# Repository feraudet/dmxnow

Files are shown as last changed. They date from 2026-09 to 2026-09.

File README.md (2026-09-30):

# dmxnow

Wireless DMX and LED strip nodes over ESP-NOW, driven by QLC+ from a Raspberry Pi.
One mains cable per fixture: DMX arrives by radio, the node switches the fixture's
power and drives 4 LED strip channels.

Nœuds DMX et rubans LED sans fil, sur ESP-NOW, pilotés par QLC+ depuis un Raspberry Pi.
Un seul câble secteur par projecteur : le DMX arrive par radio, le nœud coupe
l'alimentation du projecteur et pilote 4 canaux de rubans LED.

| | |
|---|---|
| 🇬🇧 **[Read in English](README.en.md)** | context, the need, use cases, how it works, status |
| 🇫🇷 **[Lire en français](README.fr.md)** | contexte, besoin, cas d'usage, fonctionnement, état du projet |

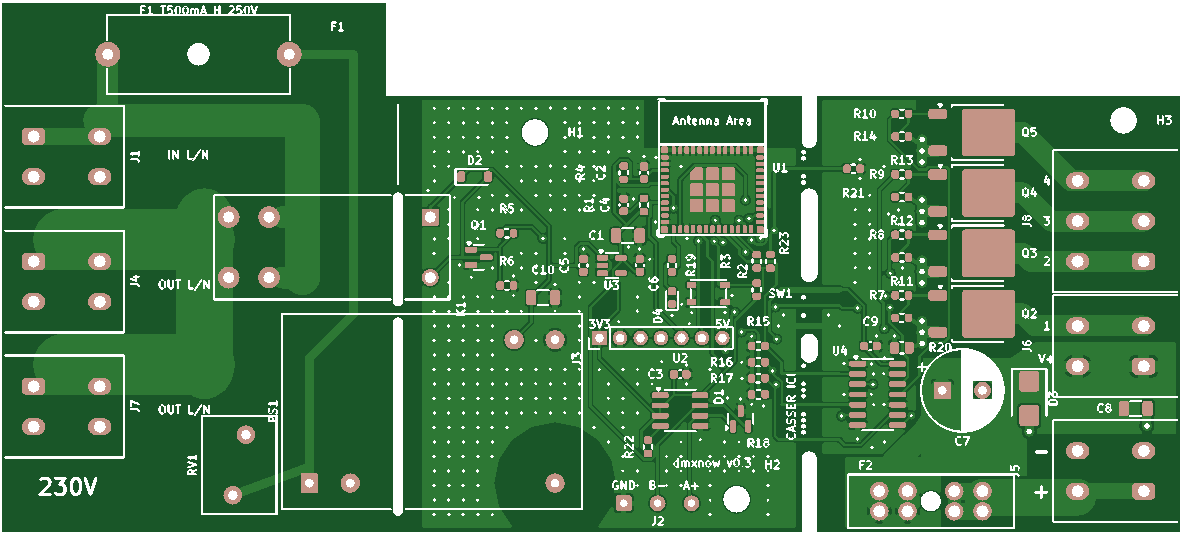
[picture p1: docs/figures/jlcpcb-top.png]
dmxnow board v0.3 (JLCPCB render)


🔴 230 V mains device: read [docs/securite.md](docs/securite.md) first.
Appareil raccordé au 230 V : lire [docs/securite.md](docs/securite.md) avant tout.

Hardware CERN-OHL-S-2.0, software GPL-3.0-or-later: [LICENSE](LICENSE).

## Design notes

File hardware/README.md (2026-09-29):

# dmxnow : matériel

PCB du nœud : 2 couches, cuivre 2 oz, **146 × 54 mm** plus une bande de 47,5 × 11,5 mm
au-dessus de la zone 230 V (porte-fusible F1), séparation à X = 100 mm par fente fraisée
et trois languettes perforées (partie principale « projecteur » 100 × 54 mm, partie
sécable « rubans » 46 × 54 mm). Révision 0.3 (après revue de conception, voir
`REVIEW.md`).

> 🔴 Carte manipulant du 230 V : lire et compléter [REVIEW.md](REVIEW.md) avant toute
> commande ou mise sous tension. Les cotes de K1 (Omron G5RL-1A-E-HR), des borniers WAGO
> 2604 et de PS1 (Mean Well IRM-03-5) ont été relevées sur les fiches constructeur
> ([datasheets/README.md](datasheets/README.md)) ; leur contrôle fait partie de la relecture.

## Contenu

| Fichier | Rôle |
|---|---|
| `gen/design.py` | **Source unique** : composants, empreintes, broches → nets, classes de nets |
| `gen/footprints.py` | Empreintes du projet (`lib/dmxnow.pretty`), cotes et sources dans `DIMS` |
| `gen/sch.py` | Génère `dmxnow.kicad_sch` (schéma à étiquettes, symboles embarqués) |
| `gen/project.py` | Génère `dmxnow.kicad_pro` (classes de nets) et `dmxnow.kicad_dru` (règles 230 V) |
| `gen/pcb.py` | Génère `dmxnow.kicad_pcb` : contour, fentes, languettes perforées, placement, routage 230 V et LED, plans |
| `gen/route.py` | Routage des signaux basse tension par Freerouting, vias d'échappement et de couture GND |
| `gen/fixup.py` | Passe de finition : ferme les liaisons laissées par le routeur (segments directs, vias vers les plans) |
| `gen/vendor.py` | Copie figée des symboles et empreintes KiCad utilisés (`lib/vendor/`) |
| `gen/check.py` | Contrôles de cohérence : netlist du schéma, pastilles du PCB, traversée de la découpe |
| `gen/drc.py` | DRC local via l'API pcbnew (KiCad 7+) |
| `gen/fab.py` | Sorties JLCPCB dans `fab/` |
| `lib/` | Bibliothèques : `dmxnow.pretty`, `Espressif.*` (espressif/kicad-libraries, CC-BY-SA 4.0) |
| `REVIEW.md` | Liste de contrôle de la relecture humaine |

Ne pas éditer les fichiers KiCad à la main : modifier les scripts et régénérer (un
changement manuel serait écrasé et rendrait la CI rouge).

## Régénérer

Prérequis : KiCad ≥ 7 (module Python `pcbnew`, `kicad-cli`), Java ≥ 17, Freerouting
(`FREEROUTING_JAR`, défaut `/opt/freerouting/freerouting.jar`).

```sh
cd hardware
make lib sch project   # empreintes, schéma, projet et règles
make pcb route         # PCB puis routage automatique + finition (~15 min)
make check             # netlist, cohérence PCB, DRC local
make fab               # Gerbers, perçages, BOM/CPL JLCPCB
```

`make pcb` repart de zéro : il faut relancer `make route` ensuite (ou `make reimport`
pour réappliquer la dernière session Freerouting si aucun composant n'a bougé).
Freerouting n'est pas déterministe : deux passages donnent des routages différents,
toujours validés par `make check`.

## Contrôles

- **Local** (KiCad 7) : `make check` (netlist schéma = `design.py`, pastilles PCB =
  `design.py`, seuls PWM1-4, BOARD_SENSE, +5V, GND traversent la découpe et uniquement
  sur les languettes, aucune piste 230 V au-delà de X = 46 mm, aucun via dans une
  pastille CMS, DRC, puis `gen/drc_canary.py` : des défauts injectés doivent déclencher
  chaque règle 230 V, preuve que les règles personnalisées sont chargées).
- **CI** (`.github/workflows/hardware.yml`, KiCad 9) : fichiers générés à jour, ERC, DRC
  avec parité schéma/PCB, sorties de fabrication, rendus 3D dessus/dessous (artefact
  `dmxnow-hardware`).

## Règles d'isolement (🔴)

Définies dans `gen/project.py` → `dmxnow.kicad_dru` :

| Règle | Valeur |
|---|---|
| Cuivre 230 V ↔ tout autre cuivre ou trou | ≥ 6 mm |
| Entre nets 230 V | ≥ 3 mm |
| Pastilles internes de K1 (COM/NO) et de PS1 (AC) | ≥ 2 mm (imposé par le composant) |
| Cuivre 230 V ↔ bord de carte | ≥ 1 mm |

Géométrie : cuivre 230 V à X ≤ 46 mm, basse tension à X ≥ 52 mm, fentes de 1,2 mm à
X = 49 mm sous K1 et PS1, aucun cuivre à moins de 6 mm de la pastille NC de PS1 (rangée
AC du module). Aucun trou de fixation dans la zone 230 V. Le PE ne passe pas
par la carte (WAGO 221-413 dans le boîtier, arbitrage A9).

## Commande JLCPCB

Dossier pas à pas (réglages, remarque, aperçu, achats hors JLCPCB) : [`ORDER.md`](ORDER.md).

- `fab/dmxnow-gerbers.zip` : 2 couches, 1,6 mm, **2 oz**, FR-4 TG ≥ 150.
- Séparation : fente et perforations sont dans les Gerbers (Edge.Cuts, NPTH). JLCPCB
  compte la carte comme **2 designs** : « Different Design = 2 », « Panel by Customer »
  1×1, « Remove order number = Yes ». Remarque de commande :
  « One circuit with an internal routed slot and 3 breakaway tabs carrying traces; deliver and assemble as one piece, do NOT separate. SMT: convey on the straight short edges X=0 and X=146; U1/Q5/R10 are close to the Y=54 edge by design. J3, J2 not populated: keep holes open (no solder fill). J1, J4, J7, J5, J6, J8: wire entry toward board edge; J6 and J8 side by side. RV1: form leads to the PCB holes. F2: press flat before soldering. F1/F2 fuses are not fitted. »
- Assemblage complet (CMS + traversants, PCBA « Standard ») : `fab/bom_jlcpcb_full.csv`
  + `fab/cpl_jlcpcb_full.csv` ; CMS seuls (PCBA « Economic », traversants à la main) :
  `*_smt.csv`. Suffixe `_led` : avec la LED d'état (option A7). Positions et rotations
  converties aux conventions JLCPCB (`gen/fab.py`, `JLC_FIX`) ; contrôler l'aperçu de
  placement à la commande. Références LCSC vérifiées le 2026-09-26 (le WAGO 2604-1105 arrêté est
  remplacé par J6 2604-1102 + J8 2604-1103). La cartouche de F1 (Littelfuse 0215.500MXP) et le fusible de F2
  sont à insérer à la main.
- Composants traversants et hors carte : `fab/bom_full.csv`.

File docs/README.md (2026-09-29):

# Documentation dmxnow (livrable 8.7)

Un réseau DMX sans fil : QLC+ sur un Raspberry Pi envoie de l'Art-Net au démon `dmxnowd`,
qui le transmet par USB à un **dongle** ESP32-C3 ; le dongle diffuse les univers en
ESP-NOW à des **nœuds**. Chaque nœud rend une ligne DMX filaire vers un projecteur,
commute son alimentation 230 V par un relais et, sur la carte entière, pilote quatre
canaux de rubans LED 12/24 V.

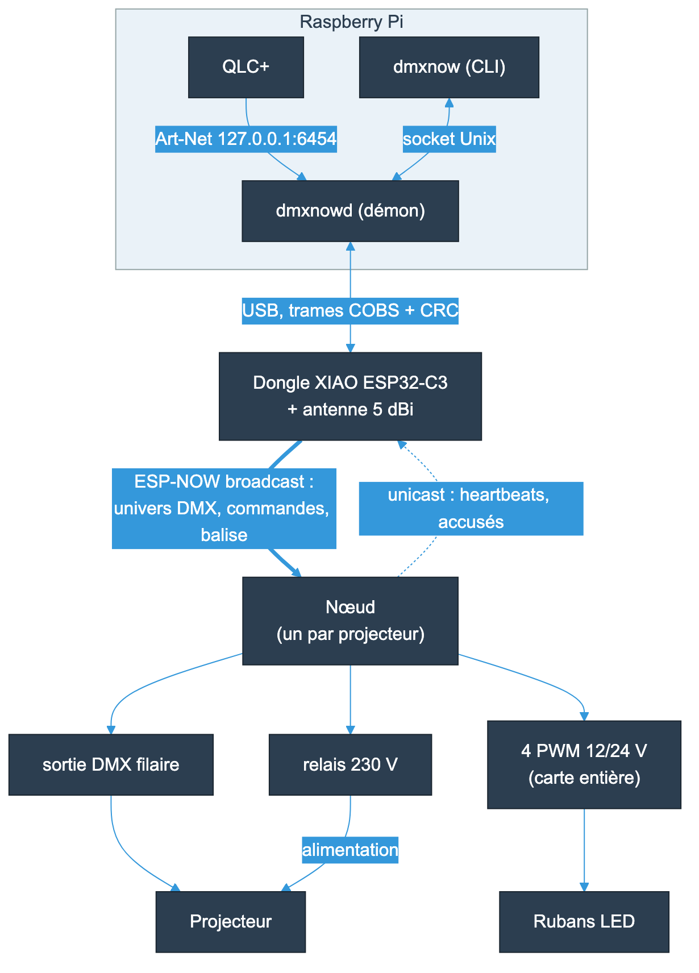
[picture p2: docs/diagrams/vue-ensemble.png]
Vue d'ensemble : QLC+, démon, dongle, nœuds


🔴 **Le nœud est raccordé au secteur.** Lire [securite.md](securite.md) avant toute
manipulation ; ce document et la liste de contrôle qu'il contient demandent une
**relecture humaine obligatoire** par une personne qualifiée.

Carte du nœud

Carte dmxnow v0.3, face top (rendu JLCPCB)

## Ordre de lecture

| # | Document | Pour qui, pour quoi |
|---|---|---|
| 0 | [fonctionnement.md](fonctionnement.md) | **Comprendre** : principes, radio, nœud, relais, rubans, commandes, maintenance, options (illustré) |
| 1 | [securite.md](securite.md) 🔴 | Tout le monde : règles, essais du prototype, **liste de contrôle avant mise sous tension** |
| 2 | [assemblage.md](assemblage.md) | Réception des cartes, fusibles, découpe de la partie rubans, impression et montage du boîtier, dongle |
| 3 | [flash.md](flash.md) | Premier chargement du firmware (nœud par J3, dongle par USB-C), mises à jour OTA |
| 4 | [cablage.md](cablage.md) | Raccordement secteur, DMX, alimentation LED et rubans |
| 5 | [mise-en-service.md](mise-en-service.md) | Pi, QLC+, enrôlement des nœuds, maintenance, dépannage |

Le flash se fait **avant** le câblage secteur : un nœud se programme hors secteur, par
ses pastilles J3 (règle 2 de securite.md).

## Références

| Sujet | Source |
|---|---|
| Exigences, arbitrages, points à valider | [spec/SPEC.md](../spec/SPEC.md), [spec/adr/](../spec/adr/) |
| Protocole radio et série | [spec/PROTOCOL.md](../spec/PROTOCOL.md) |
| Carte, commande JLCPCB, relecture 230 V | [hardware/README.md](../hardware/README.md), [ORDER.md](../hardware/ORDER.md), [REVIEW.md](../hardware/REVIEW.md) 🔴 |
| Boîtiers (nœud, dongle) | [enclosure/README.md](../enclosure/README.md) |
| Firmware, recette sur banc | [firmware/README.md](../firmware/README.md) |
| Démon et CLI | [pi/README.md](../pi/README.md) |

## Vocabulaire

| Terme | Sens |
|---|---|
| Carte entière / partie principale | La carte livrée (146 mm) porte la partie « projecteur » et la partie sécable « rubans » ; cassée, il reste la partie principale (100 mm) |
| Univers | Univers Art-Net (Port-Address 0 à 32767), 512 canaux DMX |
| `net_id` | Numéro de réseau choisi par `install.sh` ; un nœud neuf a `net_id` 0 |
| Enrôlement | Rattacher un nœud neuf au réseau (`dmxnow enroll`) |
| Maintenance | Point d'accès Wi-Fi `dmxnow-<nom>` + page web + OTA sur un nœud |
| TBTS | Très basse tension de sécurité (SELV) : < 60 V DC, isolée du secteur |

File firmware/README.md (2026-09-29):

# Firmware dmxnow

| Dossier | Contenu |
|---|---|
| `common/` | Bibliothèque C++17 sans Arduino : protocole v1 (en-tête, validation, CRC16, COBS), configuration TLV, réassemblage, compteur de pertes, logique du relais, gamma, cadence d'émission, HMAC-SHA256 et anti-rejeu, historique des commandes. Tests natifs. |
| `common/test_vectors.json` | Vecteurs communs (PROTOCOL §9), produits par `common/tools/gen_vectors.py` avec une implémentation Python indépendante ; consommés par les tests C++ et, plus tard, par ceux du démon Pi. |
| `node/` | Firmware du nœud, ESP32-C3-MINI-1, Arduino-ESP32 3.3.12 / ESP-IDF 5.5.5 (pioarduino 55.03.312, épinglé). |
| `dongle/` | Firmware du dongle, Seeed XIAO ESP32-C3 sur l'USB du Pi (même plateforme épinglée). |

## Compiler et tester

```
pip install platformio
cd firmware/common && pio test -e native        # 36 tests (nœud + dongle), -Wall -Wextra -Werror
cd firmware/node && pio run -e node             # firmware.bin (OTA) et firmware.factory.bin
cd firmware/dongle && pio run -e dongle         # XIAO ESP32-C3
python3 firmware/common/tools/gen_vectors.py    # après toute évolution du protocole
```

Derrière un proxy TLS d'entreprise, PlatformIO passe son propre bundle `certifi` et
ignore `REQUESTS_CA_BUNDLE` : ajouter le certificat du proxy à ce bundle plutôt que de
désactiver la vérification.

## Flasher un nœud

- Relier un câble USB aux pastilles **J3** : **5V** (pastille 7), GND, D−, D+.
  **Jamais J3-3V3** (sortie du régulateur, courant inverse non garanti) et jamais avec
  le secteur branché (REVIEW 7.6).
- Maintenir SW1 pendant la mise sous tension : chargeur ROM (mode téléchargement).
- `pio run -e node -t upload`, ou `firmware.factory.bin` à l'adresse 0x0 avec esptool.
- Ensuite : mises à jour par OTA depuis la page de maintenance. La nouvelle image est
  **confirmée au premier paquet radio valide** ; sans paquet dans les 60 s, le chargeur
  revient à l'ancienne. Faire les OTA à portée du dongle.

## Mise en service (nœud neuf)

1. Un nœud neuf a `net_id` = 0 : il n'accepte ni DMX ni rien d'autre que des COMMAND et
   des BEACON, de n'importe quel réseau (enrôlement, PROTOCOL §2.5). Son heartbeat part en
   broadcast avec `net_id` 0.
2. Depuis le Pi : `SET_CONFIG` avec `net_id`, `universe`, `start_address`, `name`,
   `dmx_out_slots` (régler à l'adresse de fin du projecteur, arbitrage A3), puis
   `net_key` (A4) : dès lors, toute commande sauf `IDENTIFY` doit être authentifiée.
3. Sans console : page de maintenance (SW1 ≥ 3 s, ou 3 mises sous tension en moins de 5 s
   chacune), point d'accès `dmxnow-<nom>`, mot de passe `maint_password` (aléatoire au
   premier démarrage, affiché sur la console USB J3 au démarrage et à l'entrée en
   maintenance ; à redéfinir de préférence à l'enrôlement :
   `dmxnow set <nœud> maint_password=…`, 8 à 32 caractères), puis http://192.168.4.1/.

## Comportements (où les trouver)

| Fonction | Spécification | Code |
|---|---|---|
| Validation des paquets dans le callback, copie en file | PROTOCOL §2.5 | `node/src/radio.cpp`, `common/src/protocol.cpp` |
| DMX : break 176 µs par inversion de ligne, MAB 12 µs, 250 kbit/s 8N2, `dmx_out_slots` | SPEC 4.4, A3 | `node/src/dmx_out.cpp` |
| Émission sur événement (≥ 10 ms d'écart) + rafraîchissement 44 Hz | PROTOCOL §4.4 | `common/src/dmx.cpp` (`OutputCadence`) |
| Réassemblage v1, fusion partielle | PROTOCOL §4.2 | `common/src/dmx.cpp` (`Reassembler`) |
| Relais : priorités, niveau ≥ 128, anti-rebond différé, NVS seulement à la commutation | SPEC 4.5 | `common/src/relay.cpp`, `node/src/node.cpp` |
| PWM : LEDC 14 bits à 4882 Hz, déphasage d'un quart de période, gamma, fondu | SPEC 4.6-4.7 | `node/src/pwm_out.cpp`, `common/src/gamma.cpp` |
| PWM à 0 avant tout le reste au démarrage | SPEC 4.7 | `node::setup()` |
| Variante par BOARD_SENSE | EF-07 | `node::setup()` |
| Heartbeat 2 s ± 250 ms, immédiat sur événement | PROTOCOL §5.1 | `node/src/node.cpp` |
| Apprentissage / oubli (30 s) du dongle | PROTOCOL §5.3 | `node/src/node.cpp` |
| Commandes, idempotence (16 derniers `cmd_id`), ACK unicast | PROTOCOL §6 | `node/src/node.cpp`, `common/src/auth.cpp` |
| Authentification HMAC + compteur persistant | PROTOCOL §7, A4 | `common/src/auth.cpp` |
| Balayage des canaux après 60 s sans réseau | SPEC 4.1, A5 | `node/src/node.cpp` |
| SW1 : ≥ 3 s maintenance, ≥ 10 s remise à zéro | SPEC 4.9, A6 | `node/src/node.cpp` |
| LED d'état (option) | SPEC 4.9, A7 | `node/src/node.cpp` |
| Maintenance AP+STA, page web, OTA avec retour arrière | SPEC 4.9 | `node/src/maintenance.cpp` |

## Recette sur banc (SPEC 8.3) : à faire sur les premières cartes

| # | Essai | Moyen | Critère |
|---|---|---|---|
| B1 | Trame DMX : break, MAB, débit, 2 bits de stop, longueur `dmx_out_slots` | Analyseur logique sur DI du SP3485 (IO4) et sur A/B | break ≥ 88 µs (176 visé), MAB ≥ 8 µs (12 visé), 4 µs/bit |
| B2 | Cadence : trame immédiate sur donnée nouvelle, ≥ 10 ms d'écart, 44 Hz sans donnée | Analyseur ; dongle ou émetteur de test | intervalle break-break conforme |
| B3 | Relais : suit le canal (≥ 128), forçage, intervalle minimal 3 s différé, état au démarrage, perte de flux sans effet | Commandes + DMX | SPEC 4.5 points 1 à 5 |
| B4 | PWM : fréquence 4882 Hz, 14 bits, déphasage d'un quart de période entre canaux, gamma, fondu à la mise sous tension | Oscilloscope 4 voies sur IO3/6/7/10 | décalages 51 µs (¼ de 205 µs) |
| B5 | PWM à 0 dès la mise sous tension (pas d'impulsion) | Oscilloscope déclenché sur l'alimentation 5 V | aucune impulsion avant l'initialisation |
| B6 | Perte de flux : dernière trame conservée ; blackout après `loss_blackout_ms` si configuré | Couper le dongle | EF-06 |
| B7 | Maintenance : SW1 3 s, 3 mises sous tension, commande ; réception ESP-NOW maintenue en AP+STA [V-FW-05] ; sortie par page, par SW1, par délai | Téléphone + DMX | le DMX continue d'être rafraîchi |
| B8 | OTA : mise à jour par la page ; retour arrière si aucun paquet valide en 60 s | Deux images | l'ancienne image redémarre |
| B9 | Changement de canal par commande (appliqué 500 ms après l'ACK) ; balayage après 60 s sans réseau | Dongle sur un autre canal | le nœud retrouve le réseau et persiste le canal |
| B10 | Authentification : commande non signée refusée (`AUTH_FAILED`) une fois la clé posée, rejeu refusé, `IDENTIFY` toujours accepté | Démon Pi | PROTOCOL §7 |

## Dongle

- Liaison USB CDC avec le démon (PROTOCOL §8) : trames COBS, CRC16, `seq` par émetteur ;
  `UNIVERSE`, `COMMAND` (remorque d'authentification calculée par le Pi), `DONGLE_CONFIG`
  (persisté en NVS), `PING` → `PONG`, `GET_STATUS` → `STATUS` (aussi toutes les 5 s).
- Émission ESP-NOW **une à la fois** (attente du callback d'émission, garde de 50 ms),
  priorité COMMAND > DMX_DATA > BEACON (1 Hz, même sans univers) ; univers émis sur
  événement (≥ 10 ms d'écart) et rafraîchis à `refresh_hz` (44), arrêtés après
  `hold_timeout` (10 s) sans données du Pi ; mode v1 fragmenté sélectionnable.
- Commandes : ciblées, 5 tentatives (attentes 30, 60, 120, 240 ms puis 50 ms) jusqu'à
  l'ACK de la bonne MAC ; broadcast, 3 émissions à 20 ms puis 1 s de collecte ;
  `CMD_RESULT` au Pi. HEARTBEAT et ACK remontés en `RADIO_RX` (paquet brut) ; les
  heartbeats des nœuds non configurés (`net_id` 0) sont acceptés pour l'enrôlement.
- Sonde de latence : **D10 (GPIO10)** bascule à chaque émission radio (ENF-01).
- Logique testée nativement : `common/src/dongle.cpp`, `common/src/serial.cpp`.

### Recette dongle (SPEC 8.4)

| # | Essai | Critère |
|---|---|---|
| D1 | Latence Art-Net → ligne DMX : QLC+ → démon → dongle (sonde D10) → nœud (analyseur sur IO4) | ≤ budget SPEC §5.1 (≈ 3,3 ms typique en trame courte) |
| D2 | Débit USB : 4 univers à 50 Hz sans perte (`serial_errors`, `coalesced`) [V-FW-04] | aucune erreur série |
| D3 | Pi débranché : univers maintenus 10 s puis BEACON seul | `hold_timeout` |
| D4 | Commande ciblée vers un nœud éteint : 5 tentatives, `CMD_RESULT` = expiré | < 0,5 s |

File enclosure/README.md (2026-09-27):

# Boîtier dmxnow (livrable 8.6)

🔴 **RELECTURE HUMAINE OBLIGATOIRE** : cloison 230 V, accès aux borniers, matériau
(SPEC §4.12, ES-05).

Modèle CadQuery paramétrique (`enclosure.py`), deux variantes :

| Variante | Carte | Encombrement hors tout (parois + bossages + oreilles) | Corps seul |
|---|---|---|---|
| `full` | carte entière (146 × 65,5 mm) | 208 × 88 × 34 mm | 208 × 72 × 34 mm |
| `cut` | partie principale seule (carte cassée) | 150 × 88 × 34 mm | 145 × 72 × 34 mm |

L'objectif ENF-05 (≤ 150 × 65 × 45 mm entière, ≤ 110 × 65 × 45 mm cassée) **n'est pas
tenu en longueur ni en largeur**, voir « Écarts » ci-dessous.

## Fichiers

| Fichier | Rôle |
|---|---|
| `board.json` | Géométrie de la carte (contour, fentes, trous, encombrement et hauteur de chaque composant, points d'appui), **générée** par `hardware/gen/export_board.py` |
| `enclosure.py` | Modèle, vérifications (SPEC §8.6), exports |
| `render.py` | Rendus PNG assemblés (fermé, ouvert) |
| `out/<variante>/*.step` | Pièces en position d'assemblage (CAO) |
| `out/<variante>/*.stl` | Pièces en position d'impression (trancheur) |
| `out/<variante>/assembly_*.png` | Rendus |

```
pip install -r requirements.txt       # CadQuery 2.8
make                                  # vérifie, exporte les deux variantes, rend les PNG
make check                            # vérifications seules
```

Après toute modification du PCB : `cd hardware/gen && python3 export_board.py`, puis
`make` ici.

## Pièces imprimées

| Pièce | Qté | Orientation | Rôle |
|---|-----|---|---|
| `base` | 1 | fond sur le plateau | Fond, parois, cloison 230 V / TBT, supports du PCB, presse-étoupes, sellette de l'étrier, clip du WAGO 221-413, passants de colliers |
| `cover_230v` | 1 | face lisse sur le plateau | 🔴 Couvercle d'accès aux borniers secteur (J1, J4, J7, jonction PE), vissé ; jupe de cloison au-dessus du PCB ; recouvre le bord du couvercle TBT |
| `lid_lv` | 1 | face lisse sur le plateau | Couvercle basse tension, vissé ; guide du poussoir SW1 ; aérations au-dessus des MOSFET (`full`) |
| `lid_lv_light_pipe` | (1) | idem | Variante de `lid_lv` avec le logement du guide de lumière Ø 3 mm au-dessus de D4 (option A7) |
| `clamp_bar` | 3 | rainure sur le plateau | Barres d'étrier (arrêt de traction indépendant du presse-étoupe, ES-05) |
| `sw1_plunger` + `sw1_collar` | 1 + 1 | debout | Poussoir captif de SW1 (A6) : le collier se colle ou s'emmanche sous le tube de guidage |

## Achats

| Article | `full` | `cut` | Note |
|---|---|---|---|
| Presse-étoupe M16 × 1,5 plastique + contre-écrou (serrage 4,5 à 10 mm) | 5 | 3 | Secteur ×3 (H05VV-F 3G1,5 ≈ 8 à 9 mm), rubans ×1, alimentation LED ×1 [V-ENC-01] |
| Presse-étoupe M12 × 1,5 plastique + contre-écrou (serrage jusqu'à 7 mm) | 1 | 1 | Queue DMX (câbles DMX souvent 6 à 6,5 mm, au-delà du PG7) [V-ENC-01] |
| Insert fileté M3 à chaud, Ø 4,0 × 5,7 mm | 16 | 15 | 8 couvercles, 6 étriers, 1 ou 2 PCB |
| Vis M3 × 6 tête cylindrique | 8 | 8 | Couvercles (lamage de 1,2 mm) |
| Vis M3 × 16 | 6 | 6 | Barres d'étrier (pas plus long : la vis toucherait le fond de l'insert avant de serrer) |
| Vis M3 × 6 + rondelle isolante | 2 | 1 | PCB (H2, H3) |
| WAGO 221-413 | 1 | 1 | Jonction des trois PE (A9) |
| Guide de lumière Ø 3 mm (PMMA) | option | option | A7 |
| Filament **ABS-FR ou PC-ABS-FR UL94 V-0** | ~150 g | ~115 g | Pièces pleines (masse volumique 1,2) [V-ENC-02] 🔴 |

## Impression

- Matériau **UL94 V-0 (au minimum V-1)** : PETG et ABS standard (HB) interdits pour une
  enveloppe contenant du secteur (SPEC §4.12). Conserver la fiche technique du filament
  et l'épaisseur à laquelle le classement est donné ; l'épaisseur des parois (2,5 mm) doit
  être au moins égale à celle-ci [V-ENC-02].
- Parois pleines : **100 % de remplissage** (ou périmètres suffisants pour remplir les 2,5 mm).
- Imprimante fermée, buse 240 à 260 °C, plateau 100 °C (ABS-FR) ; bordure (« brim ») sur
  le fond (R-15).
- Aucun support nécessaire : trous horizontaux en goutte d'eau tronquée, porte-à-faux ≤ 45°.

## Montage

1. Inserts à chaud dans les bossages (couvercles), la sellette (étriers) et les plots H2/H3.
2. Clipser le WAGO 221-413 dans son logement (chambre de gauche).
3. Poser le PCB : l'ergot imprimé traverse H1, les languettes de la cloison entrent dans
   les fentes d'isolement ; visser H2 (et H3 sur la carte entière).
4. Presse-étoupes : écrous tournés méplat contre méplat (les trois écrous secteur sont
   espacés de 21,5 mm pour 22 mm sur angles).
5. Câbles secteur : gaine serrée par le presse-étoupe **et** par la barre d'étrier ; PE
   au 221-413 d'abord, puis L et N aux WAGO 2604 ; conducteurs sans tension mécanique.
6. Poussoir SW1 : glisser le poussoir dans le tube par-dessous, emmancher le collier.
7. Visser le couvercle TBT, puis le couvercle 230 V (il recouvre le bord du couvercle TBT).

## Choix de conception (justifications)

- **Chambres de câblage** : un contre-écrou de presse-étoupe M16 (22 mm sur angles) ne peut
  pas traverser le plan du PCB ; les WAGO étant en bord de carte, les presse-étoupes sont
  dans des chambres aux extrémités. Côté secteur, la chambre (34 mm) contient l'écrou,
  l'étrier (ES-05) et la zone d'épanouissement des conducteurs avec le 221-413 (A9).
- **Cloison 230 V / TBT** 🔴 : une cloison continue du fond au couvercle est impossible sur
  la ligne X = 49 mm, que K1 et PS1 enjambent. Elle est réalisée en trois parties :
  (1) paroi du fond, pleine hauteur hors carte (bande de F1) et sous la carte ailleurs ;
  (2) languettes de 0,8 mm qui remplissent les fentes d'isolement du PCB ; (3) jupe du
  couvercle 230 V au-dessus de la carte, qui descend à 0,5 mm du PCB et passe à 0,5 mm
  au-dessus de K1 et PS1 (leurs boîtiers assurent l'isolement à cet endroit). Le couvercle
  230 V recouvre le bord du couvercle TBT (« lèvre »).
- **H1 sans métal** : H1 est à 13,5 mm de la zone d'antenne ; il reçoit un ergot imprimé
  et un tube presseur du couvercle au lieu d'un insert (SPEC : rien de métallique à moins
  de 15 mm de l'antenne). Pour la même raison, la variante `cut` n'a pas de vis dans le
  coin supérieur droit.
- **Points d'appui** : plots sous le PCB et presseurs des couvercles aux points calculés
  par `export_board.py` (≥ 3 mm des pastilles, ≥ 2,5 mm des composants).
- **Aérations** (R-08) : fentes dans le couvercle TBT au-dessus de Q2 à Q5 et entrées
  basses dans la paroi, sous la partie sécable. Aucune ouverture dans le couvercle 230 V.
- **DMX en M12** plutôt que PG7 : plage de serrage jusqu'à 7 mm (câbles DMX 6 à 6,5 mm).

## Écarts et points à valider

| Point | État |
|---|---|
| ENF-05 (≤ 150 × 65 × 45 / ≤ 110 × 65 × 45) | **Non tenu** : 208 × 72 × 34 (corps, `full`), 145 × 72 × 34 (`cut`). Longueur : chambres de presse-étoupes + étriers (ES-05). Largeur : bande de F1 (carte de 65,5 mm) + parois. Hauteur tenue. |
| Hauteurs de F2 avec fusible (21 mm), C7 (17,5 mm), RV1 (16 mm) | Estimées, à mesurer sur les pièces [V-ENC-03] |
| Presse-étoupes : diamètres de câbles, plages de serrage, dimensions des contre-écrous | [V-ENC-01] |
| Filament V-0, épaisseur certifiée | [V-ENC-02] 🔴 |
| Jupe de cloison au-dessus de K1 / PS1 (0,5 mm) : suffisante avec les boîtiers des composants ? | Relecture humaine 🔴 |
| Tenue du PCB : 1 vis (H2) + ergot H1 + appuis ; la partie sécable (`full`) ajoute H3 | À éprouver sur prototype (effort de levier des WAGO) |

## Vérifications automatiques (`make check`)

- solides valides (`isValid()`) et fermés ;
- aucune intersection des pièces avec le PCB ni avec l'enveloppe des composants
  (empreinte × hauteur) ;
- carte + 0,5 mm contenue dans la cavité ;
- parois ≥ 2,5 mm, fond et couvercles ≥ 2,0 mm ;
- contre-écrous des presse-étoupes : hors du PCB, des composants, dans la hauteur ;
  ouverture en goutte d'eau couverte par l'écrou ;
- aucun métal (inserts, vis) à moins de 15 mm de la zone d'antenne.

## Boîtier du dongle (`dongle_case.py`)

Boîtier de la **Seeed XIAO ESP32-C3** (référence 113991054) avec une **antenne dipôle
vissée** sur une embase RP-SMA, retenu à la place d'une clé USB-A toute faite pour garder
une antenne externe (SPEC 4.10). Encombrement : **59 × 39 × 13 mm**, oreilles comprises
(corps 48 × 25 × 13 mm).

Achats (Kiwi Electronics, 2026-09-27) :

| Article | Code | Note |
|---|---|---|
| Seeed XIAO ESP32C3 | SS-113991054 | |
| Câble **RP-SMA** vers u.FL, 14 cm, embase à visser | KW-1518 | pas le « SMA to u.FL » : SMA et RP-SMA ne se connectent pas |
| Antenne dipôle 2,4 GHz **RP-SMA** 5 dBi | ANT-24GHZ-5DBI | rayonne surtout à l'horizontale : la tenir verticale |

| Pièce | Orientation | Rôle |
|---|---|---|
| `out/dongle/tray` | fond sur le plateau | Ouverture USB-C avec lamage pour la fiche, nervures et butée du XIAO, trou Ø 6,6 mm de l'embase RP-SMA dans une paroi de 2,5 mm, place pour lover le câble, oreilles pour un collier |
| `out/dongle/lid` | face gravée sur le plateau | Lèvre à clipser (échancrée au-dessus de l'embase), deux appuis sur les bords du PCB |

- **Matériau** : PETG ou PLA (5 V USB seulement, pas de secteur : pas d'exigence V-0).
- **Montage** : XIAO poussé contre la paroi USB-C ; embase RP-SMA passée de l'intérieur
  dans la paroi opposée, rondelle et écrou à l'extérieur ; câble clipsé sur le
  connecteur U.FL du XIAO, lové en une boucle d'au moins 18 mm de diamètre ; couvercle
  clipsé ; antenne vissée à la main.
- **Utilisation** : câble USB-C vers USB-A sur le Pi, avec une rallonge ; dongle suspendu
  par son câble USB (ou par un collier dans une oreille), antenne vers le bas, verticale.
- **Flash** : par l'USB-C, sans ouvrir le boîtier (l'USB Serial/JTAG de l'ESP32-C3 passe
  en mode téléchargement tout seul) ; les boutons BOOT et RESET ne sont pas accessibles.

Cotes à confirmer sur les pièces reçues [V-ENC-04] : épaisseur du PCB (1,2 mm prévu),
dépassement de l'USB-C au-delà du bord (1,0 mm prévu), hauteur des composants
(3,4 mm prévu), corps de l'embase RP-SMA côté intérieur (Ø 9,4 × 9 mm prévu), filetage
1/4"-36 (trou Ø 6,6 mm). Ce sont des paramètres en tête de `dongle_case.py`.

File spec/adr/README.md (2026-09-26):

# Architecture Decision Records

Format : Statut, Contexte, Décision, Conséquences, Alternatives écartées.

Les ADR 0001 à 0010 reprennent les décisions de la section 3 du cahier des charges. Les ADR 0011 à 0015 sont issus de la spécification ; 0011, 0014 et 0015 ont été tranchés par arbitrage le 2026-09-25.

| ADR | Titre | Statut |
|-----|---|---|
| [0001](0001-transport-esp-now.md) | Transport radio ESP-NOW | Accepté (cahier des charges, décision 1) |
| [0002](0002-regie-pi-dongle.md) | Régie Raspberry Pi + QLC+ + dongle XIAO ESP32-C3 | Accepté (décision 2) |
| [0003](0003-microcontroleur-esp32-c3-mini-1.md) | Microcontrôleur ESP32-C3-MINI-1 | Accepté (décision 3) |
| [0004](0004-alimentation-isolee.md) | Alimentation interne isolée Mean Well IRM-03-5 | Accepté (décision 4 amendée par A1) |
| [0005](0005-relais-g5rl.md) | Relais de coupure Omron G5RL-1A-E-HR | Accepté (décision 5, amendée) |
| [0006](0006-rubans-alim-externe-pwm.md) | Rubans LED : alimentation externe, 4 PWM côté masse | Accepté (décision 6) |
| [0007](0007-pcb-secable.md) | PCB unique sécable (languettes perforées) | Accepté (décision 7, amendée) |
| [0008](0008-borniers-wago-2604.md) | Borniers WAGO série 2604 | Accepté (décision 8) |
| [0009](0009-relais-par-canal-dmx.md) | Commande du relais par un canal DMX | Accepté (décision 9) |
| [0010](0010-boitier-imprime-3d.md) | Boîtier imprimé 3D paramétrique | Accepté (décision 10) |
| [0011](0011-esp-now-v2-trame-unique.md) | ESP-NOW v2, un univers par paquet, plateforme pioarduino | Accepté (arbitrage A8, 2026-09-25) |
| [0012](0012-liaison-serie-cobs.md) | Liaison série Pi ↔ dongle encadrée COBS + CRC16 | Accepté (validation de la spec, 2026-09-25) |
| [0013](0013-commandes-broadcast-ack.md) | Commandes en broadcast avec acquittement applicatif | Accepté (validation de la spec, 2026-09-25) |
| [0014](0014-trames-dmx-evenement.md) | Émission DMX sur événement et longueur de trame configurable | Accepté (arbitrage A3 : défaut 512, 2026-09-25) |
| [0015](0015-authentification-commandes.md) | Authentification des commandes par HMAC tronqué | Accepté (arbitrage A4, 2026-09-25) |

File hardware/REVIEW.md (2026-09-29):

# Relecture humaine du PCB dmxnow

> 🔴 **RELECTURE HUMAINE OBLIGATOIRE avant toute commande et toute mise sous tension.**
> Ce PCB a été conçu et routé par script. Les contrôles automatiques (ERC, DRC avec
> règles 230 V personnalisées, cohérence netlist) ne remplacent pas la relecture d'une
> personne qualifiée en électronique de puissance et en sécurité électrique.

Cocher chaque ligne, noter le nom du relecteur et la date. Tout point non conforme
bloque la commande.

Relecteur : ____________________  Date : ____________  Révision PCB : 0.3

## 1. Empreintes (bloquant)

Les cotes de K1, des WAGO 2604 et de PS1 ont été relevées sur les fiches constructeur
(liste et liens : `datasheets/README.md`) et sont centralisées dans `gen/footprints.py`
(dictionnaire `DIMS`, avec la page source). Les confronter aux fiches et, idéalement, à
une pièce réelle posée sur une impression 1:1 du PCB.

| Réf. | Composant | Cotes relevées | Source | OK |
|---|---|---|---|----|
| K1 | Omron G5RL-1A-E-HR DC5 (LCSC C113250) | Bobine 1/8 → A1 (0 ; 0) et A2 (7,5 ; 0), COM 3/6 → 13 en (0 ; 20) et (7,5 ; 20), NO 4/5 → 14 en (0 ; 25) et (7,5 ; 25), perçage 1,3 mm, corps 29,0 × 12,7 × 15,7 mm max. Bobine 80 mA / 62,5 Ω, isolation renforcée 8 mm / 10 kV. **Ne pas accepter de G5RL-U1A-E (bistable).** | Catalogue Omron G5RL p. 5 | ☐ |
| J1, J4, J7, J5, J6 | WAGO 2604-1102 (LCSC C3309286) | Pas 5,0 mm, 2 broches par pôle à 8,2 mm, perçage 1,4 mm (fiche : 1,3 +0,1 ; tolérance JLCPCB −0,08), broche 0,8 × 1 mm, pastilles 2,0 × 2,8 mm, corps 16,3 mm (broche avant à 5,2 mm de la face d'entrée, arrière à 2,9 mm du dos), levier 2,9 mm en saillie, largeur 12,4 mm. Le corps dépasse le bord du PCB de 1,4 mm (J1, J4, J7) et 0,7 mm (J5, J6). | Fiche WAGO 2604-1102 p. 2 | ☐ |
| J6, J8 | WAGO 2604-1102 (C3309286) + 2604-1103 (C3309758) | Même série ; le 2604-1105 (5 pôles) est arrêté. Deux blocs côte à côte : 7,4 mm mini entre broches voisines (L = (n − 1) × 5 + 7,4 mm), 8,0 mm au PCB (CH1 y 28,5 → CH2 y 20,5). | Fiche WAGO 2604-1102 p. 2 ; fiche 2604-1103 | ☐ |
| PS1 | Mean Well IRM-03-5 (LCSC C6969425) | Empreinte KiCad `Converter_ACDC_MeanWell_IRM-03-xx_THT` conforme : AC/L (1), AC/N (3) à 5,08 mm, NC (5) à 30,48 mm, −Vo (14) et +Vo (16) à 17,78 mm, broches Ø 0,6 mm, corps 37 × 24 × 15 mm. | Fiche IRM-03 (2025-08-08) p. 4 | ☐ |
| F1 | Support Schurter 0031.8201 (LCSC C3204125) + cartouche Littelfuse 0215.500MXP (T500 mA H, céramique, 1500 A sous 250 V AC, LCSC C142839, à insérer à la main) | Empreinte KiCad `Fuseholder_Cylinder-5x20mm_Schurter_0031_8201_Horizontal_Open` : broches à 22,5 mm, ergot NPTH de 2,7 mm. Vérifier sur la fiche Schurter. Support ouvert : pièces nues sous 230 V dans le compartiment secteur. | Schurter | ☐ |
| RV1 | 10D561K (LCSC C113236, HEL série 10D) | Empreinte du projet `RV_Disc_D12mm_T9mm_P7.5mm_Drill1.1` : perçage 1,1 mm (pattes 0,8 ± 0,1 mm ; le 0,8 mm de KiCad était trop juste), corps jusqu'à 9 mm d'épaisseur (fiche, rangée 430-560 V). Vérifier l'épaisseur réelle de la pièce livrée. | Fiche HEL 10D | ☐ |
| PS1 (trous) | IRM-03-5 | Empreinte du projet `Converter_ACDC_MeanWell_IRM-03-xx_THT_Drill1.0` : perçages 1,0 mm (broches Ø 0,6 ± 0,1 mm ; les 0,76-0,8 mm de KiCad étaient trop justes avec la tolérance JLCPCB), mêmes positions et pastilles. | Fiche IRM-03 p. 4 | ☐ |
| U1 | ESP32-C3-MINI-1 | Empreinte officielle Espressif (kicad-libraries), zone d'exclusion d'antenne incluse. Vérifier la version de l'empreinte. | Espressif | ☐ |
| F2 | Porte-fusible ATO | Empreinte KiCad Littelfuse FLR 178.6165 ; vérifier l'intensité admissible (≥ 20 A) et la disponibilité. | Littelfuse | ☐ |

Si une cote diffère : corriger `DIMS`, relancer `make lib pcb route check fab`.

## 2. Isolement 230 V / basse tension 🔴

| # | Point | Référence | OK |
|---|---|---|----|
| 2.1 | Toute pièce de cuivre 230 V (nets L_IN, L_SW, N, L_PSU) est à X ≤ 46 mm ; tout cuivre basse tension à X ≥ 52 mm (6 mm). Vérifié par la règle DRC `mains_to_low_voltage` et par `check.py pcb` ; contrôler visuellement sur les Gerbers. | SPEC 4.8.2 | ☐ |
| 2.2 | Fentes de 1,2 mm à bouts arrondis à X = 49 mm sous K1 (Y 12-26) et sous PS1 (Y 27,5-52), entre broches AC et DC de PS1 et entre contacts et bobine de K1. | SPEC 4.8.2 | ☐ |
| 2.3 | Distance bobine-contacts de K1 (interne au relais) ≥ distance requise pour l'isolation renforcée : la fiche Omron annonce une isolation renforcée, 8 mm dans l'air et en ligne de fuite, 6000 V AC, choc 10 kV (à confronter à IEC 62368-1, V-HW-11). | V-HW-03 | ☐ |
| 2.4 | Isolation entrée-sortie de PS1 certifiée (IEC/UL 62368-1) : marquage d'homologation présent sur la pièce achetée. | V-HW-09 | ☐ |
| 2.5 | Aucun plan de masse, via, piste ou trou métallisé basse tension dans la zone 230 V, sur les deux faces. | SPEC 4.8.2 | ☐ |
| 2.6 | Aucun trou de fixation dans la zone 230 V (une vis métallique annulerait l'isolement). | design.py | ☐ |
| 2.7 | Ligne de découpe (X = 100 mm, fente + 3 languettes perforées) : aucun cuivre 230 V à moins de 4 mm, aucun composant à moins de 4 mm ; seuls PWM1-4, BOARD_SENSE, +5V et GND la traversent, sur les languettes. | SPEC 4.8.4, `check.py pcb` | ☐ |
| 2.8 | Distances entre nets 230 V ≥ 3 mm, sauf exceptions acceptées : pastilles COM/NO de K1 (2,4 mm, fixées par le relais) et broches AC de PS1 (2,93 mm, fixées par le module). Règle `mains_pad_to_pad_inside_components`, limitée aux pastilles de K1 et de PS1. | SPEC 4.8.2 | ☐ |
| 2.10 | Broche 5 (NC) de PS1 : elle est sur la rangée AC du module ; traitée comme primaire : aucun cuivre à moins de 6 mm du bord de la pastille (règle DRC `ps1_nc_pin`, zone interdite `ps1_nc_keepout`). Confirmer auprès de Mean Well qu'elle n'est reliée à rien (ou mesurer : continuité et essai diélectrique). | SPEC 4.3 | ☐ |
| 2.11 | F1 : fusible céramique à haut pouvoir de coupure (1500 A) ; ne jamais le remplacer par un fusible en verre (35 A). | SPEC 4.3 | ☐ |
| 2.9 | Le PE ne passe pas par le PCB : les trois conducteurs PE sont réunis par un WAGO 221-413 dans le compartiment 230 V du boîtier (arbitrage A9). | SPEC 4.12 | ☐ |

## 3. Chemins de puissance

| # | Point | Référence | OK |
|---|---|---|----|
| 3.1 | Chemin de charge L_IN → K1 → L_SW : L_IN 4 à 4,3 mm sur les deux faces ; L_SW en doigts de 7,4 mm et bus de 7 mm sur la face avant. Col de 1,9 mm sur ≤ 8 mm aux broches des borniers (imposé par le pas de 5 mm). Juger l'échauffement à 16 A. | SPEC 4.8.3, A2 | ☐ |
| 3.2 | N : bus de 7,1 mm et doigts de 3,4 à 4 mm en face arrière ; col de 3,4 mm sur ~8 mm entre J1 et le bus (~30 °C à 16 A selon IPC-2221, à mesurer au thermocouple). Juger l'échauffement à 16 A (estimation IPC-2221 : ≤ 10 °C sur le bus, ~25 °C sur les cols). | SPEC 4.8.3 | ☐ |
| 3.3 | Branche L_PSU / N vers PS1 et RV1 : 1 mm (courant < 50 mA, protégée par F1). | - | ☐ |
| 3.4 | Partie rubans : VLED en plan (face avant), GND_LED en plan (face arrière), VLED_IN 4,5 mm, canaux 2,5 mm (6 A). | SPEC 4.6 | ☐ |
| 3.5 | Sources des MOSFET (AOD2610E, 60 V) reliées au plan GND_LED par 3 vias de 0,6 mm chacune ; vérifier la capacité (≈ 4 à 6 A par MOSFET). | - | ☐ |
| 3.7 | F2 : fusible ATO chargé à ≤ 80 % de son calibre en continu (20 A pour ≤ 16 A, sinon 25 A ; support 30 A). Polarité de J5 marquée « + / − » : une inversion met D3 en court-circuit. VLED ≤ 28 V. | SPEC 4.6, V-HW-08 | ☐ |
| 3.8 | Courant d'appel des charges sur J4/J4b ≤ ~80 A crête (G5RL-1A-E-HR : 100 A) : mesuré sur les charges réelles. | V-SYS-01 | ☐ |
| 3.6 | GND logique et GND_LED reliées en un seul point : R20 (0 Ω 0805) près de U4. BOARD_SENSE relié à GND par R21 (0 Ω) sur la partie sécable. Plans : GND logique (deux faces, X 100-113) et GND_LED (face arrière, X ≥ 113) séparés. | SPEC 4.8.4 | ☐ |

## 4. Basse tension

| # | Point | OK |
|---|---|----|
| 4.1 | Antenne de U1 en bord de carte, aucune piste, via ni plan dans la zone d'exclusion (règle `antenna_keepout`), rien de métallique au-dessus dans le boîtier. | ☐ |
| 4.2 | Découplage : C2 (100 nF) contre la broche 3V3 de U1 ; C1 (47 µF) à ~17 mm de piste (0,2 mm de large, ~20 mΩ, ~20 nH : acceptable à 0,45 A crête, à confirmer par une mesure de l'ondulation pendant l'émission Wi-Fi) ; C3 contre U2 ; C9 contre U4. Les pistes +5V/+3V3 routées font 0,2 mm (Freerouting n'applique pas la classe PWR). | ☐ |
| 4.3 | Pull-ups de démarrage R2 (IO9), R3 (IO8), R4 (IO2), RC d'EN (R1, C4). R15-R18 4,7 kΩ (GPIO6 a une résistance de tirage interne au reset), R22 10 kΩ sur DMX_TX, R23 100 kΩ sur BOARD_SENSE. | ☐ |
| 4.4 | SW1 accessible par le poussoir du couvercle ; J3 accessible couvercle basse tension ouvert. | ☐ |
| 4.5 | Échauffement de U3 (AP2112K) : cuivre suffisant autour de la broche GND (plan). | ☐ |
| 4.6 | Routage automatique (Freerouting) : longueur et aspect des pistes USB (D-/D+) acceptables pour la programmation. | ☐ |
| 4.7 | Plan de masse : la face arrière porte encore ~280 mm de pistes basse tension (PWM4 et RELAY_CTRL surtout) qui la découpent par endroits ; chaque pastille CMS de masse a son via. Juger la qualité du retour de masse sous U1 (radio) et sous le chemin DMX. | ☐ |

## 5. Fabrication

| # | Point | OK |
|---|---|----|
| 5.1 | JLCPCB : 2 couches, 1,6 mm, **cuivre 2 oz**, FR-4 TG ≥ 150, finition HASL sans plomb ou ENIG. | ☐ |
| 5.2 | Séparation : fente fraisée et trous de perforation inclus dans les Gerbers (Edge.Cuts, NPTH). Préciser en remarque de commande : « single design, internal routed slot with breakaway tabs, do not separate ». JLCPCB la compte comme **2 designs** : commander avec « Different Design = 2 », « Panel by Customer » 1×1. Remarque de commande complète : « One circuit with an internal routed slot and 3 breakaway tabs carrying traces; deliver and assemble as one piece, do NOT separate. SMT: convey on the straight short edges X=0 and X=146; U1/Q5/R10 are close to the Y=54 edge by design. J3, J2 not populated: keep holes open (no solder fill). J1, J4, J7, J5, J6, J8: wire entry toward board edge; J6 and J8 side by side. RV1: form leads to the PCB holes. F2: press flat before soldering. F1/F2 fuses are not fitted. » | ☐ |
| 5.3 | Fentes d'isolement de 1,2 mm (bouts arrondis) présentes sur le calque Edge.Cuts. | ☐ |
| 5.4 | BOM et CPL (`fab/*_full.csv` pour CMS + traversants, `*_smt.csv` pour CMS seuls) : références LCSC vérifiées le 2026-09-26 (revérifier le stock, en particulier 2604-1103 pour J8). Rotations et centres convertis aux conventions JLCPCB (`fab.py`, `JLC_FIX`) ; F1 (support Schurter) vérifié sur l'empreinte EasyEDA C3204125 ; rotations des composants à contrôler dans l'aperçu JLCPCB. | ☐ |
| 5.5 | Composants traversants (WAGO, K1, PS1, F1, RV1, F2, C7) soudés à la main ou en assemblage traversant. | ☐ |

## 6. Essais du premier prototype (personne équipée et qualifiée)

1. Inspection visuelle, continuité, absence de court-circuit L/N, L/basse tension, N/basse tension.
2. Essai diélectrique secteur ↔ basse tension (toutes broches TBT reliées) : 3 kV AC ou
   4,2 kV DC pendant 60 s, sans claquage.
3. Première mise sous tension derrière un transformateur d'isolement et un disjoncteur
   différentiel 30 mA, charge résistive.
4. Essai de charge : 10 A pendant 1 h, relevé thermique (pistes, relais, borniers) ;
   essai de courte durée à 16 A.
5. Commutation d'une alimentation LED réelle (courant d'appel), 1000 cycles.

## 7. Commande et montage

| # | Point | OK |
|---|---|----|
| 7.1 | J6 + J8 (2604-1102 + 2604-1103, remplaçant le 2604-1105 arrêté) sont dans les fichiers JLCPCB : vérifier dans l'aperçu que les deux blocs sont côte à côte et orientés comme J5. | ☐ |
| 7.2 | RV1 : l'empreinte JLCPCB de C113236 écarte les pattes de 6 mm latéralement (la nôtre 1,63 mm, pas de 7,5 mm identique) : JLCPCB mettra les pattes en forme, vérifier l'aperçu. | ☐ |
| 7.3 | Languettes de séparation : ~15 mm de FR-4 plein au total sur la ligne de rupture (les trous s'interrompent au droit des pistes) ; prévoir scie ou pince coupante plutôt qu'une rupture à la main. | ☐ |
| 7.4 | Mise en route : démarrage à froid répété, ligne DMX terminée par 120 Ω, à la tension secteur mini et maxi (limite de courant repliée de l'AP2112K) ; F1 face à l'appel de courant de PS1. | ☐ |
| 7.5 | Rubans : charge totale ≤ 16 A en continu avec le fusible F2 de 20 A (≤ 80 %) ; polarité de J5 (une inversion avec une alimentation limitée en courant fait chauffer D3 sans fondre F2). | ☐ |

| 7.6 | Programmation hors secteur : alimenter par **J3-5V** (pastille 7, entrée de U3), jamais par J3-3V3 (sortie de U3, courant inverse non garanti) ; ne pas alimenter J3-5V secteur branché. | ☐ |
| 7.7 | Bornier WAGO : sens d'insertion (levier côté bord de carte, entrée des fils vers l'extérieur) à contrôler sur l'aperçu JLCPCB ; F2 (porte-fusible ATO conçu pour 1,5 mm) plaqué avant soudure ; trous de J2 et J3 laissés ouverts. | ☐ |
| 7.8 | Remarque de commande : voir 5.2 (2 designs, convoyage par les bords courts X=0 / X=146, pièce unique non séparée). | ☐ |

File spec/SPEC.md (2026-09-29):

# dmxnow : Spécification

Statut : **v1.0, validée le 2026-09-25** (arbitrages A1 à A8 tranchés, A6 révisé : bouton SW1 + option 3 coupures, remise à zéro par appui de 10 s). Aucune implémentation ne démarre
avant validation de ce document, de [PROTOCOL.md](PROTOCOL.md) et des [ADR](adr/).

Conventions :
- 🔴 **RELECTURE HUMAINE OBLIGATOIRE** : section touchant au 230 V ou à la sécurité des
  personnes ; à faire relire par une personne qualifiée (électricien ou électronicien de
  puissance) avant fabrication et avant toute mise sous tension.
- **[ARBITRAGE Ax]** : point qui a fait l'objet d'un arbitrage (décisions en §9).
- **[V-xx]** : hypothèse non vérifiée, listée en §10 avec la source à consulter.
- Identifiants d'exigence : `EF-` fonctionnelle, `ENF-` non fonctionnelle, `ES-` sécurité.

---

## 1. Objet et périmètre

Système de diffusion DMX sans fil pour installations scénographiques : derrière chaque
projecteur, un seul câble secteur. Un nœud monté sur le cordon reçoit l'univers DMX par
ESP-NOW, le restitue en DMX filaire, commute l'alimentation du projecteur et, en version
carte entière, pilote 4 canaux PWM de rubans LED alimentés par une alimentation externe.

Dans le périmètre : PCB, firmware nœud, firmware dongle, démon Pi, boîtier, documentation.

Hors périmètre (repris du cahier des charges) : compatibilité CRMX/W-DMX, RDM,
alimentation LED intégrée, Wi-Fi/Art-Net en exploitation (Wi-Fi seulement en
maintenance), commande indépendante projecteur/rubans (un seul relais), plusieurs dongles
sur un même réseau, codes de départ DMX non nuls.

---

## 2. Exigences

### 2.1 Fonctionnelles

| ID | Exigence |
|---|---|
| EF-01  | Le démon Pi reçoit l'Art-Net émis par QLC+ sur 127.0.0.1 (UDP 6454) et sur les interfaces configurées, et répond aux ArtPoll. sACN (E1.31) optionnel. |
| EF-02  | Le démon transmet chaque univers configuré au dongle par USB (PROTOCOL §8), gère la déconnexion et la reconnexion du dongle. |
| EF-03  | Le dongle diffuse chaque univers en ESP-NOW broadcast selon la règle « événement + 44 Hz minimum » (PROTOCOL §4.4) et continue d'émettre la dernière trame pendant `hold_timeout` (défaut 10 s) si le Pi se tait. |
| EF-04  | Le nœud filtre par `net_id` et univers, rejette les paquets invalides, réassemble en mode fragmenté. |
| EF-05  | Le nœud émet en continu une trame DMX512 sur UART1, TX = GPIO4, rafraîchie à ≥ 44 Hz, émission déclenchée à l'arrivée de données nouvelles. |
| EF-06  | Sur perte de flux, le nœud conserve la dernière trame ; blackout optionnel après `loss_blackout_ms` (défaut désactivé). Le relais n'est jamais affecté par la perte de flux. |
| EF-07  | Au démarrage, le nœud détecte sa variante par BOARD_SENSE (GPIO1 à la masse = partie rubans présente). |
| EF-08  | Relais (GPIO5) commandé par le canal DMX `start_address` (≥ 128 = allumé), par commande ESP-NOW (forçage / automatique) et en maintenance ; intervalle minimal entre commutations (défaut 3 s) ; état à la mise sous tension configurable (défaut : dernier état). |
| EF-09  | Variante rubans : 4 sorties PWM LEDC ≥ 4 kHz, ≥ 12 bits, gamma configurable, 8 ou 16 bits DMX par canal, PWM forcé à 0 avant toute autre action au démarrage, fondu configurable à l'allumage. |
| EF-10  | Le nœud émet un HEARTBEAT périodique (PROTOCOL §5.1). |
| EF-11  | Configuration persistante (univers, adresse, nom, canal radio, etc.) modifiable par commande ESP-NOW (PROTOCOL §6.4). |
| EF-12  | Mode maintenance (commande ESP-NOW, bouton SW1 accessible boîtier fermé, ou 3 mises sous tension rapprochées si activé) : point d'accès Wi-Fi, page de configuration, mise à jour OTA, retour automatique en exploitation. |
| EF-13  | CLI Pi : liste des nœuds (nom, MAC, variante, univers, adresse, RSSI, pertes, relais, uptime, version), identification, changement d'univers/adresse/nom, relais, maintenance, configuration du dongle. Page web minimale optionnelle. |
| EF-14  | Identification d'un nœud monté et fermé sans démontage (PROTOCOL `IDENTIFY`). |

### 2.2 Non fonctionnelles

| ID | Exigence | Vérification |
|---|---|---|
| ENF-01 | Latence Art-Net → début d'émission des canaux du projecteur sur la ligne DMX < 10 ms (typique), mesurée hors quantification interne de QLC+. | Calcul §5.1 ; mesure à l'analyseur logique (GPIO de marquage dongle + ligne DMX). |
| ENF-02 | Rafraîchissement DMX ≥ 44 Hz, pas de trou > 100 ms en conditions nominales. | Mesure, compteur `lost_frames`. |
| ENF-03 | Taux de perte radio < 1 % à 20 m en vue directe, 4 univers actifs. | Mesure heartbeat. |
| ENF-04 | Coût matière ≤ 50 € par nœud en série de 20 (hors alimentation LED, hors XLR si fournie). | BOM chiffrée §6. |
| ENF-05 | Boîtier ≤ 150 × 65 × 45 mm (carte entière), ≤ 110 × 65 × 45 mm (cassée). Objectif, à confirmer après placement. **Non tenu, accepté par l'utilisateur le 2026-09-27** : 208 × 72 × 34 mm (entière), 145 × 72 × 34 mm (cassée), hors oreilles et bossages ; longueur : chambres de presse-étoupes et étriers imposés par ES-05, largeur : bande de F1 (§4.12, « Réalisation »). | STEP. |
| ENF-06 | Nœud configurable, identifiable et mis à jour sans ouverture du boîtier. | Recette. |
| ENF-07 | Reproductibilité : tout est généré par scripts versionnés ; CI verte. | CI. |

### 2.3 Sécurité 🔴 RELECTURE HUMAINE OBLIGATOIRE

| ID | Exigence |
|---|---|
| ES-01  | Isolation renforcée entre tout conducteur 230 V et la basse tension accessible (DMX, rubans, programmation) : lignes de fuite ≥ 6 mm, distances dans l'air ≥ 6 mm sur la carte (objectif de conception supérieur au minimum normatif, §4.8.2). |
| ES-02  | Alimentation interne isolée (PS1). Aucune liaison galvanique entre secteur et masse DMX. |
| ES-03  | Continuité du PE entre l'entrée et les deux sorties, sans interruption par le relais. Le PE ne passe pas par le PCB : jonction par un WAGO 221-413 dans le compartiment 230 V (arbitrage A9). |
| ES-04  | Branche d'alimentation interne protégée par F1 (T500 mA céramique 5×20, pouvoir de coupure 1500 A sous 250 V) et RV1. Chemin de puissance protégé par le disjoncteur amont : dimensionnement du cuivre en conséquence (arbitrage A2). |
| ES-05  | Boîtier en matériau au moins UL94 V-1 (V-0 recommandé), borniers 230 V accessibles uniquement après retrait d'un couvercle vissé (outil requis), cloison entre zones, arrêts de traction sur tous les câbles secteur. |
| ES-06  | Aucun 230 V ne traverse ni n'approche à moins de 4 mm la ligne de découpe. |
| ES-07  | Aucune programmation ni mesure avec le secteur raccordé (procédure documentée), sauf équipement de test isolé explicitement prévu. |
| ES-08  | Toute la partie rubans est TBTS (< 60 V DC) et alimentée par une alimentation certifiée à sortie isolée. |

---

## 3. Architecture

### 3.1 Système

Système : Raspberry Pi, dongle, nœuds

### 3.2 Nœud

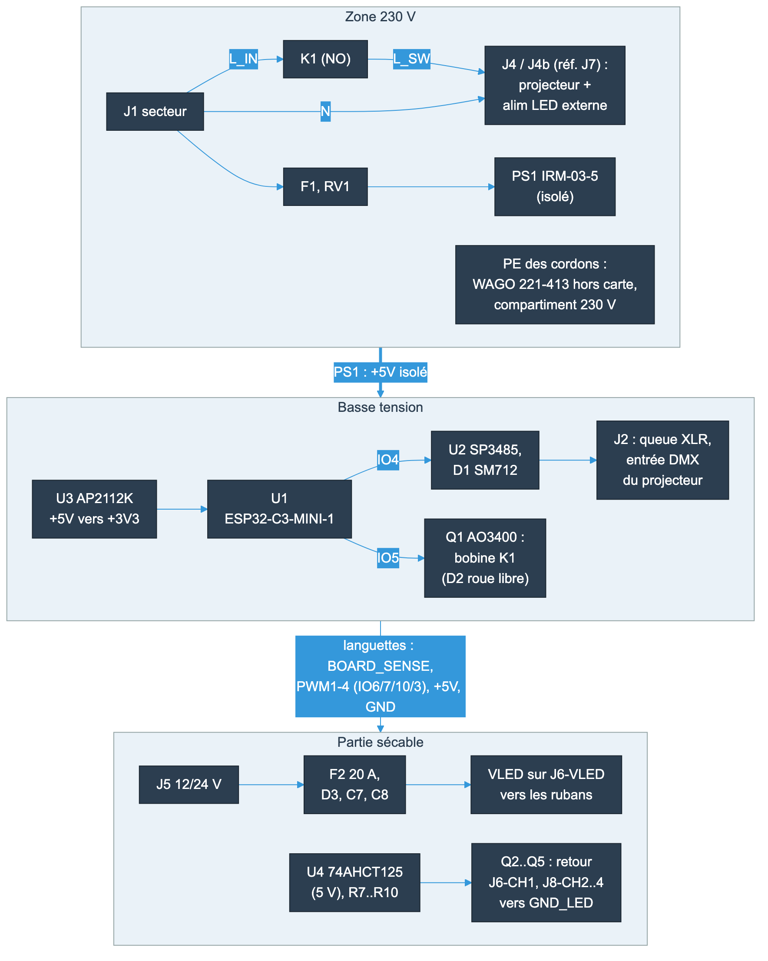
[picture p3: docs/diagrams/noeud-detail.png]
Schéma fonctionnel détaillé du nœud


### 3.3 Répartition du code

| Composant | Langage / cadre | Contenu |
|---|---|---|
| `firmware/common`  | C++17, sans dépendance Arduino | En-tête, CRC16, COBS, codec TLV, réassemblage, anti-rebond relais, table gamma, compteur de pertes. Testé nativement (`pio test -e native`). |
| `firmware/node` | PlatformIO, Arduino-ESP32 3.x (pioarduino) | Tâches radio, DMX, contrôle, maintenance. |
| `firmware/dongle`  | idem | Série USB, ordonnanceur d'émission, suivi des commandes. |
| `pi/` | Python ≥ 3.11, asyncio, `pyserial` | Démon `dmxnowd`, CLI `dmxnow`, systemd, udev, installeur. |
| `hardware/` | Python (génération directe `.kicad_sch` / `.kicad_pcb`, API pcbnew), Freerouting, `kicad-cli` | Schéma, placement, routage, ERC/DRC, sorties JLCPCB. |
| `enclosure/` | CadQuery | Boîtier paramétrique deux longueurs. |

---

## 4. Choix techniques justifiés

### 4.1 Radio (ADR 0001, 0011)

ESP-NOW v2, un paquet par univers, broadcast, canal fixe, débit PHY 6 Mbit/s par défaut.
Voir PROTOCOL §2 et le calcul §5.

Mode Wi-Fi des nœuds : STA non associée, `WIFI_PS_NONE` (l'économie d'énergie
introduirait des latences de l'ordre de l'intervalle de balise, 100 ms). Protocoles
802.11b/g/n activés.

**Repli sur changement de canal [ARBITRAGE A5, retenu]** : un nœud qui ne reçoit plus
aucun paquet de son réseau depuis 60 s balaie les canaux 1 à 13 (écoute 300 ms par canal)
jusqu'à retrouver son `net_id` (DMX_DATA ou BEACON), puis adopte ce canal et le persiste.
La dernière trame DMX continue d'être émise pendant le balayage. Évite qu'un nœud reste
orphelin après un changement de canal manqué. Aucun coût matériel.

### 4.2 Microcontrôleur et affectation des broches (ADR 0003)

ESP32-C3-MINI-1 (flash intégrée 4 Mo, antenne PCB intégrée). GPIO11 à GPIO17 sont réservés
à la flash interne ; GPIO2, GPIO8 et GPIO9 sont des broches de configuration de démarrage
(*strapping*) [V-HW-02].

| GPIO | Fonction | Remarques |
|---|---|---|
| IO0 | STATUS_LED (option) | R19 330 Ω en série (LED rouge KT-0603R, VF ≈ 2,0 V, ~4 mA ; une LED verte InGaN VF ≈ 3 V ne s'allumerait pas sous 3,3 V), D4 LED CMS 0603 vers GND ; composants à monter en option [ARBITRAGE A7, option], §4.9 |
| IO1 | BOARD_SENSE | Entrée, R23 100 kΩ vers 3V3 sur la partie principale (+ pull-up interne) ; GND sur la partie rubans (R21 0 Ω) |
| IO2 | libre (strapping) | R4 10 kΩ pull-up, doit être haut au démarrage |
| IO3 | PWM4 | via U4 |
| IO4 | DMX_TX | UART1 TX vers SP3485 DI |
| IO5 | RELAY_CTRL | R5 vers grille Q1, R6 pull-down |
| IO6 | PWM1 | via U4 |
| IO7 | PWM2 | via U4 |
| IO8 | libre (strapping) | R3 10 kΩ pull-up, doit être haut pour le mode téléchargement |
| IO9 | BOOT / bouton SW1 | R2 pull-up, pastille J3-BOOT, SW1 vers GND (A6) |
| IO10 | PWM3 | via U4 |
| IO18/19| USB D−/D+ | J3 |
| IO20/21| UART0 | non connectés (console via USB CDC) |

Point important : **GPIO9 à la masse pendant le reset fait entrer l'ESP32-C3 dans le
chargeur ROM (mode téléchargement), pas dans notre firmware.** La demande « BOOT à la
masse au démarrage ⇒ maintenance » est donc reformulée : l'appui se fait **après** le
démarrage de l'application, sur le bouton SW1 (§4.9) ou la pastille J3-BOOT. Maintenir SW1
pendant la mise sous tension reste utile : c'est l'entrée du mode téléchargement ROM pour
un flash par J3. Autre entrée sans ouverture du boîtier : 3 mises sous tension rapprochées,
activable par configuration [ARBITRAGE A6, option], §4.9.

### 4.3 Alimentation basse tension et budget 🔴 RELECTURE HUMAINE OBLIGATOIRE (partie PS1)

PS1 **Mean Well IRM-03-5** : 85 à 264 V AC → 5 V, 600 mA (3 W), homologué IEC/EN/UL
62368-1 selon le fabricant [V-HW-09], environ 6 € **[ARBITRAGE A1, Mean Well retenu,
amende la décision 4]**. Raison : les modules Hi-Link (HLK-PM05, décision initiale) ont des
certifications difficiles à vérifier et sont souvent contrefaits ; pour un boîtier publié
et refabriqué par d'autres, un module certifié réduit le risque d'isolement (R-03).
L'IRM-05-5 envisagé d'abord a été écarté au placement (2026-09-25) : 45,7 × 25,4 × 21,5 mm
d'après l'empreinte KiCad, trop gros pour la zone 230 V et trop haut pour le boîtier.
L'IRM-03-5 a le même courant que le HLK-PM05 et un encombrement voisin. Principe inchangé
(module isolé, broches AC et DC séparées) ; F1 et RV1 conservés. **F1 (revue 2026-09-26)** :
le fusible TR5 (pouvoir de coupure 35 A) est remplacé par une cartouche céramique 5×20
temporisée T500 mA « H » (Littelfuse 0215.500MXP, 1500 A sous 250 V AC) dans un support
ouvert Schurter 0031.8201 : si RV1 finit en court-circuit (mode de défaillance usuel d'une
varistance), le courant de défaut du réseau dépasse largement 35 A. Le support est placé
dans une bande de 11,5 mm ajoutée au-dessus de la zone 230 V (seule place disponible ;
support de 10,8 mm d'emprise).
La broche 5 (NC) de PS1 est sur la rangée des broches AC du module : traitée comme
primaire : aucun cuivre à moins de 6 mm du bord de sa pastille (règle DRC `ps1_nc_pin`,
plus une zone interdite de 7,45 mm autour de son centre pour le routeur et les plans). C10 (47 µF) en
sortie de PS1 : Mean Well mesure l'ondulation avec 47 µF, et le +5 V porte la bobine du
relais et les pointes d'émission Wi-Fi. Le HLK-PM05 reste une empreinte de repli non
retenue [V-HW-01].

Budget sur +5 V (valeurs à confirmer en datasheet) :

| Consommateur | Moyen | Crête | Source |
|---|---|---|---|
| ESP32-C3 en réception continue + CPU 160 MHz (via U3) | ~100 mA | - | [V-HW-02] |
| ESP32-C3 en émission (heartbeats, brefs ; jusqu'à ~350 mA en 802.11b 20 dBm selon la fiche) | - | ~350 mA | [V-HW-02] |
| SP3485 pilotant une ligne terminée 120 Ω (via U3) | ~20 mA | ~35 mA (2 terminaisons) | [V-HW-06] |
| Bobine K1 5 V (≈ 400 mW) | ~80 mA  | ~80 mA  | [V-HW-03] |
| U4 (ΔICC 1,35-1,5 mA par entrée tenue à 3,3 V) + charges de grille (4 × Qg × fPWM) | ~7 mA | - | - |
| **Total** | **~200 mA** | **~470 mA** | ≤ 600 mA (IRM-03-5) : marge ~20 % en crête |

Régulateur U3 AP2112K-3.3 (600 mA, faible chute) : dissipation moyenne
(5 − 3,3) V × ~120 mA ≈ 0,2 W. En SOT-23-5 (RθJA de l'ordre de 150 à 250 °C/W selon le
cuivre), l'échauffement est de 30 à 50 °C : **acceptable seulement avec une surface de
cuivre 2 oz généreuse sur les broches GND/VOUT** et à vérifier par mesure (R-07).

### 4.4 Sortie DMX

- SP3485 alimenté en 3,3 V, DE et /RE à 3V3 : émetteur actif en permanence, récepteur
  désactivé (RO non connecté). Pas de polarisation (*fail-safe*) nécessaire puisque la
  ligne est toujours pilotée. **R22 10 kΩ de DMX_TX vers 3V3** (revue 2026-09-26) : GPIO4
  flotte pendant le reset et le démarrage alors que l'émetteur est actif ; R22 tient la
  ligne au repos (« mark ») et évite d'envoyer du bruit aux projecteurs à la mise sous
  tension.
- D1 SM712 : TVS asymétrique −7 V / +12 V adaptée à la plage de mode commun RS-485.
- **Pas de terminaison 120 Ω sur le nœud** : le nœud est l'émetteur, en tête de ligne ;
  la terminaison appartient à l'extrémité (bouchon sur la sortie THRU du projecteur si
  l'utilisateur chaîne, sinon inutile sur une queue de ≤ 1 m à 250 kbit/s, où le temps de
  propagation, ~5 ns, est négligeable devant le temps de bit, 4 µs).
- Masse DMX (J2-1) = GND du nœud, isolée du secteur par PS1. Côté projecteur, la broche 1
  est souvent reliée au châssis donc au PE : la masse du nœud se retrouve référencée au PE
  par le projecteur, ce qui est normal (un seul point de référence). Voir R-09 pour la
  boucle possible avec la masse des rubans.
- Pilote : bibliothèque `esp_dmx` (someweisguy) sur UART1, TX GPIO4. Compatibilité
  annoncée « ESP-IDF ≥ 4.4.1, Arduino-ESP32 ≥ 2.0.3 » ; la compatibilité avec
  Arduino 3.x / IDF 5.5 n'est pas explicitement annoncée [V-FW-03]. Repli : pilote
  UART maison (le DMX en émission seule est simple : break par
  `uart_write_bytes_with_break()` ou par inversion de ligne, MAB, 513 octets à 250 kbit/s,
  8N2), ~150 lignes, testable. La fonction `dmx_send_num()` d'esp_dmx permet l'émission
  de trames courtes.
- **Trames courtes [ARBITRAGE A3]** : voir §5.1 ; paramètre `dmx_out_slots`.

### 4.5 Relais 🔴 RELECTURE HUMAINE OBLIGATOIRE (partie contacts)

K1 Omron G5RL-1A-E-HR (LCSC C113250), bobine 5 V DC 80 mA / 62,5 Ω (~400 mW), contact NO
16 A 250 V AC, courant d'appel 100 A crête, isolation bobine-contacts renforcée (distances
dans l'air et lignes de fuite 8 mm, 6000 V AC, choc 10 kV) selon le catalogue Omron G5RL
(vérifié, `hardware/datasheets/omron-g5rl.pdf`). Le G5RL-U1A-E initialement retenu est un
relais **bistable** (deux bobines), incompatible avec la commande par MOSFET : remplacé par
le -1A-E-HR, même boîtier et même implantation (décision 5 amendée, ADR 0005). Q1 AO3400 (VGS(th) max 1,45 V, commandable
en 3,3 V), R5 100 Ω limite le courant de grille et amortit, R6 100 kΩ maintient Q1 bloqué
pendant le démarrage. D2 1N4148W en roue libre : la roue libre par simple diode ralentit
l'ouverture du contact (quelques ms), acceptable ici et même favorable (pas de rebond) ;
à confirmer que la vitesse d'ouverture n'aggrave pas l'érosion à la coupure de charges
capacitives (charges LED : l'usure se fait surtout à la fermeture, sur l'appel de courant).

Logique (implémentée dans `common`, testée) :
1. `desired` = état demandé par la source prioritaire : forçage par commande
   (`RELAY` 0/1) > canal DMX (si `relay_dmx` = 1 et flux présent) > état au démarrage.
   `RELAY 2` lève le forçage. Le forçage n'est pas persistant (perdu au redémarrage).
2. Le canal DMX agit sur **niveau** (≥ 128 allumé, < 128 éteint), pas sur front.
3. Anti-rebond : si `desired` ≠ état réel et que la dernière commutation date de moins de
   `relay_min_interval_ms`, la commutation est **différée** (pas ignorée) jusqu'à
   l'échéance ; c'est alors la dernière valeur de `desired` qui s'applique. Un
   clignotement DMX rapide produit donc au plus une commutation toutes les 3 s.
4. Perte de flux : le relais conserve son état (EF-06).
5. Persistance du dernier état : écriture NVS **uniquement** lors d'une commutation
   effective, regroupée avec `relay_switch_count`. Avec l'intervalle minimal de 3 s, le pire
   cas pathologique est de 1200 écritures/h ; la NVS répartit l'usure sur ses pages
   (partition 20 Ko = 5 pages de 126 entrées de 32 octets, ~100 000 cycles
   d'effacement par secteur) : plusieurs dizaines de millions d'écritures, soit des
   années même dans ce pire cas. Usage réel : quelques commutations par jour.

### 4.6 Sortie rubans (partie sécable)

- 4 MOSFET N côté masse **AOD2610E** (60 V ; RDS(on) ≤ 9,5 mΩ à VGS 10 V et ≤ 13,3 mΩ à
  4,5 V, Qgd 3,5 nC, fiche AOS vérifiée). Remplace l'AOD4184A (40 V) : l'écrêtage de D3
  (≈ 45 V) dépassait sa tenue (R-10, clos). Commande en 5 V par U4 74AHCT125 (entrées compatibles TTL, VIH 2 V,
  donc attaquables en 3,3 V ; sortie 5 V pour une meilleure saturation que 3,3 V).
  R15-R18 **4,7 kΩ** maintiennent les entrées de U4 à 0 pendant le démarrage ; /OE à GND.
  4,7 kΩ et non 100 kΩ (revue 2026-09-26) : GPIO6 (PWM1, MTCK) a une résistance de tirage
  interne de ~45 kΩ vers 3,3 V dès le reset tant que l'eFuse JTAG n'est pas brûlé (fiche
  ESP32-C3, tableau 2-1, note 6) ; avec 100 kΩ, l'entrée de U4 restait à ~2,3 V (> VIH) et
  le canal 1 s'allumait à chaque démarrage et en mode téléchargement.
  Au placement (2026-09-26), R15-R18 ont été mises **sur la partie principale**, juste
  avant la découpe, faute de place autour de U4 : même fonction (les nets PWM1-4 sont
  tenus à 0 dès la mise sous tension), et elles restent inoffensives sur une carte cassée
  (0,7 mA par GPIO inutilisée à l'état haut).
- Courant : 200 W sous 12 V = 16,7 A total, soit ~4,2 A par canal en RGBW équilibré ;
  on dimensionne chaque canal pour **6 A** et le cuivre pour 17 A ; charge continue totale
  limitée à **16 A** par le fusible F2 de 20 A (≤ 80 % de son calibre, V-HW-08).
- Pertes par MOSFET à 4,2 A : conduction I²R ≈ 4,2² × 0,010 ≈ 0,18 W ; commutation à
  4,9 kHz ≈ 0,1 à 0,2 W (Qgd 3,5 nC sous ~20 mA de grille : ~175 ns par front) ; total
  ≈ 0,3 à 0,4 W par MOSFET à 4,2 A (≈ 0,7 W à 6 A, RDS(on) à chaud). Cuivre de drain mesuré
  ≈ 0,85 cm² par canal (RθJA ≈ 80 °C/W) : ΔT ≈ 30 °C à 4,2 A, ≈ 55 °C à 6 A. Limiter
  `pwm_freq_hz` à ~5 kHz sous 24 V / 6 A. Sources reliées au plan GND_LED par 3 vias de
  0,6 mm. Aérations prévues au boîtier.
- **Ondulation dans C7** : les 4 canaux commutent jusqu'à 17 A en créneaux ; le courant
  alternatif absorbé par C7 peut dépasser plusieurs ampères efficaces, bien au-delà du
  courant d'ondulation admissible d'un 470 µF 35 V courant (~1 A). Mesures : (a) C7
  faible ESR, 105 °C, courant d'ondulation ≥ 2 A à 100 kHz : **Nichicon UHW1V471MPD**
  (2 A, 30 mΩ, 10 × 16 mm) [V-HW-08] ; (b) **déphasage
  des 4 PWM** (paramètre `hpoint` du LEDC décalé d'un quart de période par canal),
  sans coût matériel, qui étale les appels de courant et réduit fortement l'ondulation
  d'entrée. Justifié comme exigence firmware (EF-09).
- D3 SMBJ28A : tension de veille 28 V (compatible 24 V + 10 % ; VLED ≤ 28 V, ne pas
  régler une alimentation 24 V au-delà), tension d'écrêtage ≈ 45 V à Ipp, sous les 60 V
  des AOD2610E (R-10 clos). C7 (35 V) ne voit ces 45 V que pendant la surtension écrêtée
  (VBR min 31,1 V < 35 V) : accepté. Une inversion de polarité sur J5 met D3 en court-circuit
  franc : seul F2 protège, marquage « + / − » sérigraphié près de J5.
- Chemin VLED, retour GND_LED : 17 A, largeur de piste §4.8.3 ; F2, C7 et D3 collés à J5 ;
  retour de courant des rubans (J6/J8 → MOSFET → GND_LED → J5) entièrement dans la partie
  sécable.
- Borniers 17 A : WAGO 2604 32 A / 400 V (IEC, III/2), 20 A UL, 0,2-4 mm² (fiche WAGO
  2604-1102 vérifiée), largement suffisant.

### 4.7 PWM (firmware)

- LEDC de l'ESP32-C3 (horloge APB 80 MHz) : résolution maximale = log2(80 MHz / f).
  Défaut **4882 Hz en 14 bits** (80 MHz / 2¹⁴) ; à 19,5 kHz, 12 bits. La fréquence est
  configurable (`pwm_freq_hz`), la résolution déduite (≥ 12 bits imposé ⇒ f ≤ 19,5 kHz).
- Gamma : table précalculée à la configuration. 8 bits : 256 entrées → valeur 14 bits ;
  16 bits : 257 points + interpolation linéaire. `gamma_x10` = 10 donne une courbe linéaire.
- Démarrage : premières instructions du firmware = configurer les 4 broches PWM en sortie
  à 0 (si variante rubans), avant Wi-Fi, NVS ou DMX.
- Fondu `fade_on_ms` : appliqué au démarrage et à chaque passage du relais à « allumé »
  (l'alimentation LED externe redémarre), rampe linéaire en perception (sur la valeur
  avant gamma).
- Déphasage des 4 canaux (§4.6).

### 4.8 PCB 🔴 RELECTURE HUMAINE OBLIGATOIRE (zone 230 V, isolement, largeurs)

#### 4.8.1 Généralités

2 couches, FR-4 TG ≥ 150, cuivre 2 oz (70 µm) sur les deux faces, épaisseur 1,6 mm.
**Dimensions après placement (révisées le 2026-09-26, rév. 0.3) : 146 × 54 mm, plus une
bande de 47,5 × 11,5 mm au-dessus de la zone 230 V pour le porte-fusible F1 (encombrement
146 × 65,5 mm) ; séparation à X = 100 mm par fente fraisée de 2 mm et trois languettes
perforées ; partie principale 100 × 54 mm, partie rubans 46 × 54 mm** (objectif initial
~130 × 50). Raisons : 6 mm d'isolement + fentes, pistes 16 A (A2), trois borniers 2 pôles
(J1, J4, J4b) empilés sur le bord gauche, et borniers WAGO de ~18 mm de profondeur sur la
partie rubans.

Zonage (vue de dessus) :

| Zone | X (mm) | Contenu |
|---|---|---|
| 230 V | 0 à 46 | J1 (L N), J4 (L_SW N), J4b (L_SW N), contacts de K1, F1, entrée de PS1, RV1 |
| Isolement | 46 à 52 | fente, puis 6 mm d'isolement |
| Basse tension | 52 à 96 | bobine de K1, Q1, D2, U3, sorties de PS1, J3, SW1, U1 (antenne en haut), U2, D1, J2 (DMX) |
| Ligne de séparation | 96 à 104 | fente de 4 mm de part et d'autre de la ligne des languettes |
| Partie sécable (TBTS) | 104 à 146 | Q2 à Q5 (DPAK), R7 à R14, U4, C9, C7, D3, F2 (ATO), J8 (CH2 à CH4), J6 (VLED, CH1), C8, J5 (12/24 V) |

Rendu JLCPCB de la carte réalisée (face top) :

Carte dmxnow v0.3, face top (rendu JLCPCB)

L'antenne de U1 est placée en bord de carte, côté opposé à la zone 230 V et éloignée des
MOSFET, avec zone d'exclusion cuivre sur les deux couches (dimensions selon le guide de
conception matérielle Espressif [V-HW-02]).

#### 4.8.2 Isolement

- Isolation renforcée secteur ↔ TBT (IEC 62368-1, tension de service 250 V eff., catégorie
  de surtension II, degré de pollution 2, FR-4 groupe de matériau IIIb) : ligne de fuite
  minimale **5,0 mm** (2 × 2,5 mm de l'isolation principale), distance dans l'air
  minimale de l'ordre de **3 à 4 mm** selon la tension transitoire retenue [V-HW-11].
  **Objectif retenu : 6 mm pour les deux**, avec fente fraisée de 1 mm sous PS1 entre broches
  AC et DC, prolongée entre contacts et bobine de K1. Une fente ≥ 1 mm de large compte
  comme interruption de la ligne de fuite en degré de pollution 2 (la ligne de fuite contourne
  la fente).
- Entre conducteurs 230 V de polarité différente (L, N, L_SW) : isolation fonctionnelle,
  objectif ≥ 3 mm (le pas de 5 mm des borniers le permet).
- Entre L_IN et L_SW (contact ouvert du relais) : objectif ≥ 3 mm hors relais.
- Aucun plan de masse, aucune piste TBT, aucun via TBT dans la zone 230 V, sur aucune couche.
- Les distances seront vérifiées par règles DRC par classe de réseaux (`netclass` MAINS vs
  LV : clearance 6 mm) et par un contrôle scripté de ligne de fuite simplifié.

#### 4.8.3 Chemins de puissance secteur : **[ARBITRAGE A2, cuivre 16 A retenu]**

Le chemin de charge (J1 → K1 → J4) n'a **aucun fusible sur la carte** (F1 ne protège que
PS1). Il est donc protégé uniquement par le disjoncteur amont, typiquement **16 A** en
France. Une carte dimensionnée pour 10 A pourrait être surchargée durablement entre 10 et
16 A sans déclenchement. Décision : **dimensionner le cuivre du chemin de charge pour
16 A** (le relais et les borniers le sont), charge nominale déclarée de 10 A marquée sur
le boîtier, pas de fusible de charge sur la carte.

Calcul (IPC-2221, couche externe, `I = 0,048 × ΔT^0,44 × A^0,725`, A en mil²) : formule
conservatrice ; à recouper avec les abaques IPC-2152 (par ex. Saturn PCB Toolkit) :

| Courant | ΔT | Section requise | Largeur en 2 oz (2,8 mil) |
|---|---|---|---|
| 10 A | 20 °C | 256 mil² | 2,3 mm |
| 10 A | 10 °C | 390 mil² | 3,5 mm |
| 16 A | 20 °C | 490 mil² | 4,5 mm |
| 17 A (VLED) | 20 °C | 532 mil² | 4,8 mm |

Règle de conception proposée : pistes de puissance **≥ 5 mm sur les deux faces en
parallèle**, reliées par une rangée de vias (ou recouvertes d'étain par ouverture du vernis),
longueurs minimisées (< 30 mm). Résistance d'une piste 5 mm × 70 µm × 30 mm ≈ 1,5 mΩ par
face. Pertes à 10 A dans le cuivre, les contacts du relais et 6 bornes : ~1,5 à 2,5 W au
total (dominé par le contact du relais), à prendre en compte dans le boîtier (R-08) ;
elles tombent sous 0,1 W pour une charge réaliste de 1 à 2 A. Alternative mentionnée par le
cahier des charges : fils soudés sur les broches du relais, retenue seulement si le
placement ne permet pas les largeurs.

Réalisé (rév. 0.3, après revue) : col N de 3,4 mm sur ~8 mm en face arrière seule entre J1
et le bus (IPC-2221 : ~30 °C à 16 A ; impossible à doubler, le doigt L_SW est sur l'autre
face à 1,6 mm), à mesurer au thermocouple lors de l'essai de charge ; L_IN 4 à 4,3 mm sur
les deux faces ; L_SW en doigts de
7,4 mm et bus de 7 mm sur la face avant ; N en bus de 7,1 mm sur la face arrière (les
doigts L_SW le croisent sur l'autre face) ; cols de 1,9 mm sur ≤ 8 mm aux broches des
borniers (imposés par le pas de 5 mm). Estimation IPC-2221 à 16 A : ΔT ≤ 10 °C sur les
bus, ~25 °C sur les cols courts (la chaleur s'étale dans le cuivre voisin) ; à mesurer à
l'essai de charge (REVIEW.md §6).

Comportements à connaître (revue 2026-09-26) :
- Relais ouvert ≠ sectionnement : un seul contact (micro-coupure), sur le conducteur
  arrivant sur J1-1 ; avec une prise française non polarisée, ce peut être le neutre. La
  sortie n'est pas isolée du secteur relais ouvert.
- Tout redémarrage de l'ESP32 (chien de garde, OTA, baisse de tension) relâche le relais
  pendant le démarrage (~0,3 s ; R6 bloque Q1) : le projecteur redémarre.
- Courant d'appel : le G5RL-1A-E-HR admet 100 A crête (VDE, 50 000 manœuvres). Deux
  alimentations à découpage en parallèle sur J4/J4b (projecteur + alimentation LED)
  peuvent dépasser cette valeur à froid : à mesurer avant la mise en service [V-SYS-01] ;
  au-delà de ~80 A, ajouter une limitation d'appel (CTN) côté charge.

#### 4.8.4 Ligne de découpe

- **Fente fraisée + languettes perforées (revue 2026-09-26, ADR 0007 amendé)** : le V-cut
  initial entaille les deux faces de la carte et aurait coupé en fabrication les pistes qui
  le traversent (2 couches, aucune couche interne) ; JLCPCB refuse en outre le V-cut sous
  70 × 70 mm. Fente de 2 mm (X 99-101), trois languettes pleines de 5, 7,5 et 11 mm
  (Y 6,5-11,5 / 22,5-30 / 33-44), rangée de trous NPTH de 0,5 mm au pas de 0,75 mm côté
  partie principale, interrompue au passage des pistes (0,3 mm de garde).
- Traversent la découpe, sur les languettes : PWM1-4, BOARD_SENSE, +5V, GND uniquement (TBT).
- 4 mm sans composant de chaque côté ; plans de cuivre à ≥ 0,7 mm des bords de la fente.
- La GND qui traverse n'est qu'une référence (pistes fines, ~0,5 mm) : le courant des
  rubans ne doit pas pouvoir y circuler en fonctionnement normal. Cf. R-09.
- Sur la partie sécable, GND logique (U4, pull-downs) et GND_LED (retour des rubans) sont
  deux plans distincts reliés en un seul point par **R20 (0 Ω 0805)** près de U4 ; BOARD_SENSE
  est relié à GND par **R21 (0 Ω 0603)**. Deux résistances 0 Ω plutôt que des ponts de
  cuivre (« net ties ») : le DRC et le remplissage des plans les traitent sans ambiguïté,
  pour un coût négligeable.

#### 4.8.5 Méthode de production

Chaîne entièrement scriptée (`hardware/Makefile`, détails dans `hardware/README.md`) :
`design.py` (source unique : composants, broches, nets, classes) → `sch.py` (schéma
KiCad à étiquettes, symboles embarqués) → `pcb.py` (contour, fentes, languettes, placement,
routage 230 V et puissance LED **scripté**, plans) → `route.py` (signaux basse tension
par Freerouting, zone 230 V interdite au routeur) → `check.py` (netlist schéma = design,
pastilles PCB = design, seuls les nets autorisés traversent la découpe) → DRC avec règles
230 V personnalisées (`dmxnow.kicad_dru`) → `fab.py` (Gerbers, perçages PTH/NPTH,
BOM/CPL JLCPCB par variante, BOM complète). SKiDL n'est pas utilisé : ses dépendances ne
s'installent pas ici et la génération directe des fichiers KiCad suffit. La CI
(`.github/workflows/hardware.yml`, image `kicad/kicad:9.0`) rejoue ERC et DRC en KiCad 9,
génère les sorties et les rendus 3D. Document `hardware/REVIEW.md` : liste des points de
contrôle pour la relecture humaine.

### 4.9 Maintenance et OTA

- **Bouton SW1 [ARBITRAGE A6, ajouté le 2026-09-25]**, toujours monté : bouton tactile
  entre IO9 (net BOOT, pull-up R2 existant) et GND, placé en zone basse tension loin de
  l'antenne et de la zone 230 V, actionné depuis l'extérieur par un poussoir imprimé
  **encastré** dans le couvercle basse tension (accès avec une pointe type trombone, pour
  éviter les appuis accidentels). Aucune pièce conductrice accessible : le poussoir est en
  plastique et la zone est TBT isolée. Réutiliser IO9 évite de consommer une GPIO et fait
  de SW1 aussi le bouton BOOT pour le flash. Anti-rebond logiciel (20 ms), pas de
  condensateur (il ralentirait le front lu au reset sur une broche de strapping).
  Comportement, application démarrée :
  - appui ≥ 3 s : entrée en maintenance (en maintenance : sortie immédiate) ;
  - appui ≥ 10 s : `FACTORY_RESET` (clé `net_key` et mot de passe de maintenance
    compris). Justification : seul moyen de récupérer un nœud dont la clé
    d'authentification (A4) est perdue sans console USB ;
  - appui court : aucun effet (évite les fausses manœuvres) ;
  - maintenu pendant la mise sous tension : mode téléchargement ROM (pas notre firmware).
  Coût : ~0,10 € + poussoir imprimé.
- Entrée : commande `MAINTENANCE`, bouton SW1, pastille J3-BOOT, ou **3 mises sous tension
  rapprochées [ARBITRAGE A6, option]**, activée par la clé de configuration
  `powercycle_maint` (**activée par défaut**, désactivable par nœud ; complémentaire de
  SW1 quand le nœud est hors de portée de main, par exemple sur une perche). Principe : au démarrage, le nœud incrémente un compteur
  NVS et le remet à zéro après 5 s de fonctionnement ; si le compteur atteint 3 (trois
  démarrages espacés de moins de 5 s), il passe en maintenance. Usure NVS : 2 écritures
  par démarrage, négligeable. Le relais applique son état au démarrage normalement : la
  manœuvre coupe et rétablit aussi le projecteur, à documenter. Permet de récupérer un
  nœud dont le canal ou le `net_id` est inconnu sans ouvrir le boîtier. Désactivée, le
  compteur n'est ni lu ni écrit.
- **LED d'état [ARBITRAGE A7, option]** : l'empreinte D4 (LED CMS 0603) + R19 (330 Ω,
  LED rouge VF ≈ 2,0 V : ~4 mA sous 3,3 V, suffisant pour un guide de lumière) est **toujours présente** sur le
  PCB, câblée sur IO0 (broche libre, sans rôle de strapping sur l'ESP32-C3). Les deux
  composants sont **non montés par défaut** (DNP) ; la génération des sorties produit deux
  BOM JLCPCB : `bom_base` et `bom_led`. Côté firmware, la clé `status_led` (défaut 0)
  active la LED : allumée fixe = flux DMX présent ; clignotement lent (1 Hz) = réseau
  présent sans flux sur son univers ; double éclat = aucun réseau (balayage) ; clignotement
  rapide (5 Hz) = maintenance ; pendant `IDENTIFY`, la LED clignote avec le reste. Côté
  boîtier, le paramètre `light_pipe` (défaut `False`) ajoute un logement de guide de lumière
  (Ø 3 mm) au droit de D4. Coût de l'option : < 0,1 € + guide de lumière.
- Point d'accès WPA2 `dmxnow-<nom>` sur **le même canal que le réseau ESP-NOW** : l'ESP32
  peut conserver la réception ESP-NOW en mode AP+STA sur le canal commun ; le DMX continue
  donc d'être rafraîchi en maintenance, au mieux [V-FW-05].
- Mot de passe : `maint_password` ; à défaut, mot de passe aléatoire de 12 caractères généré
  au premier démarrage, stocké en NVS, lisible uniquement sur la console USB (J3, hors
  secteur : affiché au démarrage et à l'entrée en maintenance) ; en écriture seule par
  `SET_CONFIG` authentifiée (A4, PROTOCOL §6.4), qui permet de le redéfinir à
  l'enrôlement. (Un mot de passe dérivé de la MAC serait devinable.)
- Page web minimale (configuration, état, téléversement du firmware), OTA par partitions
  `ota_0`/`ota_1` (2 × 1,9 Mo sur 4 Mo) ; validation de l'image (retour arrière si le
  nouveau firmware ne reçoit pas de paquet valide dans les 60 s) si le chargeur d'amorçage
  Arduino 3.x le permet [V-FW-06].
- Sortie : après OTA réussie (redémarrage), sur bouton de la page, ou après `timeout_s`
  (défaut 600 s) sans client connecté.

### 4.10 Dongle

- XIAO ESP32-C3 alimenté par l'USB du Pi. Antenne externe du XIAO (connecteur U.FL) :
  l'antenne fournie doit être montée ; placer le dongle en hauteur (rallonge USB) plutôt
  que derrière le Pi.
- **Boîtier imprimé** (décidé le 2026-09-27, plutôt qu'une clé USB-A du commerce : les
  modèles en boîtier sont à ESP32-S3 et à antenne intégrée, de portée moindre) :
  `enclosure/dongle_case.py`, 59 × 39 × 13 mm, XIAO + **antenne dipôle RP-SMA 5 dBi
  vissée** sur une embase traversant le boîtier (câble u.FL vers RP-SMA de 14 cm), PETG ou
  PLA, oreilles pour un collier ; câble USB-C vers USB-A ; dongle suspendu antenne en bas,
  verticale. Achat (Kiwi Electronics, 2026-09-27) : XIAO ESP32-C3 Seeed 113991054,
  câble RP-SMA/u.FL KW-1518, antenne ANT-24GHZ-5DBI ; XIAO à 0 en stock chez JLCPCB.
- Ordonnanceur : file prioritaire (COMMAND > DMX_DATA > BEACON), émission ESP-NOW
  séquentielle (attente du callback d'émission avant l'envoi suivant, pour ne pas saturer
  la file interne).
- Mesure : une broche GPIO du dongle bascule à chaque émission (point de mesure de latence
  pour ENF-01, sans coût).

### 4.11 Démon Raspberry Pi

- Python ≥ 3.11 (Raspberry Pi OS Bookworm), asyncio, dépendances minimales : `pyserial`
  (lecture/écriture dans un thread dédié relié à asyncio), bibliothèque standard pour le
  reste (argparse, json, hmac). Page web optionnelle : `aiohttp` en extra optionnel.
- Art-Net : ArtDmx (OpCode 0x5000), ArtPoll (0x2000) → ArtPollReply (0x2100) annonçant
  les univers configurés (4 ports par réponse, plusieurs `BindIndex` si > 4 univers). sACN
  optionnel (UDP 5568, multicast `239.255.hi.lo`).
- Configuration `/etc/dmxnow/dmxnowd.toml` : univers transmis, interfaces d'écoute,
  paramètres radio du dongle, clé réseau (A4), compteur d'authentification dans
  `/var/lib/dmxnow/`.
- CLI `dmxnow` ↔ démon par socket Unix `/run/dmxnow/control.sock` (JSON ligne par ligne).
- udev : `SUBSYSTEM=="tty", ATTRS{idVendor}=="303a", ATTRS{idProduct}=="1001",
  ATTRS{serial}=="<MAC du dongle>", SYMLINK+="dmx-dongle"`. Le couple VID:PID est commun à
  tous les ESP32-C3/S3 en USB natif, d'où le filtrage par numéro de série (l'installeur le
  détecte). systemd : `Restart=always`, `RestartSec=1`, utilisateur dédié membre de
  `dialout`.
- Installation : `pi/install.sh` (venv dans `/opt/dmxnow`, service, règle udev), idempotent.

### 4.12 Boîtier 🔴 RELECTURE HUMAINE OBLIGATOIRE (cloison, accès bornes, matériau)

- Modèle CadQuery unique, paramètre `variant = "full" | "cut"`, dimensions intérieures
  dérivées du STEP exporté du PCB + 0,5 mm de jeu.
- Fond + couvercle principal (côté basse tension, vissé M3 sur inserts à chaud) +
  couvercle d'accès borniers 230 V séparé, vissé (outil requis), permettant d'actionner
  les leviers WAGO.
- Cloison intérieure solidaire du fond entre zones 230 V et TBT, alignée sur la fente
  du PCB, hauteur jusqu'au couvercle (recouvrement par une lèvre).
- Logement pour le WAGO 221-413 (jonction des trois PE, arbitrage A9) dans le compartiment
  230 V, maintenu par un clip imprimé, accessible par le couvercle des borniers.
- Entrées de câbles :
  - secteur entrée, sortie projecteur, sortie alimentation LED : presse-étoupes M16 ou PG9
    selon le diamètre des cordons H05VV-F 3G1,5 (≈ 8 à 9 mm) [V-ENC-01] **plus** étrier
    de serrage imprimé vissé (arrêt de traction indépendant du presse-étoupe) ;
  - queue DMX : PG7 (plage 3 à 6,5 mm) ; les câbles DMX 120 Ω font souvent 6 à 6,5 mm :
    à vérifier, sinon M12 [V-ENC-01] ;
  - version entière : entrée 12/24 V et sortie rubans, presse-étoupes PG7/PG9.
- Rien de métallique devant l'antenne (inserts et vis hors d'une zone de 15 mm autour).
- Version entière : fentes d'aération au-dessus des MOSFET, ou fenêtre + pad thermique vers
  une paroi (à choisir au livrable boîtier).
- Poussoir de SW1 (A6) : pièce imprimée captive dans le couvercle basse tension, encastrée
  d'au moins 2 mm sous la surface (orifice Ø 2 mm), loin de l'antenne et de la cloison 230 V.
- Passants pour colliers de serrage (largeur 5 à 8 mm) sur le fond.
- Parois ≥ 2,0 mm (2,5 mm sur les faces portant des presse-étoupes), impression sans
  support : fond et couvercles imprimés face plane sur le plateau, trous de presse-étoupes
  en « goutte d'eau » si horizontaux.
- **Matériau** : il faut un matériau au moins UL94 V-1 pour une enveloppe contenant des
  circuits secteur (enveloppe coupe-feu au sens d'IEC 62368-1) ; le PETG et l'ABS standard
  sont classés HB et ne conviennent pas. Recommandation : **PC-ABS ou ABS ignifugé V-0**
  (ex. famille « ABS-FR / PC-ABS-FR » chez plusieurs fabricants) ou **PC-FR** (plus
  résistant en température, plus difficile à imprimer). Mon choix par défaut : **ABS-FR
  V-0**, imprimable sur une imprimante fermée standard (buse 240 à 260 °C, plateau 100 °C),
  bonne tenue en température (Tg ~100 °C) près du relais et des MOSFET. Réserves : la
  classification V-0 porte sur le matériau à une épaisseur donnée (souvent 1,5 ou 3 mm) ;
  la pièce imprimée doit avoir des parois pleines (100 % de remplissage des parois
  ≥ épaisseur certifiée) ; fiche technique du filament à conserver [V-ENC-02].
- Option `light_pipe` (A7) : logement de guide de lumière Ø 3 mm au droit de D4, dans le
  couvercle basse tension.
- Exports : STL et STEP pour chaque pièce et chaque variante (avec et sans `light_pipe`),
  rendu PNG assemblé.
- **Réalisation (livrable 8.6, 2026-09-26)** : détails et justifications dans
  `enclosure/README.md` :
  - géométrie de la carte exportée du PCB (`hardware/gen/export_board.py` →
    `enclosure/board.json`, contrôlé en CI) plutôt qu'un STEP : plusieurs empreintes du
    projet n'ont pas de modèle 3D ; hauteurs relevées sur les fiches [V-ENC-03] ;
  - **chambres de câblage** aux deux extrémités : le contre-écrou d'un M16 (22 mm) ne peut
    pas traverser le plan du PCB ; côté secteur, 34 mm pour l'écrou, l'étrier et le WAGO
    221-413 ; d'où le dépassement d'ENF-05 ;
  - cloison 🔴 en trois parties (paroi du fond, languettes dans les fentes d'isolement,
    jupe du couvercle 230 V passant à 0,5 mm du PCB et au-dessus de K1 et PS1, qui
    enjambent la ligne), couvercle 230 V recouvrant le bord du couvercle TBT ;
  - H1 (13,5 mm de l'antenne) sans insert : ergot imprimé + tube presseur ; variante cassée
    sans vis dans le coin supérieur droit ;
  - DMX en **M12** (serrage jusqu'à 7 mm, les câbles DMX dépassant souvent les 6 mm du
    PG7), sorties rubans et alimentation LED en M16 ;
  - aérations : fentes dans le couvercle TBT au-dessus de Q2 à Q5 et entrées basses sous
    la partie sécable ; aucune ouverture dans le couvercle 230 V ;
  - hauteur intérieure 31 mm (F2 + fusible), PCB à 5 mm du fond.

---

## 5. Budgets de latence et de débit

### 5.1 Latence Art-Net → ligne DMX

Hypothèses : 1 univers de 512 canaux, radio v2 à 6 Mbit/s, dongle et nœud en émission
sur événement (PROTOCOL §4.4).

Temps d'antenne d'un DMX_DATA : 530 octets utiles + ~60 octets d'encapsulation
(en-tête MAC 24, catégorie/OUI/aléa 8, éléments vendeur ~20, FCS 4 ; valeur exacte v2 à
confirmer [V-FW-07]) ≈ 590 octets = 4720 bits → 0,79 ms à 6 Mbit/s + préambule 20 µs +
DIFS 28 µs + attente aléatoire moyenne ~70 µs ≈ **0,9 ms** (≈ 5 ms à 1 Mbit/s DSSS).

Durée d'une trame DMX de N canaux : break 176 µs + MAB 12 µs + (N + 1) × 44 µs.
N = 512 → **22,7 ms** ; N = 40 → 2,0 ms.

| Étape | Typique | Pire cas | Commentaire |
|---|---|---|---|
| QLC+ → UDP loopback → démon | 0,2 ms  | 1 ms | hors cadence interne QLC+ (50 Hz, 20 ms) |
| Démon : parsing, encodage COBS, écriture | 0,3 ms  | 2 ms | Python ; pire cas = ordonnancement Linux |
| USB CDC (≈ 540 octets) | 0,5 ms  | 2 ms | trames USB de 1 ms, paquets bulk de 64 o [V-FW-04] |
| Dongle : décodage, CRC, `esp_now_send` | 0,1 ms  | 0,5 ms | |
| Radio (6 Mbit/s) | 0,9 ms  | 3 ms | pire cas : canal occupé par un Wi-Fi voisin |
| Nœud : callback → tâche DMX | 0,1 ms  | 0,5 ms | |
| Attente de fin de la trame DMX en cours, N = 512 | 11 ms  | 22,7 ms  | émission non interruptible |
| Attente de fin de la trame DMX en cours, N = 40  | 1 ms | 2,0 ms | |
| Émission jusqu'au canal k (k petit) | 0,2 ms  | 0,2 + 0,044 × k ms | |
| **Total, trame DMX 512 canaux** | **~13 ms** | **~34 ms** | objectif < 10 ms **non tenu** |
| **Total, trame DMX 40 canaux** | **~3,3 ms** | **~13 ms** | objectif tenu en typique |

De plus, beaucoup de projecteurs n'appliquent les valeurs qu'en fin de trame (au break
suivant), ce qui ajoute une durée de trame complète : encore un argument pour les trames
courtes.

**[ARBITRAGE A3, défaut 512 retenu]** : l'objectif < 10 ms n'est tenable qu'avec des trames DMX courtes
(n'émettre que jusqu'au dernier canal utile du projecteur). Le DMX512 l'autorise (trames de
24 à 512 canaux ; intervalle break à break ≥ 1204 µs, respecté dès 24 canaux). Certains
appareils anciens supportent mal les trames courtes. Proposition : paramètre
`dmx_out_slots` par nœud, **défaut 512** (compatibilité maximale), réglé par la CLI à la
mise en service à « adresse de fin du projecteur », avec recommandation documentée. La
CLI affichera un avertissement pour tout nœud resté à 512. ENF-01 est donc vérifiée sur un
nœud configuré en trame courte.

### 5.2 Débit et occupation radio

| Grandeur | Valeur |
|---|---|
| Débit utile par univers à 44 Hz | 44 × 530 o ≈ 23 ko/s |
| Occupation du canal par univers à 44 Hz, 6 Mbit/s | 44 × 0,9 ms ≈ **4 %** |
| Idem à 50 Hz (cadence QLC+) | ≈ 4,5 % |
| Idem à 1 Mbit/s | ≈ 22 % |
| Mode fragmenté v1, 3 paquets, 6 Mbit/s | ≈ 1,6 ms/univers, ≈ 7 % |
| HEARTBEAT, 30 nœuds, 0,5 Hz, ~74 o | < 0,5 % |
| BEACON | < 0,1 % |

Limite recommandée : **4 univers par dongle et par canal** (≈ 18 % d'occupation à
6 Mbit/s), pour laisser de la marge aux réseaux Wi-Fi voisins et aux retransmissions. Le
protocole n'impose pas de limite (15 bits d'univers). Le nombre de nœuds n'est pas limité
par le broadcast (un nœud écoute sans coût radio) ; il l'est seulement par le trafic de
heartbeats (plusieurs centaines de nœuds avant 5 %).

### 5.3 Fiabilité

Sans acquittement en broadcast, une trame perdue est corrigée par la suivante 22,7 ms
plus tard au pire (20 ms à la cadence QLC+). À 1 % de perte, la probabilité de 3 trames
consécutives perdues (~70 ms de gel, perceptible sur un effet rapide) est de 10⁻⁶ par
trame, soit environ une fois toutes les 6 heures par univers ; à 5 %, une fois par
10 secondes. D'où ENF-03 et le choix du canal comme premier levier.

---

## 6. Coût estimé par nœud (série de 20, prix indicatifs 2025-2026, à confirmer)

| Poste | Carte entière | Carte cassée |
|---|---|---|
| ESP32-C3-MINI-1 | 2,5 € | 2,5 € |
| Mean Well IRM-03-5 (A1) | 6 € | 6 € |
| Omron G5RL-1A-E-HR | 2,5 € | 2,5 € |
| Bouton SW1 (A6) | 0,1 € | 0,1 € |
| WAGO 2604 : 3 × 2 pôles (+ 2 × 2 + 3 pôles), WAGO 221-413 | 5,5 € (+ 5 €) | 5,5 € |
| SP3485, SM712, AP2112K, AO3400, passifs | 1,5 € | 1,5 € |
| Partie rubans : 4 × AOD2610E, 74AHCT125, porte-fusible ATO + fusible, C7, D3, passifs | 3,5 € | - |
| PCB 2 couches 2 oz + assemblage CMS JLCPCB (répartis) | 5 € | 5 € |
| Boîtier ABS-FR V-0 (~150 g / ~115 g, pièces pleines) + inserts + vis | 7 € | 5,5 € |
| Presse-étoupes (5 × M16 + M12 / 3 × M16 + M12) | 3,5 € | 2,5 € |
| Queue DMX : 1 m de câble 120 Ω + Neutrik NC3FXX | 5,5 € | 5,5 € |
| **Total** | **≈ 53 €** | **≈ 39 €** |

Dans la cible de 30 à 50 €, mais la carte entière est en limite haute depuis le choix d'un module Mean Well (A1). Les postes les plus sensibles sont la connectique (WAGO, Neutrik) et PS1.
**Prix LCSC relevés le 2026-09-26** (API JLCPCB, toutes les références de `design.py`) :
composants de la carte entière **≈ 36 $ à l'unité, ≈ 31 $ par nœud en série de 20** (estimation révisée le 2026-09-26 pour J6 + J8), dont
≈ 12 $ pour la partie principale seule. Postes principaux : WAGO 2604-1102 (5 × 2,4 à 3,2 $),
IRM-03-5 (3,9 $), ESP32-C3-MINI-1-N4 (3,5 à 3,8 $), WAGO 2604-1103 (3,8 à 4,8 $), porte-fusible
ATO (2,1 à 2,5 $), G5RL-1A-E-HR (1,4 à 1,7 $). Tous les composants traversants sont
référencés chez LCSC (assemblage traversant JLCPCB possible) ; le WAGO 2604-1105 (5 pôles)
prévu à l'origine pour J6 est **arrêté chez WAGO** : remplacé par J6 (2604-1102, VLED + CH1) et
J8 (2604-1103, CH2 à CH4), en stock chez JLCPCB. Côté assemblage CMS : 7
références « extended » (≈ 3 $ de frais chacune par commande) ; le reste est en « basic ».
Prototype (5 PCB, 2 assemblés en CMS, traversants soudés à la main, hors port et TVA) :
≈ 120 à 150 $ ; série de 20 : ≈ 35 $ d'électronique par nœud [V-HW-13].

---

## 7. Risques

| ID | Risque | Impact | Probabilité | Mesure |
|---|---|---|---|---|
| R-01 | 🔴 Défaut d'isolement secteur/TBT (placement, fabrication, humidité) | Électrocution via la XLR ou les rubans | Faible si règles appliquées | ES-01, fente, DRC par classes, relecture humaine, test diélectrique recommandé (§8.2) |
| R-02 | 🔴 Surcharge du chemin de charge entre 10 et 16 A | Échauffement, incendie | Moyenne sur installation mal dimensionnée | A2, marquage de la charge maximale sur le boîtier |
| R-03 | Contrefaçon ou certification douteuse de PS1 | Défaut d'isolement | Faible (IRM-03-5, A1) | Achat chez un distributeur agréé |
| R-04 | `esp_dmx` incompatible avec Arduino 3.x / IDF 5.5 | Retard firmware | Moyenne | Pilote DMX maison de repli (§4.4) |
| R-05 | Plateforme pioarduino abandonnée ou incompatible | Build cassé | Faible à moyenne | Versions épinglées dans `platformio.ini` ; repli ESP-IDF pur possible (le code `common` est indépendant d'Arduino) ; repli radio v1 fragmenté |
| R-06 | Latence > 10 ms avec trames DMX de 512 canaux | Objectif non tenu | Certaine avec N = 512 | A3 |
| R-07 | Échauffement de U3 (LDO) | Dérive, arrêt thermique | Moyenne | Cuivre, mesure ; repli : convertisseur abaisseur (nouvel arbitrage) |
| R-08 | Échauffement dans un boîtier fermé (relais 0,4 W, PS1 ~0,6 W, contacts à fort courant, MOSFET ~1 W) | Vieillissement, déformation du boîtier | Moyenne | Aérations, matériau Tg ≥ 100 °C, mesure à charge nominale |
| R-09 | Boucle de masse : GND_LED (alimentation LED) reliée à la GND DMX, elle-même souvent au PE via le projecteur ; si le −V de l'alimentation LED est aussi relié au PE, une partie du courant des rubans peut circuler par la masse DMX et la piste GND de la découpe | Perturbations DMX, échauffement d'une piste fine | Faible (Mean Well LRS/HLG : sortie flottante) | Documenter : sortie de l'alimentation LED non reliée à la terre ; option résistance/ferrite série dans la GND de découpe à évaluer au PCB |
| R-10 | Écrêtage de D3 (≈ 45 V) au-delà de VDS max des MOSFET (40 V) ; surtensions inductives des câbles de rubans | Destruction MOSFET | Faible | **Clos** : AOD2610E 60 V (revue 2026-09-26) |
| R-11 | Trafic ESP-NOW hostile ou accidentel (même `net_id`) | Spectacle perturbé | Faible | `net_id` aléatoire recommandé, A4 pour les commandes |
| R-12 | Wi-Fi voisin intense sur le même canal (salle, festival) | Pertes, latence | Moyenne | Choix du canal (scan documenté), débit, CLI affichant les pertes |
| R-13 | Ondulation excessive dans C7 | Vieillissement de C7 | Moyenne | Condensateur faible ESR + déphasage PWM (§4.6) |
| R-14 | V-cut sur une carte de 50 mm de haut refusé ou non standard chez JLCPCB | Surcoût, découpe différente | Moyenne | **Réalisé** : V-cut abandonné (il coupait aussi les pistes), fente + languettes perforées |
| R-16 | Défaut de PS1 : sa protection de surtension (OVP) déclenche entre 5,2 et 6,8 V (fiche IRM-03), au-delà des 6,5 V max absolus de l'AP2112K (U3) | Destruction de U3 / ESP32 lors d'un défaut de PS1 seulement | Faible | Accepté (cas de défaut, pas de fonctionnement normal) ; option TVS 5,6 V sur +5V si la revue le demande [V-HW-05] |
| R-15 | Boîtier ignifugé difficile à imprimer (gauchissement) | Retard | Moyenne | Géométrie sans grands aplats, congés, bordure ; test d'impression tôt |

---

## 8. Critères d'acceptation par livrable

### 8.1 Protocole (ce document + PROTOCOL.md)
- Validation explicite par toi ; arbitrages A1 à A8 tranchés (fait le 2026-09-25, §9).

### 8.2 PCB
- ERC et DRC `kicad-cli` sans erreur ni avertissement non justifié (exceptions listées).
- Règles de classes de réseaux : MAINS ↔ LV ≥ 6 mm ; MAINS ↔ MAINS ≥ 3 mm ; pistes de
  puissance ≥ largeurs §4.8.3 ; aucun cuivre MAINS à < 4 mm de l'axe de découpe (vérifié
  par script).
- Fichiers JLCPCB : Gerber, perçage (fente et perforations incluses), BOM (`bom_base` et `bom_led`, A7) et CPL au format JLCPCB, rendus PNG
  dessus/dessous ; génération reproductible par une commande (`make -C hardware`).
- `hardware/REVIEW.md` : liste de contrôle de relecture humaine complétée.
- Recommandation (hors CI) : test diélectrique secteur/TBT au premier prototype
  (3 kV AC ou 4,2 kV DC, 60 s, par une personne équipée) et essai de charge à 10 A pendant
  1 h avec relevé thermique.

### 8.3 Firmware nœud
- Compilation CI (pioarduino épinglé) sans avertissement bloquant.
- Tests natifs verts : CRC (vecteur `0x29B1`), codec en-tête et types, validation et
  rejets, réassemblage (ordre, pertes, doublons, fusion partielle), anti-rebond relais
  (différé, dernier état, priorités), gamma (bornes, monotonie, linéaire à 1,0), TLV,
  compteur de pertes (bouclage 16 bits), vecteurs communs.
- Recette sur banc : DMX mesuré à l'analyseur logique (timings, cadence), relais,
  PWM (fréquence, résolution, déphasage), maintenance et OTA, perte de flux.

### 8.4 Firmware dongle
- Compilation CI ; tests natifs (COBS, ordonnancement, répétition, `hold_timeout`, suivi
  des commandes et retransmissions) ; recette : latence mesurée ≤ budget §5.1.

### 8.5 Démon Pi
- `pytest` vert : parsing Art-Net (ArtDmx, ArtPoll/Reply), COBS, CRC, encodage des trames,
  vecteurs communs, gestion de reconnexion (dongle simulé par pseudo-terminal).
- `install.sh` testé sur Raspberry Pi OS Bookworm (ou conteneur Debian Bookworm en CI) ;
  service démarré, redémarrage automatique vérifié.
- CI : compilation des firmwares, tests natifs, tests Python, ERC/DRC, export boîtier.

### 8.6 Boîtier
- Export STL et STEP sans erreur pour les deux variantes ; solides valides (`isValid()`),
  fermés ; vérification scriptée des jeux (PCB + 0,5 mm), épaisseurs de paroi ≥ 2 mm, zone
  sans métal autour de l'antenne ; rendu PNG assemblé.

### 8.7 Documentation
- Documents listés au cahier des charges ; liste de contrôle sécurité avant mise sous
  tension ; relue par toi.

---

## 9. Arbitrages (tranchés le 2026-09-25)

| ID | Sujet | Décision | Alternative écartée |
|----|---|---|---|
| A1 | Alimentation interne (décision 4) | **Mean Well IRM-03-5** (certifié 62368-1 ; IRM-05-5 écarté au placement pour son encombrement) ; HLK-PM05 en empreinte de repli | HLK-PM05 par défaut |
| A2 | Protection du chemin de charge | **Cuivre dimensionné 16 A**, charge nominale déclarée 10 A, pas de fusible de charge | Fusible 10 A sur carte |
| A3 | Longueur des trames DMX | **`dmx_out_slots` défaut 512**, réglage à la mise en service, avertissement CLI | Défaut court (64) |
| A4 | Authentification des commandes (PROTOCOL §7) | **Oui**, HMAC tronqué + compteur, clé facultative (enrôlement) | `net_id` seul |
| A5 | Balayage des canaux après 60 s sans réseau | **Oui** | Canal fixe strict |
| A6 | Maintenance sans ouvrir le boîtier | **Bouton SW1** sur IO9, toujours monté, accessible par un poussoir encastré (3 s maintenance, 10 s réinitialisation) **+ option** `powercycle_maint` (3 mises sous tension < 5 s, activée par défaut) (révisé le 2026-09-25) | BOOT seulement (ouverture du couvercle) |
| A7 | LED d'état | **Option** : empreinte D4/R19 sur IO0 toujours présente, non montée par défaut, clé `status_led` (défaut 0), option boîtier `light_pipe` (révisé le 2026-09-25) | Pas de LED ; LED systématique |
| A8 | ESP-NOW v2 + pioarduino (ADR 0011) | **Oui**, repli v1 fragmenté implémenté | v1 fragmenté seul |
| A9 | Routage 230 V 16 A en 2 couches avec trois borniers 3 pôles (constaté infaisable proprement) | **PE hors carte** : J1, J4, J4b en WAGO 2604 2 pôles (L, N) ; PE réunis par un WAGO 221-413 dans le compartiment 230 V (2026-09-26) | PCB 4 couches ; carte plus haute |

Question close (2026-09-26, 5ᵉ revue), **alimentation de programmation** : injecter
3,3 V sur J3-3V3 alimenterait la sortie d'un AP2112K non alimenté, courant inverse non
garanti par la fiche [V-HW-05]. J3 reçoit une 7ᵉ pastille **J3-5V** (+5V, entrée du
régulateur) : la carte se programme hors secteur en alimentant par J3-5V (adaptateur USB
5 V) ; J3-3V3 sert de point de mesure seulement. Ne jamais alimenter J3-5V avec le
secteur branché (le +5V de PS1 serait mis en parallèle).

---
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

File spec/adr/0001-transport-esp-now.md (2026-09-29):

# ADR 0001 : Transport radio ESP-NOW

**Statut :** Accepté (cahier des charges, décision 1)

## Contexte

Il faut transporter un univers DMX (512 octets) à 44 Hz vers des dizaines de nœuds, avec une latence de quelques ms, sans infrastructure.

## Décision

ESP-NOW en broadcast sur un canal Wi-Fi fixe configurable. Le Wi-Fi associé (Art-Net) n'est utilisé qu'en maintenance.

## Conséquences

- Pas de point d'accès ni d'association : démarrage immédiat, aucune dépendance au réseau du lieu.
- Broadcast : un seul envoi pour tous les nœuds d'un univers ; coût radio indépendant du nombre de nœuds.
- Pas d'acquittement en broadcast : la répétition continue tient lieu de fiabilité (PROTOCOL §4.4, SPEC §5.3).
- Le broadcast ESP-NOW ne peut pas être chiffré (voir ADR 0015).

## Alternatives écartées

- Wi-Fi + Art-Net en exploitation : dépend d'un point d'accès, latences variables (économie d'énergie, multicast/broadcast Wi-Fi émis au débit de base).
- Zigbee, Thread, BLE : débit insuffisant pour 512 octets à 44 Hz avec marge.
- LoRa : débit de quelques kbit/s.
- CPL : latence irrégulière, perturbé par les alimentations à découpage des projecteurs.

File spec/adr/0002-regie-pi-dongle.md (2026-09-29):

# ADR 0002 : Régie Raspberry Pi + QLC+ + dongle XIAO ESP32-C3

**Statut :** Accepté (décision 2)

## Contexte

La régie est un Raspberry Pi sous QLC+. Le Pi n'a pas de radio compatible ESP-NOW.

## Décision

QLC+ émet de l'Art-Net vers 127.0.0.1 ; un démon Python (`dmxnowd`) le reçoit, répond aux ArtPoll et transmet les univers en USB à un dongle Seeed XIAO ESP32-C3 qui les diffuse en ESP-NOW.

## Conséquences

- Aucune modification de QLC+ : la sortie Art-Net standard suffit.
- Le démon est le point unique pour la supervision (heartbeats) et les commandes (CLI).
- Même famille de puce que les nœuds : code `common` partagé.
- Point de défaillance unique (dongle) : le dongle continue d'émettre la dernière trame pendant `hold_timeout` si le Pi se tait.

## Alternatives écartées

- Plugin QLC+ natif : maintenance lourde, couplage à une version de QLC+.
- Dongle Wi-Fi du Pi en mode moniteur/injection pour émettre de l'ESP-NOW : fragile, dépendant du pilote.

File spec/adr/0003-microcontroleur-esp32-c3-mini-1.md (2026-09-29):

# ADR 0003 : Microcontrôleur ESP32-C3-MINI-1

**Statut :** Accepté (décision 3)

## Contexte

Le nœud a besoin d'une radio ESP-NOW, d'un UART pour le DMX, de 4 PWM, d'une broche relais et d'une mise à jour OTA.

## Décision

Module ESP32-C3-MINI-1 (flash intégrée, antenne PCB intégrée), programmation par l'USB natif (GPIO18/19).

## Conséquences

- Module précertifié radio : pas de conception RF.
- Zone d'exclusion d'antenne à respecter sur le PCB et le boîtier.
- GPIO limités (IO0-IO10, IO18-21) : affectation SPEC §4.2 ; IO2/IO8/IO9 sont des broches de strapping.
- BOOT (IO9) à la masse au reset entre dans le chargeur ROM : l'entrée en maintenance par BOOT est reformulée (SPEC §4.2).

## Alternatives écartées

- ESP32 classique (WROOM) : plus gros, plus gourmand, pas d'USB natif.
- ESP32-C3-MINI-1U (antenne externe) : connecteur et antenne à loger dans le boîtier.

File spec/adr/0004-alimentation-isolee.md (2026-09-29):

# ADR 0004 : Alimentation interne isolée Mean Well IRM-03-5

**Statut :** Accepté. Décision 4 du cahier des charges, amendée par l'arbitrage A1 du 2026-09-25.

## Contexte

Le nœud doit être alimenté depuis le secteur et sa masse est reliée au DMX et aux rubans, donc accessible. La décision 4 retenait un Hi-Link HLK-PM05 ; les certifications des modules Hi-Link sont difficiles à vérifier et les contrefaçons fréquentes, ce qui pèse pour un projet publié et refabriqué par d'autres.

## Décision

Module AC/DC isolé **Mean Well IRM-03-5** (5 V, 600 mA, 3 W, homologué IEC/EN/UL 62368-1 selon le fabricant), protégé par F1 T500 mA et RV1 10D561K (à confirmer selon la fiche Mean Well). Le HLK-PM05 reste une empreinte de repli paramétrable, non retenue par défaut. Les alimentations non isolées sont exclues.

## Conséquences

- Masse DMX isolée du secteur : sécurité et absence de boucle secteur.
- Budget 5 V : ~200 mA moyen, ~420 mA crête pour 600 mA disponibles, marge ~30 % (SPEC §4.3).
- Coût +3,5 € par nœud environ : carte entière ≈ 47 €, en limite haute de la cible.
- Empreinte différente du HLK-PM05 : brochage et cotes à relever sur la fiche Mean Well (V-HW-09).
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

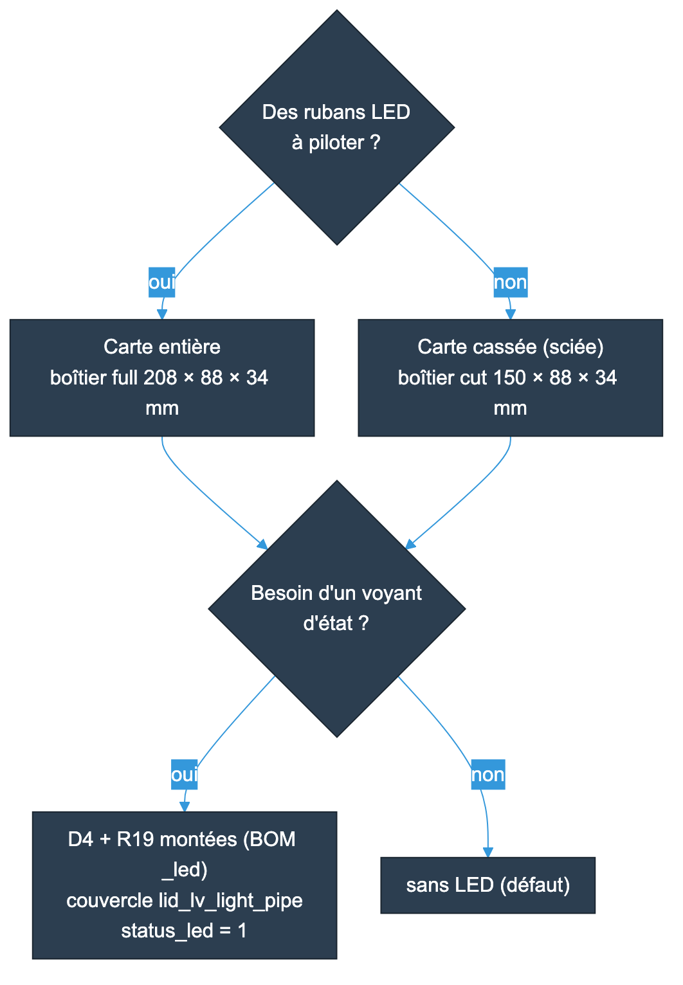
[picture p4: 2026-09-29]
docs/diagrams/materiel.png

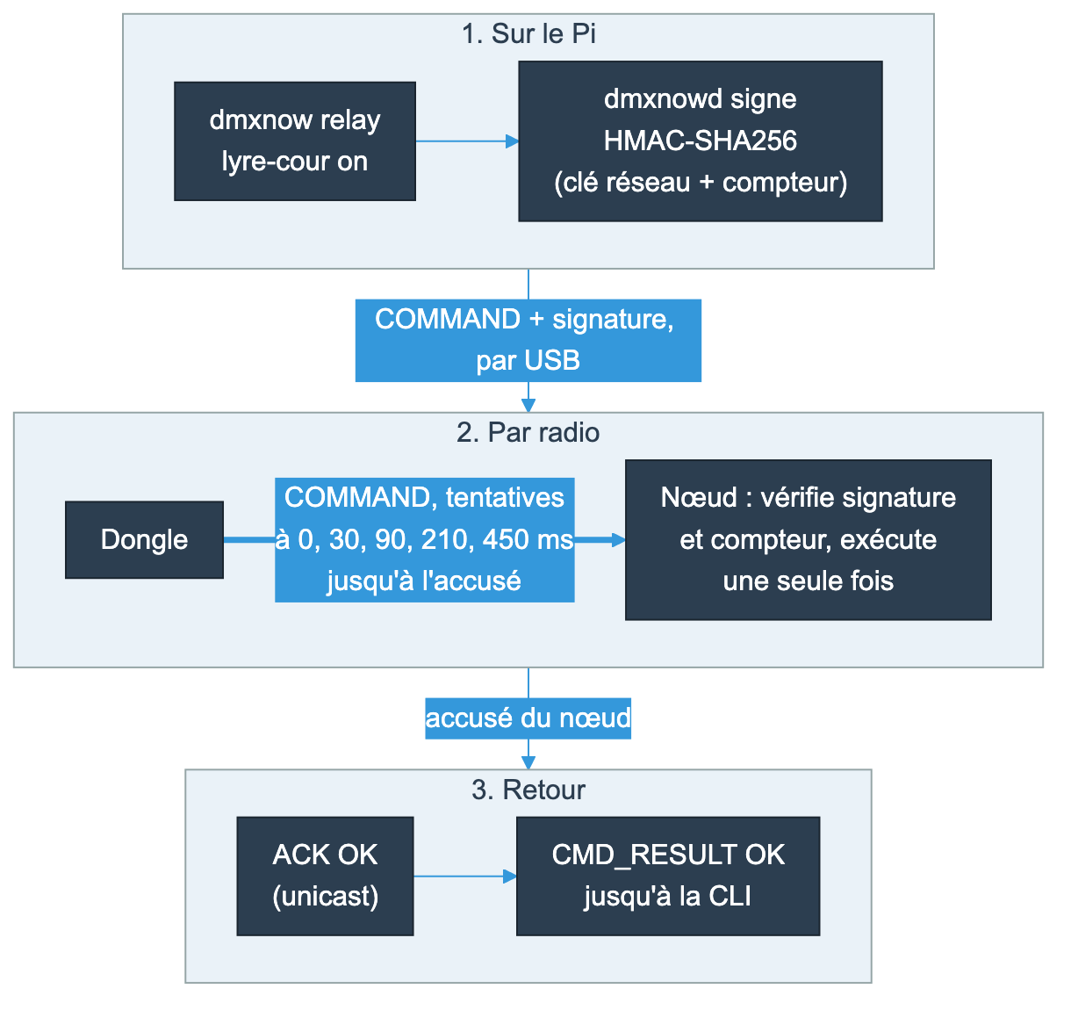
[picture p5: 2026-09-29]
docs/diagrams/commandes.png

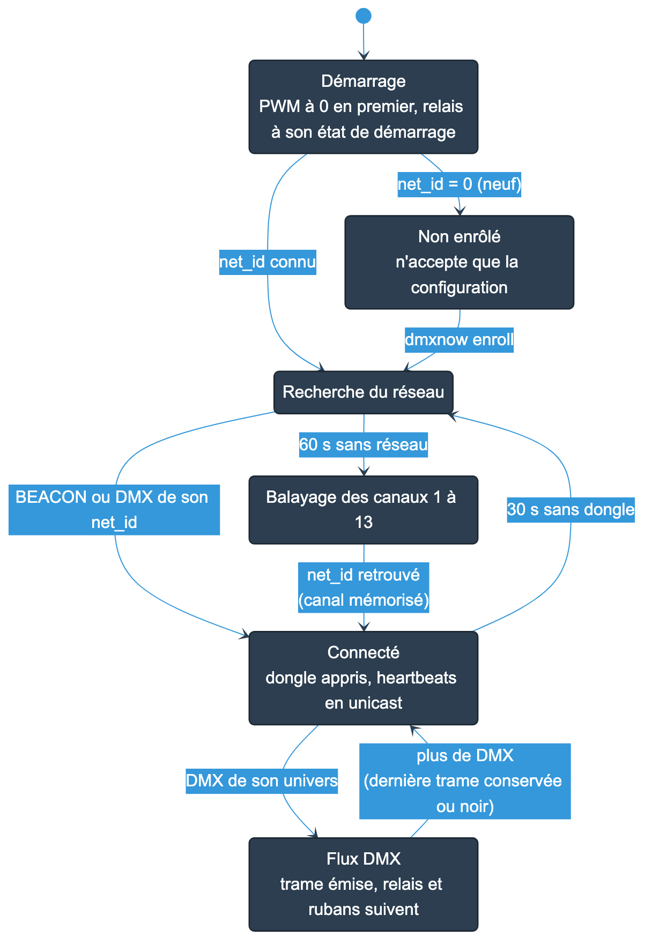
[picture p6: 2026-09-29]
docs/diagrams/cycle-de-vie.png

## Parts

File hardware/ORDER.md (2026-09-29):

# Commande JLCPCB : première série (5 nœuds montés)

🔴 **Avant de payer** : relecture humaine de [`REVIEW.md`](REVIEW.md) (sections 1 et 2
en priorité) faite et signée, CI `hardware` verte sur le commit commandé.

Estimation : **~335 à 400 € TTC** pour les 5 cartes montées livrées, **~125 à 150 €**
d'achats hors JLCPCB, soit **~500 € TTC** pour 5 nœuds (prix JLCPCB du 2026-09-27 ;
le devis en ligne fait foi).

## 1. Fichiers à déposer

| Étape du site | Fichier |
|---|---|
| Gerber | `fab/dmxnow-gerbers.zip` |
| BOM | `fab/bom_jlcpcb_full.csv` |
| CPL (placement) | `fab/cpl_jlcpcb_full.csv` |

Variante avec la LED d'état (option A7) : `bom_jlcpcb_full_led.csv` +
`cpl_jlcpcb_full_led.csv`. Par défaut, **sans LED**.

## 2. Réglages PCB

| Paramètre | Valeur |
|---|---|
| Base material | FR-4, TG ≥ 150 si proposé |
| Layers | 2 |
| Dimensions | reprises des Gerbers : 146 × 65,5 mm |
| PCB Qty | 5 |
| Delivery format / Panel | **Panel by Customer**, 1 × 1 |
| Different Design | **2** (JLCPCB compte la fente fraisée et les languettes comme 2 circuits) |
| PCB Thickness | 1,6 mm |
| PCB Color / Silkscreen | vert / blanc (le moins cher, délai standard) |
| Surface Finish | HASL sans plomb (ou ENIG) |
| **Outer Copper Weight** | **2 oz** (indispensable : chemins 16 A et 17 A) |
| Via Covering | Tented |
| Remove Order Number | Yes |
| Castellated holes, edge plating | No |

**Remarque de commande (PCB et PCBA)**, à copier telle quelle :

> One circuit with an internal routed slot and 3 breakaway tabs carrying traces; deliver
> and assemble as one piece, do NOT separate. SMT: convey on the straight short edges X=0
> and X=146; U1/Q5/R10 are close to the Y=54 edge by design. J3, J2 not populated: keep
> holes open (no solder fill). J1, J4, J7, J5, J6, J8: wire entry toward board edge; J6
> and J8 side by side. RV1: form leads to the PCB holes. F2: press flat before soldering.
> F1/F2 fuses are not fitted.

## 3. Réglages PCBA

| Paramètre | Valeur |
|---|---|
| PCBA Type | **Standard** (module ESP32 et composants traversants) |
| Assembly Side | Top Side |
| PCBA Qty | **5** |
| Tooling holes / edge rails | selon la proposition de JLCPCB (voir la remarque : convoyage par les petits côtés) |
| Confirm Parts Placement | **Yes** (JLCPCB envoie l'aperçu à valider) |

Après dépôt de la BOM : **32 lignes, 56 composants placés**, toutes « in stock » (le
WAGO 2604-1102 C3309286 apparaît sur 5 lignes, une par bornier : normal). J2 (queue DMX),
J3 (pastilles de programmation), R19 et D4 (option LED) ne sont pas dans la BOM : normal.
Revérifier le stock des références à faible stock :

| Réf. | LCSC | Stock au 2026-09-27 | Besoin |
|---|---|---|---|
| K1 G5RL-1A-E-HR | C113250 | 232 | 5 |
| J8 WAGO 2604-1103 | C3309758 | 356 | 5 |
| J1/J4/J5/J6/J7 WAGO 2604-1102 | C3309286 | 594 | 25 |
| F2 porte-fusible ATO | C207061 | 617 | 5 |
| PS1 IRM-03-5 | C6969425 | 992 | 5 |

## 4. Aperçu de placement : points à contrôler

JLCPCB montre chaque composant sur la carte ; comparer à la sérigraphie :

- **Q2 à Q5** (DPAK) : languette (grande pastille) vers les borniers J6/J8 (vers la droite).
- **U1** (ESP32-C3) : zone d'antenne vers le bord supérieur, sur la mention « Antenna Area ».
- **C7** (électrolytique) : « + » sur la pastille carrée, à gauche.
- **D3** (SMBJ28A) : cathode (bande) vers le haut, côté C7 / VLED.
- **U2, U3, U4, D1, Q1** : point de la broche 1 sur le repère de la sérigraphie.
- **PS1** : broche 1 (carrée) en bas à gauche, côté RV1 ; **K1** : bobine côté droit (x ≈ 53).
- **WAGO J1, J4, J7** : entrée des fils vers le bord gauche ; **J5, J6, J8** : vers le bord droit.
- **F1, F2** : supports seulement (fusibles non fournis).

## 5. Achats hors JLCPCB (5 nœuds + rechanges)

| Article | Qté | Note |
|---|-----|---|
| Fusible 5×20 mm **T500 mA H 250 V** (Littelfuse 0215.500MXP ou équivalent céramique) | 10 | F1, dont 5 de rechange |
| Fusible ATO **20 A** | 10 | F2, dont 5 de rechange |
| WAGO 221-413 | 5 | Jonction des PE (A9) |
| Presse-étoupe plastique M16 × 1,5 (serrage 4,5-10 mm) + contre-écrou | 25 | Carte entière : 5 par boîtier |
| Presse-étoupe plastique M12 × 1,5 (serrage jusqu'à 7 mm) + contre-écrou | 5 | Queue DMX |
| Inserts M3 à chaud Ø 4,0 × 5,7 | 80 | 16 par boîtier |
| Vis M3 × 6 / M3 × 16 | 50 / 30 | Couvercles + PCB / étriers |
| Filament **ABS-FR ou PC-ABS-FR UL94 V-0** | 1 kg | ~750 g utiles ; garder la fiche technique [V-ENC-02] 🔴 |
| Câble DMX 120 Ω + Neutrik NC3FXX | 5 m + 5 | Queues de 1 m |
| Câble secteur H05VV-F 3G1,5 + fiches | selon installation | Hors estimation |

Pour la programmation : une rallonge ou un adaptateur USB (5 V, GND, D−, D+) à relier
aux pastilles J3 ; alimenter par **J3-5V**, jamais par J3-3V3 (REVIEW 7.6).

## 6. À réception

Suivre [`REVIEW.md`](REVIEW.md) §6 : inspection, continuité, **essai diélectrique
secteur ↔ basse tension**, première mise sous tension derrière transformateur d'isolement
et différentiel 30 mA.

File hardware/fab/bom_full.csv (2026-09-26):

Ref | Value | Footprint | MPN | LCSC | Section | Fitted | Assembly | Note
J1 | WAGO 2604-1102 (L N in) | dmxnow:TerminalBlock_WAGO_2604-1102_1x02_P5.00mm_Horizontal | 2604-1102 | C3309286 | main | yes | THT | PE is joined off-board by a WAGO 221-413 (arbitrage A9)
J4 | WAGO 2604-1102 (L_SW N out 1) | dmxnow:TerminalBlock_WAGO_2604-1102_1x02_P5.00mm_Horizontal | 2604-1102 | C3309286 | main | yes | THT | PE is joined off-board by a WAGO 221-413 (arbitrage A9)
J7 | WAGO 2604-1102 (L_SW N out 2, J4b) | dmxnow:TerminalBlock_WAGO_2604-1102_1x02_P5.00mm_Horizontal | 2604-1102 | C3309286 | main | yes | THT | PE is joined off-board by a WAGO 221-413 (arbitrage A9)
F1 | 5x20 holder, T500mA H | Fuse:Fuseholder_Cylinder-5x20mm_Schurter_0031_8201_Horizontal_Open | Schurter 0031.8201 | C3204125 | main | yes | THT | Fuse: Littelfuse 0215.500MXP (T500mA 250V ceramic, 1500 A)
RV1 | 10D561K | dmxnow:RV_Disc_D12mm_T9mm_P7.5mm_Drill1.1 | 10D561K | C113236 | main | yes | THT
PS1 | IRM-03-5 | dmxnow:Converter_ACDC_MeanWell_IRM-03-xx_THT_Drill1.0 | MEAN WELL IRM-03-5 | C6969425 | main | yes | THT
K1 | G5RL-1A-E-HR DC5 | dmxnow:Relay_SPST_Omron_G5RL-1A-E-HR | Omron G5RL-1A-E-HR DC5 | C113250 | main | yes | THT | Omron pins: coil 1/8, COM 3/6, NO 4/5
U3 | AP2112K-3.3 | Package_TO_SOT_SMD:SOT-23-5 | AP2112K-3.3TRG1 | C51118 | main | yes | SMT
C5 | 1uF | Capacitor_SMD:C_0603_1608Metric |  | C15849 | main | yes | SMT
C10 | 47uF 10V | Capacitor_SMD:C_1206_3216Metric |  | C96123 | main | yes | SMT
C6 | 1uF | Capacitor_SMD:C_0603_1608Metric |  | C15849 | main | yes | SMT
C1 | 47uF 10V | Capacitor_SMD:C_1206_3216Metric |  | C96123 | main | yes | SMT
C2 | 100nF | Capacitor_SMD:C_0603_1608Metric |  | C14663 | main | yes | SMT
U1 | ESP32-C3-MINI-1-N4 | Espressif:ESP32-C3-MINI-1 | ESP32-C3-MINI-1-N4 | C2838502 | main | yes | SMT
R1 | 10k | Resistor_SMD:R_0603_1608Metric |  | C25804 | main | yes | SMT
C4 | 1uF | Capacitor_SMD:C_0603_1608Metric |  | C15849 | main | yes | SMT
R2 | 10k | Resistor_SMD:R_0603_1608Metric |  | C25804 | main | yes | SMT
R3 | 10k | Resistor_SMD:R_0603_1608Metric |  | C25804 | main | yes | SMT
R4 | 10k | Resistor_SMD:R_0603_1608Metric |  | C25804 | main | yes | SMT
SW1 | PTS810 (BOOT/maintenance) | Button_Switch_SMD:SW_SPST_PTS810 | C&K PTS810 SJM 250 SMTR LFS | C116501 | main | yes | SMT
J3 | PROG (3V3 GND D- D+ EN BOOT 5V) | Connector_PinHeader_2.54mm:PinHeader_1x07_P2.54mm_Vertical |  |  | main | no | THT | Pads only, header not fitted
R19 | 330R | Resistor_SMD:R_0603_1608Metric |  | C23138 | main | DNP (option A7) | SMT
D4 | LED red 0603 | LED_SMD:LED_0603_1608Metric | KT-0603R | C2286 | main | DNP (option A7) | SMT
R5 | 100R | Resistor_SMD:R_0603_1608Metric |  | C22775 | main | yes | SMT
R6 | 100k | Resistor_SMD:R_0603_1608Metric |  | C25803 | main | yes | SMT
Q1 | AO3400A | Package_TO_SOT_SMD:SOT-23 |  | C20917 | main | yes | SMT
D2 | 1N4148W | Diode_SMD:D_SOD-123 |  | C81598 | main | yes | SMT
U2 | SP3485EN | Package_SO:SOIC-8_3.9x4.9mm_P1.27mm | SP3485EN-L/TR | C8963 | main | yes | SMT
C3 | 100nF | Capacitor_SMD:C_0603_1608Metric |  | C14663 | main | yes | SMT
R22 | 10k | Resistor_SMD:R_0603_1608Metric |  | C25804 | main | yes | SMT
D1 | SM712 | Package_TO_SOT_SMD:SOT-23 | SM712.TCT | C12067 | main | yes | SMT
J2 | DMX tail (1 GND 2 B 3 A) | Connector_Wire:SolderWire-0.25sqmm_1x03_P4.2mm_D0.65mm_OD1.7mm |  |  | main | no | THT | Wire pads
J5 | WAGO 2604-1102 (VLED_IN GND_LED) | dmxnow:TerminalBlock_WAGO_2604-1102_1x02_P5.00mm_Horizontal | 2604-1102 | C3309286 | strip | yes | THT
F2 | ATO holder + 20A fuse | Fuse:FuseHolder_Blade_ATO_Littelfuse_FLR_178.6165 | Littelfuse 178.6165.0002 | C207061 | strip | yes | THT
D3 | SMBJ28A | Diode_SMD:D_SMB | SMBJ28A | C113997 | strip | yes | SMT
C7 | 470uF 35V low ESR | Capacitor_THT:CP_Radial_D10.0mm_P5.00mm | Nichicon UHW1V471MPD | C136284 | strip | yes | THT | 2 A ripple at 100 kHz (V-HW-08)
C8 | 1uF 50V | Capacitor_SMD:C_1206_3216Metric |  | C1848 | strip | yes | SMT
U4 | 74AHCT125 | Package_SO:SOIC-14_3.9x8.7mm_P1.27mm | SN74AHCT125DR | C155176 | strip | yes | SMT
C9 | 100nF | Capacitor_SMD:C_0603_1608Metric |  | C14663 | strip | yes | SMT
J6 | WAGO 2604-1102 (VLED CH1) | dmxnow:TerminalBlock_WAGO_2604-1102_1x02_P5.00mm_Horizontal | 2604-1102 | C3309286 | strip | yes | THT
J8 | WAGO 2604-1103 (CH2-CH4) | dmxnow:TerminalBlock_WAGO_2604-1103_1x03_P5.00mm_Horizontal | 2604-1103 | C3309758 | strip | yes | THT
R20 | 0R | Resistor_SMD:R_0805_2012Metric |  | C17477 | strip | yes | SMT | Logic ground to LED ground star point
R21 | 0R | Resistor_SMD:R_0603_1608Metric |  | C21189 | strip | yes | SMT | Variant detection (GPIO1 low = strip part present)
R23 | 100k | Resistor_SMD:R_0603_1608Metric |  | C25803 | main | yes | SMT
R15 | 4.7k | Resistor_SMD:R_0603_1608Metric |  | C23162 | main | yes | SMT | PWM pull-down, main side of the breakaway line, SPEC 4.6
R7 | 100R | Resistor_SMD:R_0603_1608Metric |  | C22775 | strip | yes | SMT
R11 | 100k | Resistor_SMD:R_0603_1608Metric |  | C25803 | strip | yes | SMT
Q2 | AOD2610E | Package_TO_SOT_SMD:TO-252-2 | AOD2610E | C282428 | strip | yes | SMT | 60 V: above the SMBJ28A clamp voltage (R-10)
R16 | 4.7k | Resistor_SMD:R_0603_1608Metric |  | C23162 | main | yes | SMT | PWM pull-down, main side of the breakaway line, SPEC 4.6
R8 | 100R | Resistor_SMD:R_0603_1608Metric |  | C22775 | strip | yes | SMT
R12 | 100k | Resistor_SMD:R_0603_1608Metric |  | C25803 | strip | yes | SMT
Q3 | AOD2610E | Package_TO_SOT_SMD:TO-252-2 | AOD2610E | C282428 | strip | yes | SMT | 60 V: above the SMBJ28A clamp voltage (R-10)
R17 | 4.7k | Resistor_SMD:R_0603_1608Metric |  | C23162 | main | yes | SMT | PWM pull-down, main side of the breakaway line, SPEC 4.6
R9 | 100R | Resistor_SMD:R_0603_1608Metric |  | C22775 | strip | yes | SMT
R13 | 100k | Resistor_SMD:R_0603_1608Metric |  | C25803 | strip | yes | SMT
Q4 | AOD2610E | Package_TO_SOT_SMD:TO-252-2 | AOD2610E | C282428 | strip | yes | SMT | 60 V: above the SMBJ28A clamp voltage (R-10)
R18 | 4.7k | Resistor_SMD:R_0603_1608Metric |  | C23162 | main | yes | SMT | PWM pull-down, main side of the breakaway line, SPEC 4.6
R10 | 100R | Resistor_SMD:R_0603_1608Metric |  | C22775 | strip | yes | SMT
R14 | 100k | Resistor_SMD:R_0603_1608Metric |  | C25803 | strip | yes | SMT
Q5 | AOD2610E | Package_TO_SOT_SMD:TO-252-2 | AOD2610E | C282428 | strip | yes | SMT | 60 V: above the SMBJ28A clamp voltage (R-10)
- | WAGO 221-413 | - | 221-413 |  | full+cut | x1 | off-board | PE junction, 230 V compartment (arbitrage A9)
- | ATO blade fuse 20 A | - | Littelfuse 0257020 |  | full | x1 | off-board | F2 fuse (<= 80 % continuous load, see REVIEW.md)
- | Fuse 5x20 T500mA H 250V ceramic | - | Littelfuse 0215.500MXP |  | full+cut | x1 | off-board | F1 cartridge, into the F1 holder (LCSC C142839)
- | Neutrik NC3FXX | - | NC3FXX |  | full+cut | x1 | off-board | DMX tail connector
- | DMX cable 120 ohm, 1 m | - |  |  | full+cut | x1 | off-board | DMX tail
- | Cable gland M16 (or PG9) | - |  |  | full+cut | x3 | off-board | mains in, projector out, LED PSU out
- | Cable gland PG7 | - |  |  | full+cut | x3 | off-board | DMX tail; LED in/out on full board
- | M3 heat-set insert + M3 nylon screw | - |  |  | full+cut | x6 | off-board | PCB and lid fixing

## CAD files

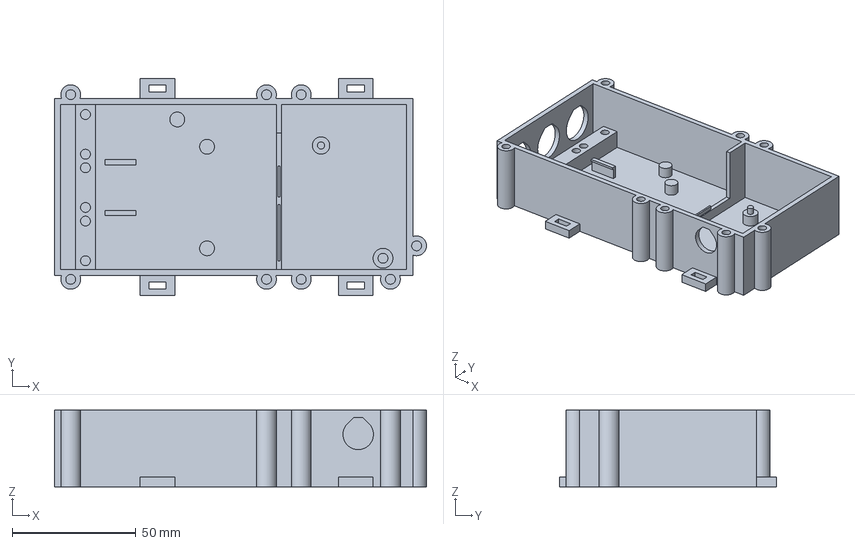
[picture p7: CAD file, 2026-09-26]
enclosure/out/cut/base.step
150.1 x 87.5 x 31.0 mm

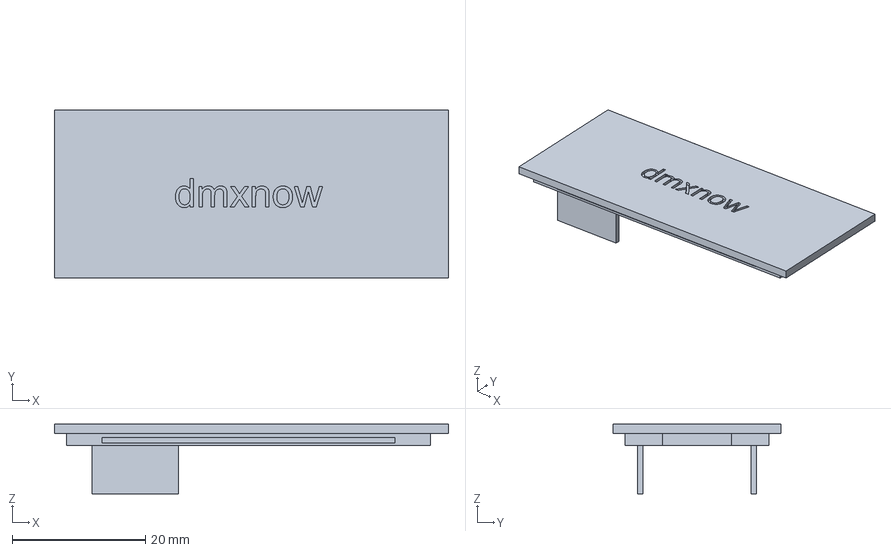
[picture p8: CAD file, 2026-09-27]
enclosure/out/dongle/lid.step
59.1 x 25.2 x 10.4 mm

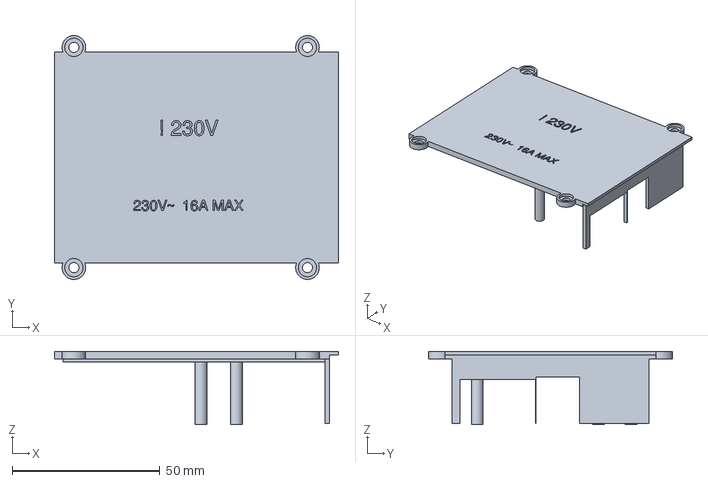
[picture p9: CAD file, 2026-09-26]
enclosure/out/full/cover_230v.step
96.0 x 82.5 x 24.7 mm

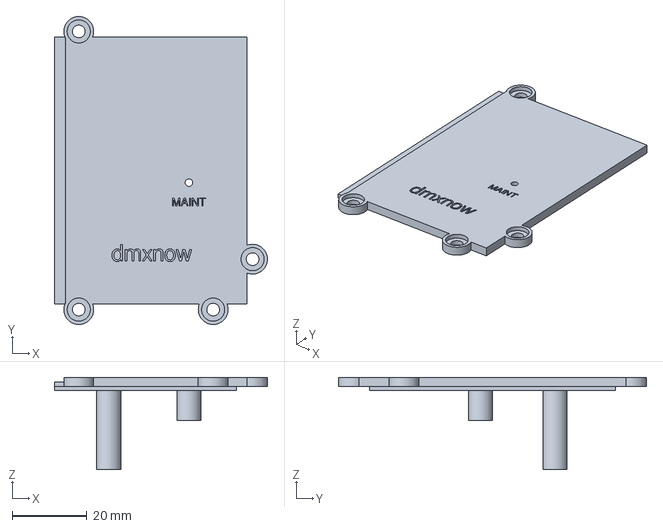
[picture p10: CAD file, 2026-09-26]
enclosure/out/cut/lid_lv.step
57.0 x 82.5 x 24.7 mm

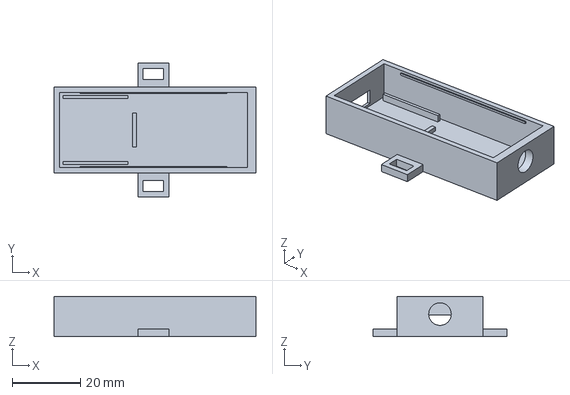
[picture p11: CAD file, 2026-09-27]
enclosure/out/dongle/tray.step
59.1 x 39.2 x 11.8 mm

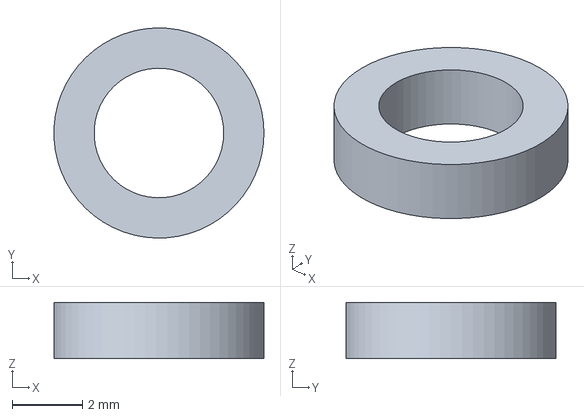
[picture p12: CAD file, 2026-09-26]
enclosure/out/full/sw1_collar.step
6.00 x 6.00 x 1.60 mm

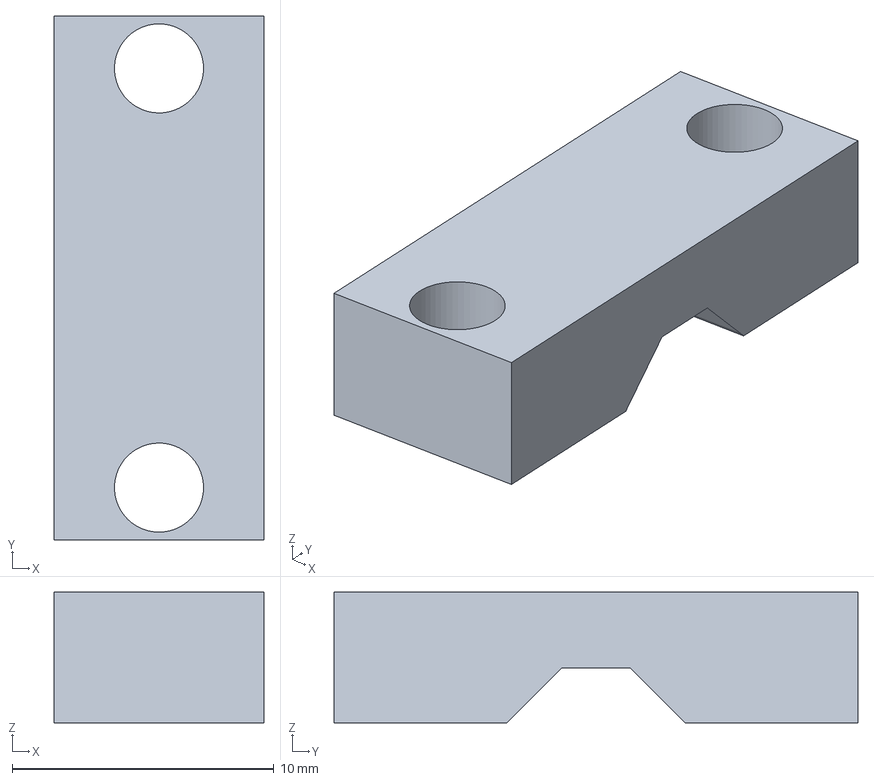
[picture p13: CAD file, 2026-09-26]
enclosure/out/full/clamp_bar.step
8.00 x 20.0 x 5.00 mm

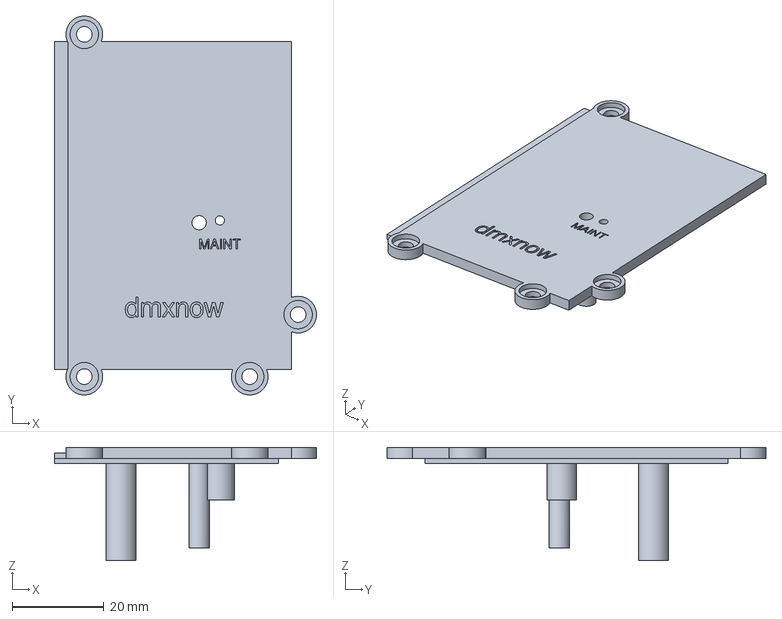
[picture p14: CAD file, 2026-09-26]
enclosure/out/cut/lid_lv_light_pipe.step
57.0 x 82.5 x 24.7 mm

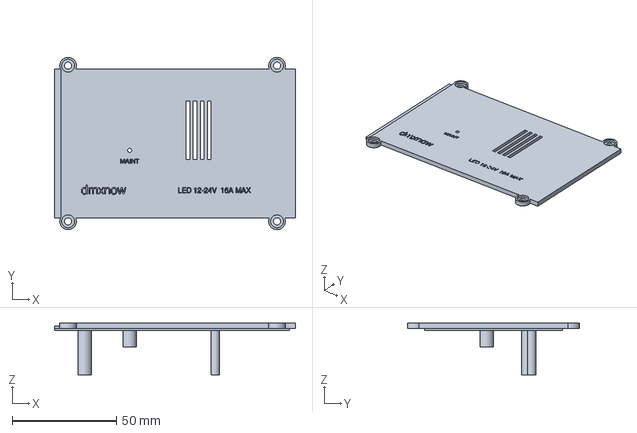
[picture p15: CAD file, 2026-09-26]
enclosure/out/full/lid_lv.step
115.3 x 82.5 x 24.7 mm

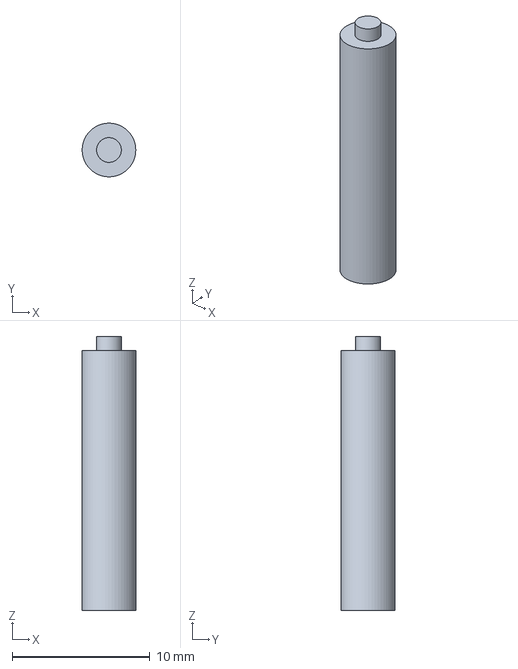
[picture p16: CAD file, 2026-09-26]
enclosure/out/full/sw1_plunger.step
3.90 x 3.90 x 19.9 mm

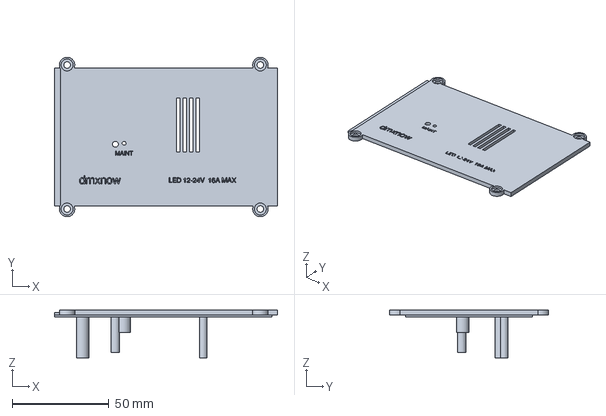
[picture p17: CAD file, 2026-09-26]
enclosure/out/full/lid_lv_light_pipe.step
115.3 x 82.5 x 24.7 mm

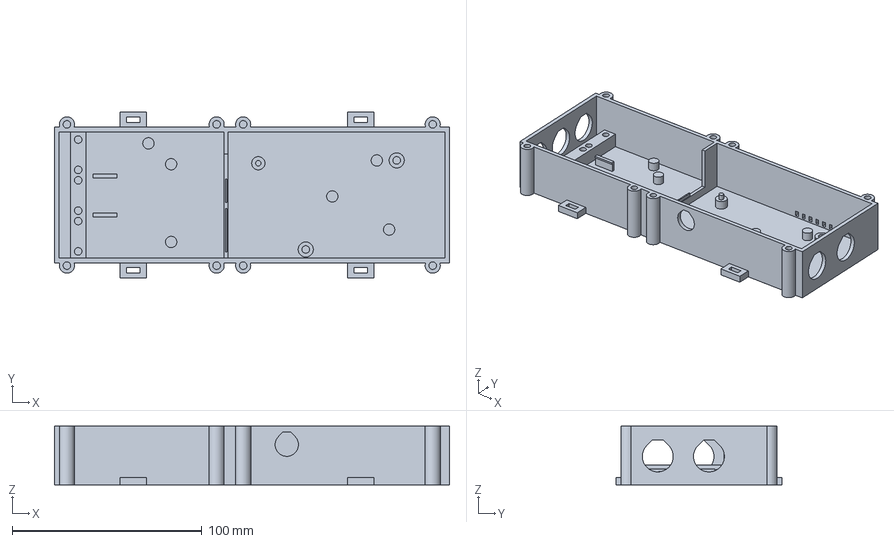
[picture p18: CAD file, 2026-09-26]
enclosure/out/full/base.step
208.4 x 87.5 x 31.0 mm

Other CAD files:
enclosure/out/cut/cover_230v.step
enclosure/out/cut/base.stl
enclosure/out/cut/cover_230v.stl
enclosure/out/cut/lid_lv.stl
enclosure/out/cut/lid_lv_light_pipe.stl
enclosure/out/dongle/lid.stl
enclosure/out/dongle/tray.stl
enclosure/out/full/base.stl
enclosure/out/full/clamp_bar.stl
enclosure/out/full/cover_230v.stl
enclosure/out/full/lid_lv.stl
enclosure/out/full/lid_lv_light_pipe.stl
enclosure/out/full/sw1_collar.stl
enclosure/out/full/sw1_plunger.stl

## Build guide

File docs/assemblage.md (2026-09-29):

# Assemblage

🔴 Les étapes marquées 🔴 touchent à l'isolement secteur : **relecture humaine
obligatoire** ([securite.md](securite.md)).

## 1. Réception des cartes

Les cartes arrivent assemblées par JLCPCB ([hardware/ORDER.md](../hardware/ORDER.md)),
en une seule pièce (partie principale + partie rubans), **sans fusibles**.

Rendu JLCPCB des gerbers commandés (carte v0.3), pour repérer les composants :

Carte dmxnow v0.3, face top (rendu JLCPCB)

Face bottom, vue par transparence (même sens que la face top) :

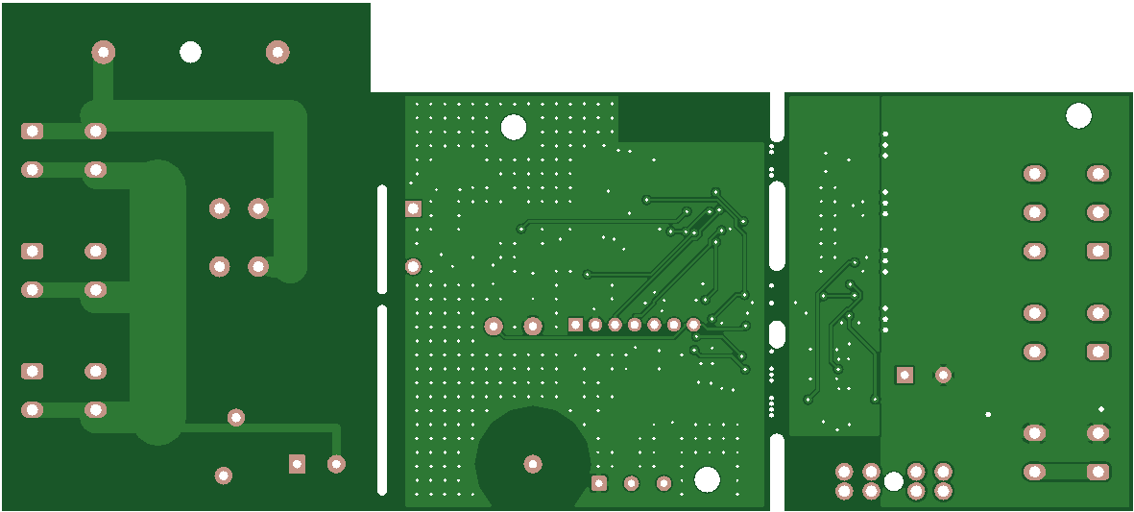
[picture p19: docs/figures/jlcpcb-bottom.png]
Carte dmxnow v0.3, face bottom (rendu JLCPCB)


De gauche à droite :

- la partie secteur : J1, J4, J7, F1, RV1 ;
- K1 et PS1, à cheval sur les fentes d'isolement (les traits blancs verticaux) ;
- la partie commande : U1 et sa zone d'antenne, U2, U3, J2 (DMX), J3 (pastilles de
  flash), SW1 ;
- la partie rubans : U4, Q2 à Q5, J5, J6, J8, F2, C7, reliée au reste par trois
  onglets sécables.

### Retirer les rails de JLCPCB

Pour l'assemblage, JLCPCB ajoute un rail de 5 mm en haut et en bas de la carte (elle
passe à 146 × 75,5 mm). À leur demande (mail du 2026-09-29), le rail du haut tient aussi
la partie rubans par un petit pont à trous de rupture, près du coin haut droit, vers
X = 131 à 135 mm : sans lui, la partie rubans ne tenait que par les trois onglets et le
rail du bas, et risquait de casser en production. Aucune piste ne traverse ce pont.

1. Casser d'abord ce pont : tenir la partie rubans **tout près du pont**, entre le pont
   et le trou de fixation H3, et plier le rail vers la face arrière. Ne pas faire levier
   sur Q5, un MOSFET DPAK soudé à environ 1 cm du pont.
2. Casser ensuite les rails haut et bas sur toute leur longueur, de la même façon.
3. Ébavurer les bords à la lime douce.

**Ne pas toucher aux trois onglets** entre la partie principale et la partie rubans
(X = 100 mm) à cette étape : ils portent sept pistes. Les casser ou non se décide au §3.

Contrôle à réception, carte hors tension :

- [ ] aucun composant manquant ni de travers (K1, PS1, borniers WAGO, F1, F2, RV1, C7) ;
- [ ] fentes d'isolement fraisées sous K1 et PS1, dégagées (pas de résidu de flux ni de
      soudure) ; 🔴
- [ ] pastilles J2 et J3 non soudées, trous ouverts ;
- [ ] à l'ohmmètre : aucune continuité entre L, N (J1) et GND ; entre L et N (J1) :
      circuit ouvert ou haute impédance (entrée de PS1). 🔴

Les essais du prototype (diélectrique, charge, commutations) sont décrits dans
[securite.md §3](securite.md) et [hardware/REVIEW.md §6](../hardware/REVIEW.md) : ils
précèdent l'utilisation de toute la série.

## 2. Fusibles

| Repère | Fusible | Où l'acheter |
|---|---|---|
| F1 🔴 | Cartouche **T500 mA H 250 V céramique 5×20** (Littelfuse 0215.500MXP) | Hors JLCPCB ([ORDER.md](../hardware/ORDER.md)) |
| F2 | Fusible lame **ATO 20 A** (carte entière seulement) | Hors JLCPCB |

F1 se clipse dans son support. F2 s'enfonce dans son support (partie rubans) ; sur une
carte cassée, F2 n'existe plus.

## 3. Partie rubans : garder ou casser ?

| Besoin | Carte | Boîtier |
|---|---|---|
| Projecteur + rubans | **Entière** (146 mm) | variante `full` |
| Projecteur seul | **Cassée** (100 mm) | variante `cut` |

Pour casser : **scier** les trois languettes perforées le long de la fente, au ras de la
partie principale, carte tenue dans un étau à mors doux ; ébavurer à la lime. Ne pas
casser à la main (efforts sur les pistes des languettes et sur les soudures voisines ;
[REVIEW.md §7.3](../hardware/REVIEW.md)). Le firmware détecte seul la variante au
démarrage (BOARD_SENSE, EF-07).

## 4. Impression du boîtier du nœud

Fichiers : `enclosure/out/full/*.stl` ou `enclosure/out/cut/*.stl`, déjà en position
d'impression. Détail, cotes et achats : [enclosure/README.md](../enclosure/README.md).

| Pièce | Qté |
|---|-----|
| `base` | 1 |
| `cover_230v` (couvercle 230 V) | 1 |
| `lid_lv` (couvercle basse tension ; `lid_lv_light_pipe` si la LED D4 est montée) | 1 |
| `clamp_bar` (barre d'étrier) | 3 |
| `sw1_plunger` + `sw1_collar` | 1 + 1 |

- 🔴 Matériau **ABS-FR ou PC-ABS-FR UL94 V-0**. PLA, PETG et ABS standard sont interdits
  pour ce boîtier. Garder la fiche du filament.
- **100 % de remplissage**, imprimante fermée, buse 240 à 260 °C, plateau 100 °C,
  bordure (« brim ») sur la base. Aucun support.
- Contrôler chaque pièce : pas de délaminage, pas de fissure, cloison et languettes de la
  base entières. Une pièce douteuse se réimprime.

## 5. Montage de la carte dans le boîtier

Achats (presse-étoupes, inserts, vis, WAGO 221-413) : [enclosure/README.md §Achats](../enclosure/README.md).

1. **Inserts à chaud** M3 (Ø 4,0 × 5,7 mm) dans les bossages des couvercles, la sellette
   des étriers et les plots H2 (et H3 sur la carte entière). Insert droit, affleurant.
2. **WAGO 221-413** clipsé dans son logement, chambre de gauche (côté 230 V).
3. **Presse-étoupes** : M16 ×3 côté secteur, M16 ×2 côté rubans (carte entière), M12 pour
   le DMX. Contre-écrous à l'intérieur, **méplat contre méplat** (les trois écrous secteur
   sont serrés les uns contre les autres).
4. **Poussoir SW1** : glisser le poussoir dans son tube par-dessous le couvercle basse
   tension, emmancher (ou coller) le collier.
5. **Flasher le nœud maintenant**, carte encore hors boîtier : [flash.md](flash.md).
6. **Poser la carte** : l'ergot imprimé traverse H1 (pas de vis métallique près de
   l'antenne), les languettes de la cloison entrent dans les fentes d'isolement sous K1
   et PS1 🔴 ; la carte repose à plat sur ses plots. Visser H2 (et H3) : M3 × 6 +
   **rondelle isolante**.
7. Câbler : [cablage.md](cablage.md).
8. Visser le **couvercle basse tension** (M3 × 6), puis le **couvercle 230 V** par-dessus
   son bord (M3 × 6). 🔴 La jupe du couvercle 230 V doit descendre sans forcer entre K1/PS1
   et la cloison.

## 6. Dongle

Boîtier imprimable en PETG ou PLA (pas de secteur) : `enclosure/out/dongle/`. Achats et
montage : [enclosure/README.md §Boîtier du dongle](../enclosure/README.md).

1. Flasher le XIAO **avant** de fermer le boîtier ([flash.md §3](flash.md)) : les boutons
   BOOT et RESET ne sont plus accessibles ensuite (les mises à jour suivantes passent par
   l'USB-C sans bouton).
2. XIAO poussé contre la paroi USB-C ; embase RP-SMA passée de l'intérieur, rondelle et
   écrou à l'extérieur ; câble clipsé sur le connecteur U.FL, lové en boucle de 18 mm au
   moins ; couvercle clipsé ; antenne dipôle **RP-SMA** vissée à la main.
3. Ne jamais faire émettre le dongle sans antenne.

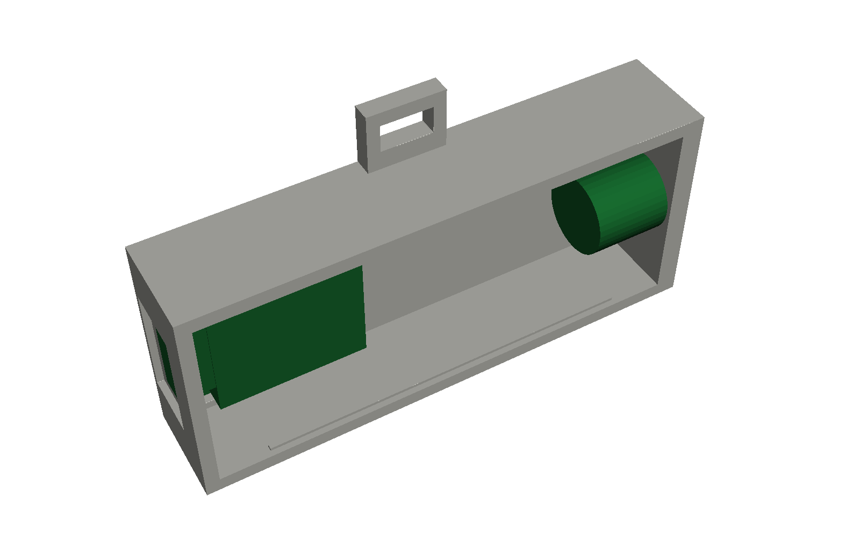
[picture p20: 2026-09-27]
enclosure/out/dongle/assembly_open.png

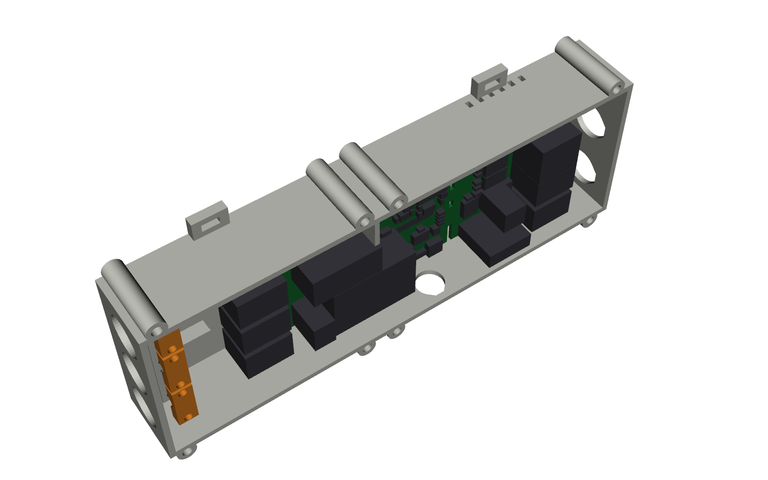
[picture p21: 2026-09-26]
enclosure/out/full/assembly_open.png

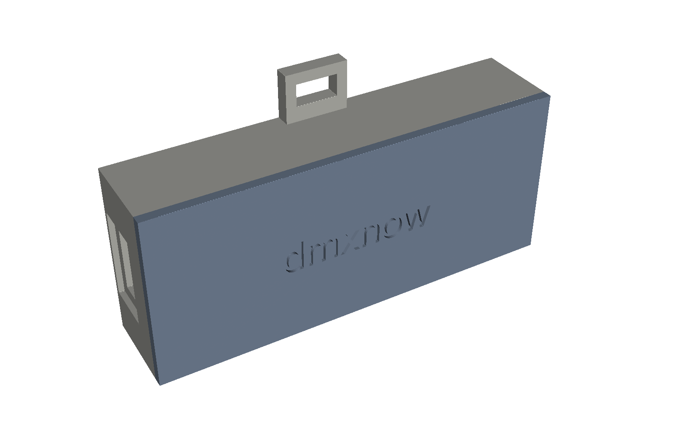
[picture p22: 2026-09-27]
enclosure/out/dongle/assembly_closed.png

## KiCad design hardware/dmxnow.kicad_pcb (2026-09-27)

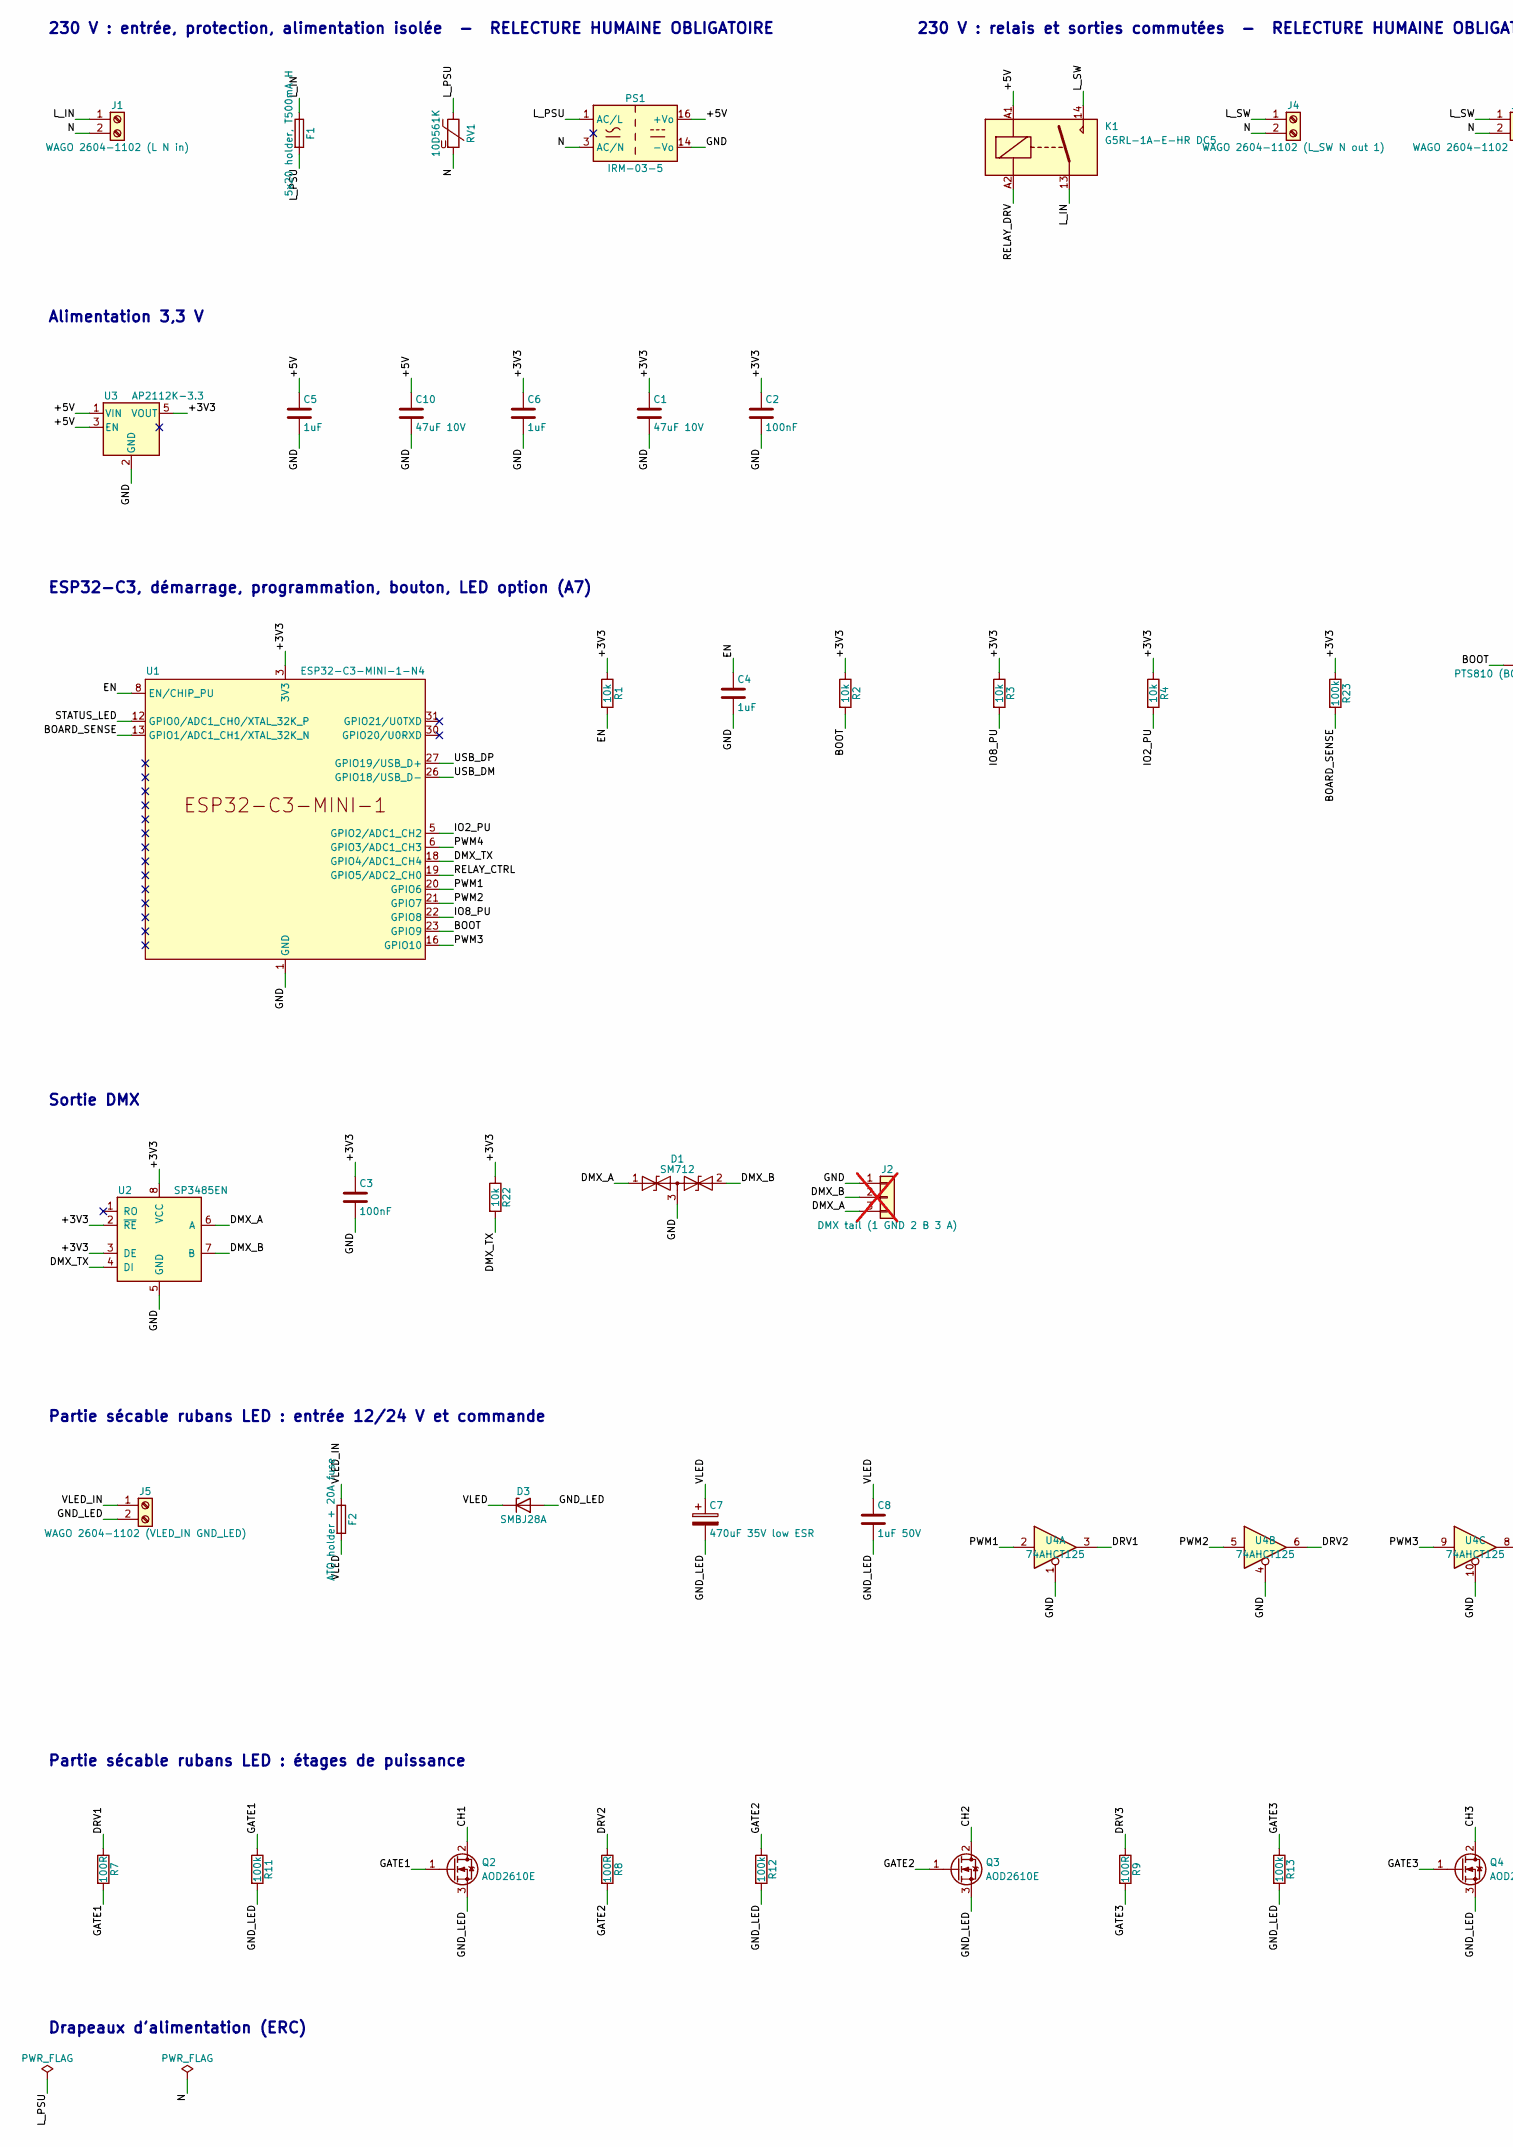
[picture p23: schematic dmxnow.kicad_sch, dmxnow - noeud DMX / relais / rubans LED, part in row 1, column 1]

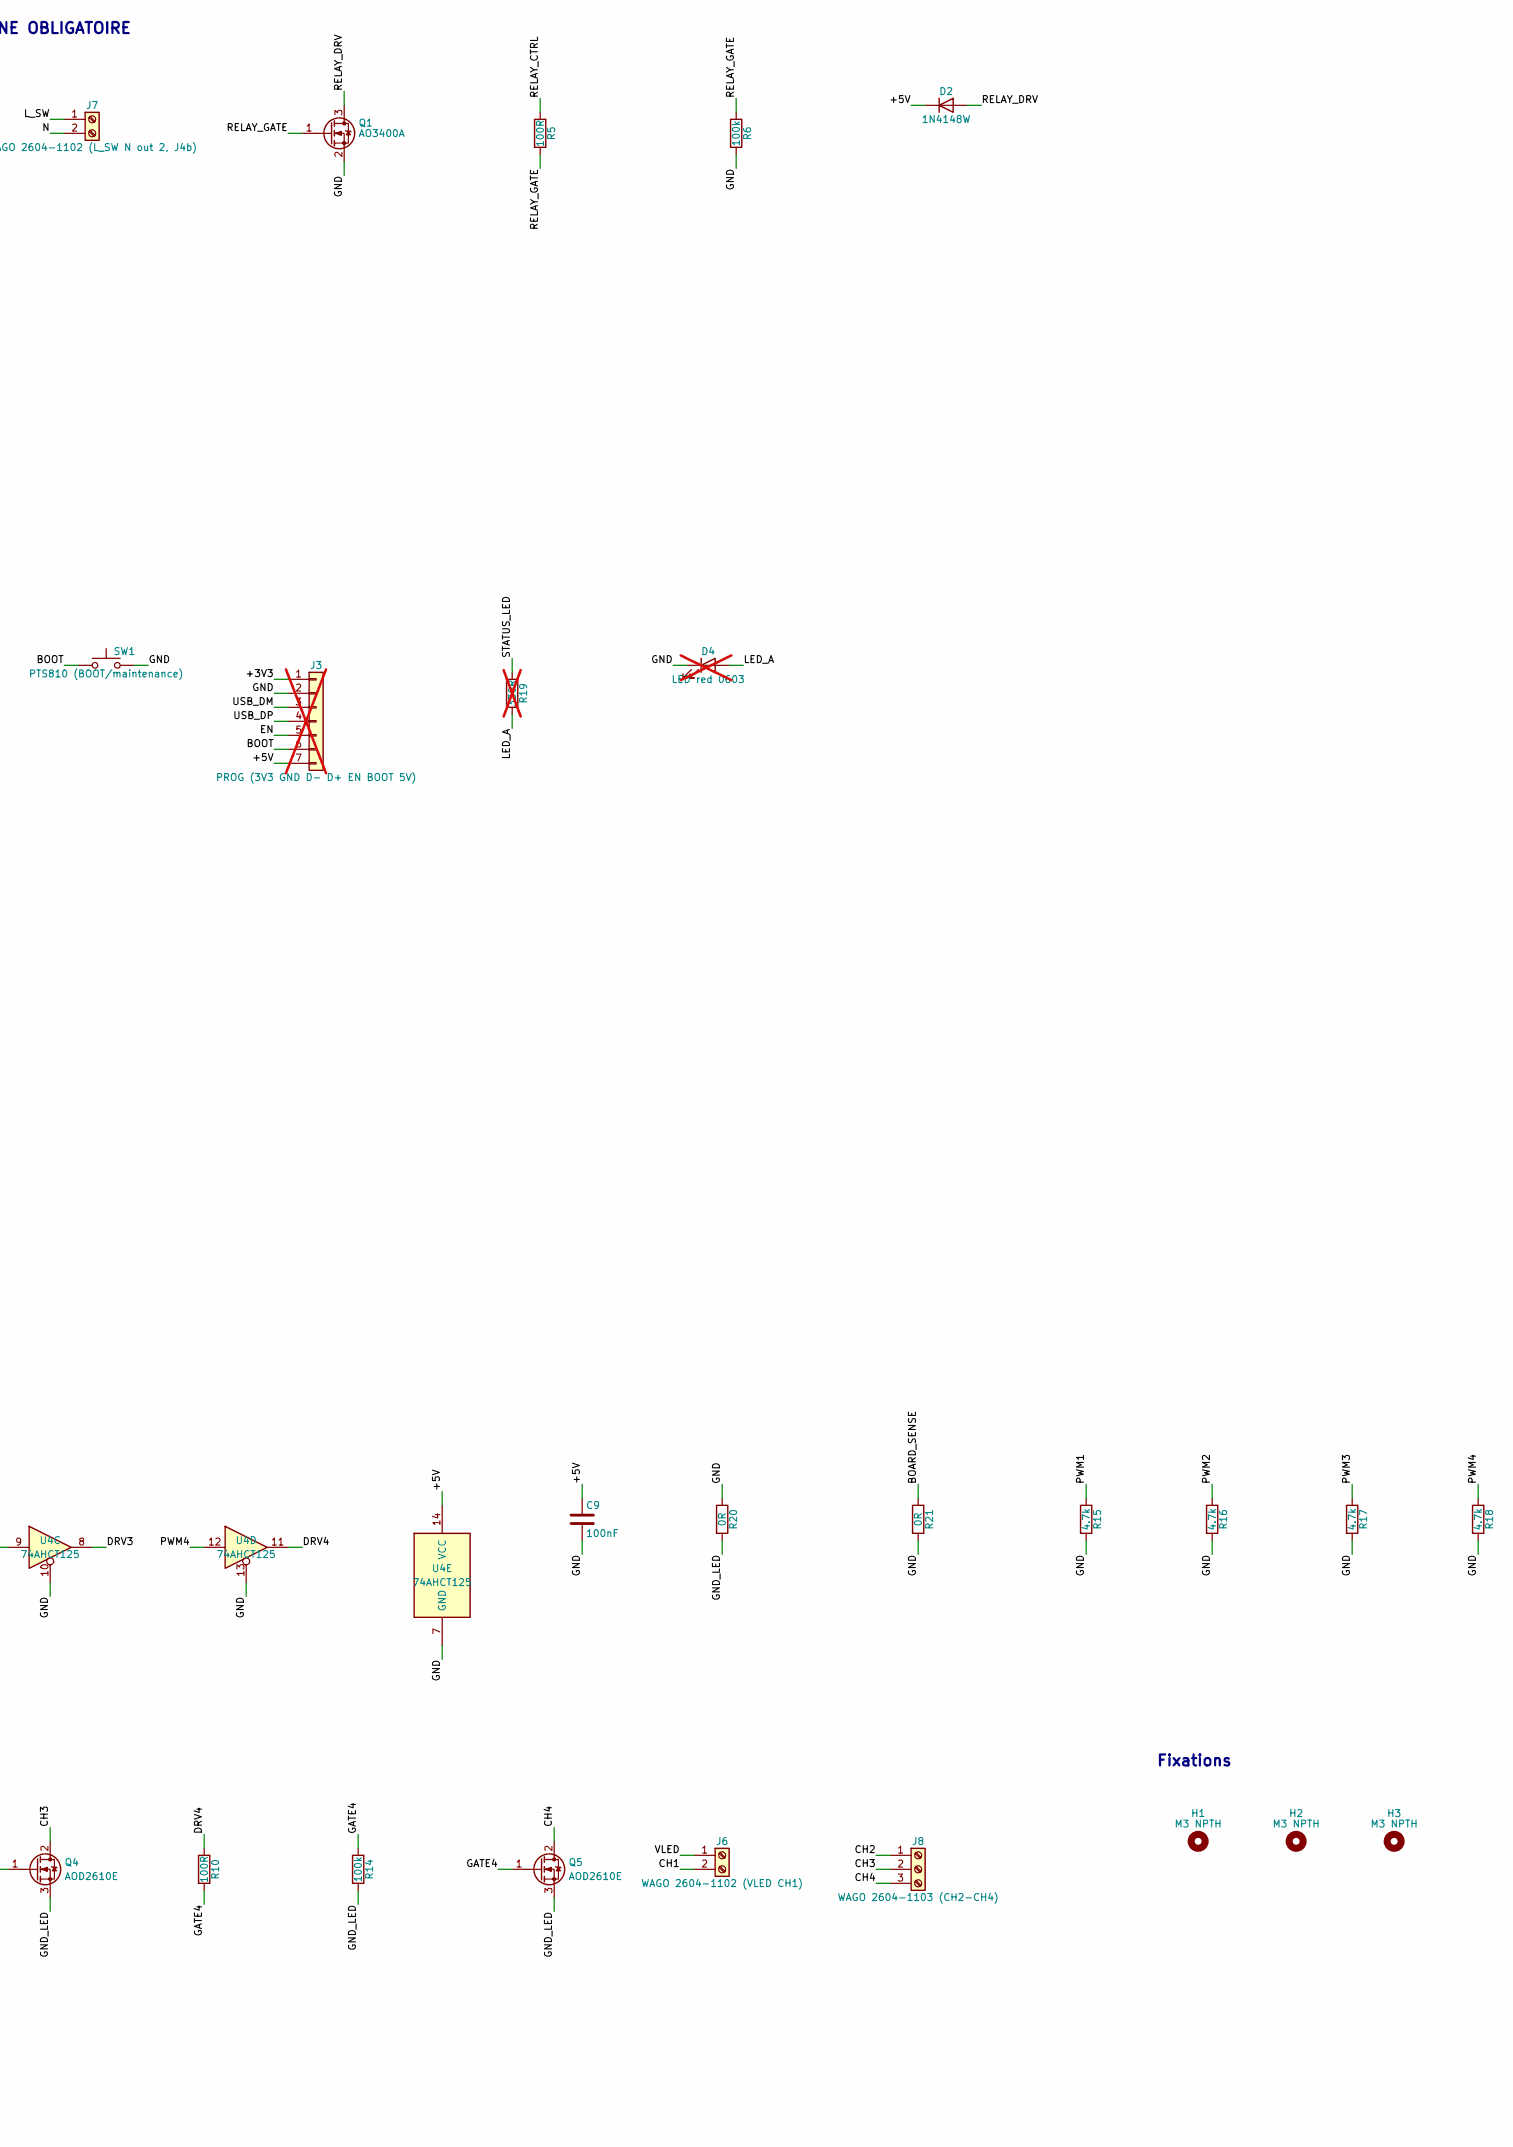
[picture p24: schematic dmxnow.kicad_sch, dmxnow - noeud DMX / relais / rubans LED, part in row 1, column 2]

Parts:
C1, C10: 47uF 10V; C_1206_3216Metric; LCSC C96123
C2, C3, C9: 100nF; C_0603_1608Metric; LCSC C14663
C4, C5, C6: 1uF; C_0603_1608Metric; LCSC C15849
C7: 470uF 35V low ESR; CP_Radial_D10.0mm_P5.00mm; MPN Nichicon UHW1V471MPD; LCSC C136284
C8: 1uF 50V; C_1206_3216Metric; LCSC C1848
D1: SM712; SOT-23; MPN SM712.TCT; LCSC C12067
D2: 1N4148W; D_SOD-123; LCSC C81598
D3: SMBJ28A; D_SMB; MPN SMBJ28A; LCSC C113997
D4: LED red 0603; LED_0603_1608Metric; MPN KT-0603R; LCSC C2286; not fitted
F1: 5x20 holder, T500mA H; Fuseholder_Cylinder-5x20mm_Schurter_0031_8201_Horizontal_Op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; MPN Schurter 0031.8201; LCSC C3204125
F2: ATO holder + 20A fuse; FuseHolder_Blade_ATO_Littelfuse_FLR_178.6165; MPN Littelfuse 178.6165.0002; LCSC C207061
H1, H2, H3: M3 NPTH; MountingHole_3.2mm_M3
J1: WAGO 2604-1102 (L N in); TerminalBlock_WAGO_2604-1102_1x02_P5.00mm_Horizontal; MPN 2604-1102; LCSC C3309286
J2: DMX tail (1 GND 2 B 3 A); SolderWire-0.25sqmm_1x03_P4.2mm_D0.65mm_OD1.7mm; not fitted
J3: PROG (3V3 GND D- D+ EN BOOT 5V); PinHeader_1x07_P2.54mm_Vertical; not fitted
J4: WAGO 2604-1102 (L_SW N out 1); TerminalBlock_WAGO_2604-1102_1x02_P5.00mm_Horizontal; MPN 2604-1102; LCSC C3309286
J5: WAGO 2604-1102 (VLED_IN GND_LED); TerminalBlock_WAGO_2604-1102_1x02_P5.00mm_Horizontal; MPN 2604-1102; LCSC C3309286
J6: WAGO 2604-1102 (VLED CH1); TerminalBlock_WAGO_2604-1102_1x02_P5.00mm_Horizontal; MPN 2604-1102; LCSC C3309286
J7: WAGO 2604-1102 (L_SW N out 2, J4b); TerminalBlock_WAGO_2604-1102_1x02_P5.00mm_Horizontal; MPN 2604-1102; LCSC C3309286
J8: WAGO 2604-1103 (CH2-CH4); TerminalBlock_WAGO_2604-1103_1x03_P5.00mm_Horizontal; MPN 2604-1103; LCSC C3309758
K1: G5RL-1A-E-HR DC5; Relay_SPST_Omron_G5RL-1A-E-HR; MPN Omron G5RL-1A-E-HR DC5; LCSC C113250
PS1: IRM-03-5; Converter_ACDC_MeanWell_IRM-03-xx_THT_Drill1.0; MPN MEAN WELL IRM-03-5; LCSC C6969425
Q1: AO3400A; SOT-23; LCSC C20917
Q2, Q3, Q4, Q5: AOD2610E; TO-252-2; MPN AOD2610E; LCSC C282428
R1, R2, R3, R4, R22: 10k; R_0603_1608Metric; LCSC C25804
R5, R7, R8, R9, R10: 100R; R_0603_1608Metric; LCSC C22775
R6, R11, R12, R13, R14, R23: 100k; R_0603_1608Metric; LCSC C25803
R15, R16, R17, R18: 4.7k; R_0603_1608Metric; LCSC C23162
R19: 330R; R_0603_1608Metric; LCSC C23138; not fitted
R20: 0R; R_0805_2012Metric; LCSC C17477
R21: 0R; R_0603_1608Metric; LCSC C21189
RV1: 10D561K; RV_Disc_D12mm_T9mm_P7.5mm_Drill1.1; MPN 10D561K; LCSC C113236
SW1: PTS810 (BOOT/maintenance); SW_SPST_PTS810; MPN C&K PTS810 SJM 250 SMTR LFS; LCSC C116501
U1: ESP32-C3-MINI-1-N4; ESP32-C3-MINI-1; MPN ESP32-C3-MINI-1-N4; LCSC C2838502
U2: SP3485EN; SOIC-8_3.9x4.9mm_P1.27mm; MPN SP3485EN-L/TR; LCSC C8963
U3: AP2112K-3.3; SOT-23-5; MPN AP2112K-3.3TRG1; LCSC C51118
U4: 74AHCT125; SOIC-14_3.9x8.7mm_P1.27mm; MPN SN74AHCT125DR; LCSC C155176

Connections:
+3V3: C1.1, C2.1, C3.1, C6.1, J3.1, R1.1, R2.1, R3.1, R4.1, R22.1, R23.1, U1.3 (3V3), U2.2 (~RE), U2.3 (DE), U2.8 (VCC), U3.5 (VOUT)
+5V: C5.1, C9.1, C10.1, D2.1 (K), J3.7, K1.A1, PS1.16 (+Vo), U3.1 (VIN), U3.3 (EN), U4.14 (VCC)
BOARD_SENSE: R21.1, R23.2, U1.13 (GPIO1/ADC1_CH1/XTAL_32K_N)
BOOT: J3.6, R2.2, SW1.1, U1.23 (GPIO9)
CH1: J6.2, Q2.2 (D)
CH2: J8.1, Q3.2 (D)
CH3: J8.2, Q4.2 (D)
CH4: J8.3, Q5.2 (D)
DMX_A: D1.1 (A1), J2.3, U2.6 (A)
DMX_B: D1.2 (A2), J2.2, U2.7 (B)
DMX_TX: R22.2, U1.18 (GPIO4/ADC1_CH4), U2.4 (DI)
DRV1: R7.1, U4.3
DRV2: R8.1, U4.6
DRV3: R9.1, U4.8
DRV4: R10.1, U4.11
EN: C4.1, J3.5, R1.2, U1.8 (EN/CHIP_PU)
GATE1: Q2.1 (G), R7.2, R11.1
GATE2: Q3.1 (G), R8.2, R12.1
GATE3: Q4.1 (G), R9.2, R13.1
GATE4: Q5.1 (G), R10.2, R14.1
GND: C1.2, C2.2, C3.2, C4.2, C5.2, C6.2, C9.2, C10.2, D1.3 (common), D4.1 (K), J2.1, J3.2, PS1.14 (-Vo), Q1.2 (S), R6.2, R15.2, R16.2, R17.2, R18.2, R20.1, R21.2, SW1.2, U1.1 (GND), U1.2 (GND), U1.11 (GND), U1.14 (GND), U1.36 (GND), U1.37 (GND), U1.38 (GND), U1.39 (GND), U1.40 (GND), U1.41 (GND), U1.42 (GND), U1.43 (GND), U1.44 (GND), U1.45 (GND), U1.46 (GND), U1.47 (GND), U1.48 (GND), U1.49 (GND), U1.50 (GND), U1.51 (GND), U1.52 (GND), U1.53 (GND), U2.5 (GND), U3.2 (GND), U4.1, U4.4, U4.7 (GND), U4.10, U4.13
GND_LED: C7.2, C8.2, D3.2 (A), J5.2, Q2.3 (S), Q3.3 (S), Q4.3 (S), Q5.3 (S), R11.2, R12.2, R13.2, R14.2, R20.2
IO2_PU: R4.2, U1.5 (GPIO2/ADC1_CH2)
IO8_PU: R3.2, U1.22 (GPIO8)
LED_A: D4.2 (A), R19.2
L_IN: F1.1, J1.1, K1.13
L_PSU: F1.2, PS1.1 (AC/L), RV1.1
L_SW: J4.1, J7.1, K1.14
N: J1.2, J4.2, J7.2, PS1.3 (AC/N), RV1.2
PWM1: R15.1, U1.20 (GPIO6), U4.2
PWM2: R16.1, U1.21 (GPIO7), U4.5
PWM3: R17.1, U1.16 (GPIO10), U4.9
PWM4: R18.1, U1.6 (GPIO3/ADC1_CH3), U4.12
RELAY_CTRL: R5.1, U1.19 (GPIO5/ADC2_CH0)
RELAY_DRV: D2.2 (A), K1.A2, Q1.3 (D)
RELAY_GATE: Q1.1 (G), R5.2, R6.1
STATUS_LED: R19.1, U1.12 (GPIO0/ADC1_CH0/XTAL_32K_P)
USB_DM: J3.3, U1.26 (GPIO18/USB_D-)
USB_DP: J3.4, U1.27 (GPIO19/USB_D+)
VLED: C7.1, C8.1, D3.1 (K), F2.2, J6.1
VLED_IN: F2.1, J5.1

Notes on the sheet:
230 V : entrée, protection, alimentation isolée - RELECTURE HUMAINE OBLIGATOIRE
230 V : relais et sorties commutées - RELECTURE HUMAINE OBLIGATOIRE
Alimentation 3,3 V
ESP32-C3, démarrage, programmation, bouton, LED option (A7)
Sortie DMX
Partie sécable rubans LED : entrée 12/24 V et commande
Partie sécable rubans LED : étages de puissance
Fixations
Drapeaux d'alimentation (ERC)

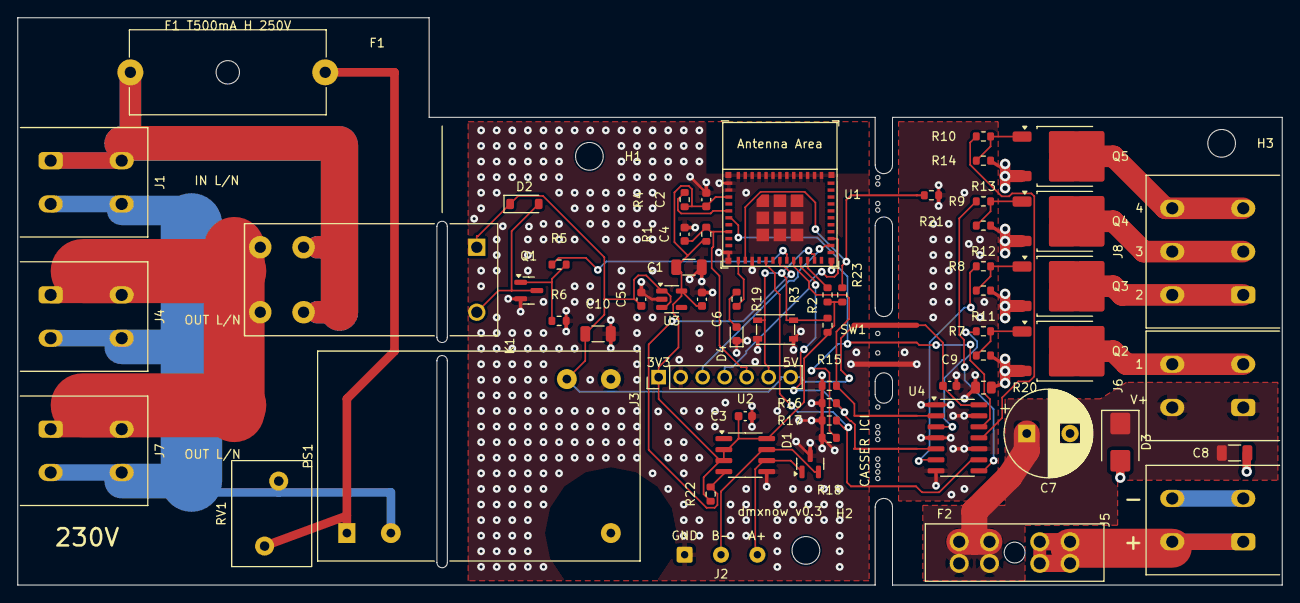
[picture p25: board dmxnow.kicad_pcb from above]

Board: 2 copper layers, 146.0 x 65.5 mm, 77 parts (0 on the bottom side), 41 nets.

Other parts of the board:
MB: (no value)
MB#2, MB#3, MB#4, MB#5, MB#6, MB#7, MB#8, MB#9, MB#10, MB#11, MB#12, MB#13, MB#14: (no value)

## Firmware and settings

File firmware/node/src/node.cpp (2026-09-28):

#include "node.h"

#include <Arduino.h>
#include <esp_mac.h>
#include <esp_ota_ops.h>
#include <esp_random.h>
#include <esp_system.h>
#include <esp_timer.h>

#include <cstring>

#include "board.h"
#include "dmx_out.h"
#include "dmxnow/auth.h"
#include "dmxnow/config.h"
#include "dmxnow/dmx.h"
#include "dmxnow/gamma.h"
#include "dmxnow/protocol.h"
#include "dmxnow/relay.h"
#include "maintenance.h"
#include "pwm_out.h"
#include "radio.h"
#include "store.h"

using namespace dmxnow;

// Arduino-ESP32: the image is validated by the application (first valid radio packet),
// not automatically at boot (SPEC 4.9, V-FW-06).
extern "C" bool verifyRollbackLater() { return true; }

namespace node {

namespace {
constexpr uint8_t kFw[3] = {DMXNOW_FW_MAJOR, DMXNOW_FW_MINOR, DMXNOW_FW_PATCH};
constexpr uint32_t kHeartbeatMs = 2000, kHeartbeatJitterMs = 250;
constexpr uint32_t kDongleForgetMs = 30000;
constexpr uint32_t kStreamPresentMs = 1000;
constexpr uint32_t kScanAfterMs = 60000, kScanDwellMs = 300;
constexpr uint32_t kOtaValidateMs = 60000;
constexpr uint32_t kRebootDelayMs = 600;
constexpr uint32_t kPowerCycleWindowMs = 5000;
constexpr uint32_t kButtonDebounceMs = 20, kButtonMaintMs = 3000, kButtonResetMs = 10000;

NodeConfig cfg;
Variant variant = Variant::FixtureOnly;
Footprint fp;
uint8_t mac[6];

RelayLogic relay;
Reassembler reasm;
LossCounter loss;
GammaTable gamma;
CommandHistory history;
uint32_t auth_last = 0;

// radio / network
bool dongle_known = false;
uint8_t dongle[6];
uint32_t dongle_seen_ms = 0;
uint32_t net_seen_ms = 0;         // last valid packet of our network
uint32_t stream_ms = 0;           // last DMX_DATA of our universe
bool have_stream = false;
int16_t rssi_x8 = 0;              // EMA alpha 1/8, scaled x8
bool rssi_init = false;
uint16_t hb_seq = 0;
uint32_t next_hb_ms = 0;

// scan (A5)
bool scanning = false;
uint8_t scan_ch = 1;
uint32_t scan_step_ms = 0;

// outputs
uint8_t frame[kDmxSlots];
uint16_t frame_len = 0;
bool blackout = false;
uint32_t fade_start_ms = 0;
bool fading = false;
uint32_t identify_until = 0;
bool identifying = false;

// deferred actions
uint32_t channel_at = 0;
uint8_t channel_new = 0;
uint32_t reboot_at = 0;
bool factory_at_reboot = false;
bool ota_pending_verify = false;

// button
bool btn_down = false;
uint32_t btn_since = 0;
bool btn_reset_done = false;
uint32_t btn_raw_since = 0;
bool btn_raw = false;

bool boot_counter_cleared = false;

uint32_t now_ms() { return millis(); }
uint32_t uptime_s() { return uint32_t(esp_timer_get_time() / 1000000); }

void schedule_heartbeat() { next_hb_ms = now_ms(); }

// --- outputs ------------------------------------------------------------------------
void update_pwm() {
    if (variant != Variant::WithStrips) return;
    uint32_t now = now_ms();
    bool blink_on = identifying && ((now / 500) % 2 == 0);
    uint32_t fade_q16 = 65536;   // fade factor, 16.16
    if (fading) {
        uint32_t el = now - fade_start_ms;
        if (cfg.fade_on_ms == 0 || el >= cfg.fade_on_ms) fading = false;
        else fade_q16 = uint32_t((uint64_t(el) << 16) / cfg.fade_on_ms);
    }
    for (uint8_t ch = 0; ch < 4; ++ch) {
        uint32_t duty;
        if (identifying) {
            duty = blink_on ? gamma.max_duty() : 0;
        } else if (blackout) {
            duty = 0;
        } else {
            uint16_t v = pwm_value(fp, frame, frame_len, ch);
            if (fading) v = uint16_t((uint32_t(v) * fade_q16) >> 16);   // perceptual ramp, before gamma
            duty = (!fp.pwm16 && !fading) ? gamma.lookup8(uint8_t(v >> 8)) : gamma.lookup16(v);
        }
        pwm_out::set(ch, duty);
    }
}

void start_fade() {
    fading = true;
    fade_start_ms = now_ms();
}

void apply_relay_gpio() {
    digitalWrite(board::kRelay, relay.state() ? HIGH : LOW);
    store::save_relay(relay.state(), relay.switch_count());   // only on an effective switch
    if (relay.state()) start_fade();                         // LED supply restarts (SPEC 4.7)
    schedule_heartbeat();
}

void apply_identify_dmx() {
    // pushed to the DMX task only on a change (each push triggers an output frame)
    static uint16_t last_slot = 0;
    static uint8_t last_value = 0;
    uint16_t slot = identifying ? cfg.identify_slot : 0;
    uint8_t value = (slot && (now_ms() / 500) % 2 == 0) ? 255 : 0;
    if (slot == last_slot && value == last_value) return;
    last_slot = slot;
    last_value = value;
    dmx_out::set_override(slot, value);
}

void configure_outputs() {
    fp = footprint(cfg, variant);
    dmx_out::set_slots(cfg.dmx_out_slots);
    relay.set_relay_dmx(cfg.relay_dmx);
    relay.set_min_interval(cfg.relay_min_interval_ms);
    if (variant == Variant::WithStrips) {
        static uint16_t freq = 0;   // the LEDC is reconfigured only when the frequency changes
        if (freq != cfg.pwm_freq_hz && pwm_out::begin(cfg.pwm_freq_hz)) freq = cfg.pwm_freq_hz;
        gamma.build(cfg.gamma_x10, pwm_out::bits());
        update_pwm();
    }
}

// --- radio output -------------------------------------------------------------------
void send_packet(MsgType type, uint16_t net_id, uint16_t universe, uint16_t seq, const uint8_t* payload,
                 size_t len) {
    uint8_t buf[kHeaderSize + 256];
    Header h;
    h.type = uint8_t(type);
    h.net_id = net_id;
    h.universe = universe;
    h.seq = seq;
    size_t n = build_packet(h, payload, len, nullptr, buf, sizeof buf);
    if (n) radio::send(dongle_known ? dongle : nullptr, buf, n);
}

void send_heartbeat() {
    Heartbeat hb;
    std::memcpy(hb.mac, mac, 6);
    std::strncpy(hb.name, cfg.name, 16);
    hb.start_address = cfg.start_address;
    std::memcpy(hb.fw_version, kFw, 3);
    hb.variant = uint8_t(variant);
    hb.relay = relay.heartbeat_bits();
    hb.relay_switch_count = relay.switch_count();
    hb.rssi = int8_t(rssi_x8 / 8);
    hb.rx_frames = loss.rx_frames();
    hb.lost_frames = loss.lost_frames();
    hb.rejected_frames = radio::rejected();
    hb.uptime_s = uptime_s();
    hb.status = uint8_t((have_stream ? hb_status::kDmx : 0) | (blackout ? hb_status::kBlackout : 0) |
                        (maint::active() ? hb_status::kMaintenance : 0) | (identifying ? hb_status::kIdentify : 0) |
                        (dongle_known ? hb_status::kDongleKnown : 0));
    hb.radio_channel = radio::channel();
    hb.dmx_out_slots = cfg.dmx_out_slots;
    hb.reset_reason = uint8_t(esp_reset_reason());
    uint8_t p[kHeartbeatPayload];
    encode_heartbeat(hb, p);
    send_packet(MsgType::Heartbeat, cfg.net_id, cfg.universe, hb_seq++, p, sizeof p);
}

// --- commands -----------------------------------------------------------------------
void enter_maintenance(uint16_t timeout_s);

AckStatus apply_config(const uint8_t* tlv, size_t len) {
    NodeConfig n = cfg;
    uint32_t changed = 0;
    AckStatus st = apply_config_tlv(tlv, len, variant, &n, &changed);
    if (st != AckStatus::Ok) return st;
    uint16_t old_universe = cfg.universe;
    cfg = n;
    store::save_config(cfg);
    if (changed & (1u << key::kNetId)) radio::set_net_id(cfg.net_id);
    if (cfg.universe != old_universe) {
        reasm = Reassembler();
        loss = LossCounter();
        have_stream = false;
    }
    if ((changed & (1u << key::kRadioChannel)) && cfg.radio_channel != radio::channel()) {
        channel_new = cfg.radio_channel;          // applied 500 ms after the ACK
        channel_at = now_ms() + 500;
    }
    if (changed & (1u << key::kStatusLed)) {
        if (cfg.status_led) pinMode(board::kStatusLed, OUTPUT);
        else digitalWrite(board::kStatusLed, LOW);
    }
    configure_outputs();
    schedule_heartbeat();
    return AckStatus::Ok;
}

void set_relay_mode(uint8_t mode) {
    relay.command(RelayLogic::Force(mode), now_ms());
    schedule_heartbeat();
}

void handle_command(const radio::Packet& p, const Header& h) {
    CommandView cmd;
    if (!parse_command(p.data + kHeaderSize, h.length, &cmd)) return;
    if (!mac_is_broadcast(cmd.target) && std::memcmp(cmd.target, mac, 6) != 0) return;   // not for us

    uint8_t ack[CommandHistory::kMaxAck];
    size_t ack_len = 0;
    const uint8_t* old = history.find(h.seq, &ack_len);
    if (old) {   // repeated command: not executed again, same answer (PROTOCOL 6.2)
        send_packet(MsgType::Ack, h.net_id, kNoUniverse, h.seq, old, ack_len);
        return;
    }
    Opcode op = Opcode(cmd.opcode);
    AckStatus st = AckStatus::Ok;
    ack_len = 2;

    if (cfg.has_net_key && op != Opcode::Identify) {
        uint32_t counter = 0;
        if (auth_check(cfg.net_key, p.data, p.len, auth_last, &counter) != AuthResult::Ok) {
            st = AckStatus::AuthFailed;
        } else {
            auth_last = counter;
            store::set_auth_counter(counter);
        }
    }
    if (st == AckStatus::Ok) {
        switch (op) {
            case Opcode::Identify: {
                uint16_t d = cmd.args_len >= 2 ? get16(cmd.args) : 10;
                identifying = d > 0;
                identify_until = now_ms() + uint32_t(d) * 1000u;
                schedule_heartbeat();
                break;
            }
            case Opcode::SetConfig:
                st = apply_config(cmd.args, cmd.args_len);
                break;
            case Opcode::GetConfig: {
                size_t n = serialize_config_tlv(cfg, ack + 2, sizeof ack - 2);
                if (n) ack_len += n;
                else st = AckStatus::InternalError;
                break;
            }
            case Opcode::Relay:
                if (cmd.args_len < 1 || cmd.args[0] > 2) {
                    st = AckStatus::InvalidArg;
                } else {
                    set_relay_mode(cmd.args[0]);
                    ack[ack_len++] = relay.heartbeat_bits();
                }
                break;
            case Opcode::Maintenance:
                enter_maintenance(cmd.args_len >= 2 ? get16(cmd.args) : 0);
                break;
            // restart after the dongle's last retransmission (450 ms, PROTOCOL 6.2): a
            // repeat lands in the history and is not executed a second time
            case Opcode::Reboot:
                reboot_at = now_ms() + kRebootDelayMs;
                break;
            case Opcode::FactoryReset:
                if (cmd.args_len < 4 || get32(cmd.args) != kFactoryResetConfirm) st = AckStatus::InvalidArg;
                else { factory_at_reboot = true; reboot_at = now_ms() + kRebootDelayMs; }
                break;
            default:
                st = AckStatus::UnknownOpcode;
        }
    }
    ack[0] = cmd.opcode;
    ack[1] = uint8_t(st);
    if (st != AckStatus::Ok) ack_len = 2;
    // an authentication failure is not remembered: a forged packet carrying the next
    // cmd_id would otherwise block the genuine command (answered from the history)
    if (st != AckStatus::AuthFailed) history.remember(h.seq, ack, ack_len);
    send_packet(MsgType::Ack, h.net_id, kNoUniverse, h.seq, ack, ack_len);
}

// --- packets --------------------------------------------------------------------------
void on_dmx(const radio::Packet& p, const Header& h) {
    if (h.universe != cfg.universe) return;
    int8_t r = p.rssi;
    if (!rssi_init) { rssi_x8 = int16_t(r) * 8; rssi_init = true; }
    else rssi_x8 = int16_t(rssi_x8 + r - rssi_x8 / 8);
    Reassembler::Result res = reasm.feed(h.seq, h.offset, h.length, h.flags, p.data + kHeaderSize);
    if (res == Reassembler::Result::None) return;
    loss.on_frame(h.seq);
    std::memcpy(frame, reasm.frame(), kDmxSlots);
    frame_len = reasm.frame_len();
    stream_ms = now_ms();
    if (!have_stream) schedule_heartbeat();
    have_stream = true;
    if (blackout) { blackout = false; dmx_out::set_blackout(false); }
    dmx_out::set_frame(frame, frame_len);
    if (fp.relay_slot >= 0) relay.dmx_level(fp.relay_slot < frame_len ? frame[fp.relay_slot] : 0, now_ms());
    update_pwm();
}

void on_packet(const radio::Packet& p) {
    Header h = decode_header(p.data);
    uint32_t now = now_ms();
    if (ota_pending_verify) {   // the new image works: keep it
        esp_ota_mark_app_valid_cancel_rollback();
        ota_pending_verify = false;
    }
    if (cfg.net_id == 0 || h.net_id == cfg.net_id) {
        net_seen_ms = now;
        if (scanning) {   // found our network again (A5): adopt the channel
            scanning = false;
            if (cfg.radio_channel != radio::channel()) {
                cfg.radio_channel = radio::channel();
                store::save_config(cfg);
            }
            schedule_heartbeat();
        }
        if (h.type != uint8_t(MsgType::Heartbeat) && h.type != uint8_t(MsgType::Ack)) {
            if (!dongle_known || std::memcmp(dongle, p.src, 6) != 0) schedule_heartbeat();
            std::memcpy(dongle, p.src, 6);
            dongle_known = true;
            dongle_seen_ms = now;
        }
    }
    switch (MsgType(h.type)) {
        case MsgType::DmxData: on_dmx(p, h); break;
        case MsgType::Command: handle_command(p, h); break;
        default: break;   // BEACON: dongle learnt above; HEARTBEAT/ACK of other nodes ignored
    }
}

// --- maintenance, button, LED ------------------------------------------------------------
void status_text(char* out, size_t cap) {
    snprintf(out, cap,
             "MAC %02X:%02X:%02X:%02X:%02X:%02X  firmware %u.%u.%u\n"
             "variante %s, univers %u, adresse %u, trame DMX %u canaux\n"
             "canal radio %u, reseau %u, dongle %s, flux DMX %s\n"
             "trames recues %lu, perdues %lu, rejetees %lu, RSSI %d dBm\n"
             "relais %s%s, %lu commutations, en marche depuis %lu s",
             mac[0], mac[1], mac[2], mac[3], mac[4], mac[5], kFw[0], kFw[1], kFw[2],
             variant == Variant::WithStrips ? "rubans" : "projecteur seul", cfg.universe, cfg.start_address,
             cfg.dmx_out_slots, radio::channel(), cfg.net_id, dongle_known ? "connu" : "absent",
             have_stream ? "present" : "absent", (unsigned long)loss.rx_frames(), (unsigned long)loss.lost_frames(),
             (unsigned long)radio::rejected(), rssi_x8 / 8, relay.state() ? "allume" : "eteint",
             relay.forced() ? " (force)" : "", (unsigned long)relay.switch_count(), (unsigned long)uptime_s());
}

void enter_maintenance(uint16_t timeout_s) {
    if (scanning) {   // back to the configured channel before the AP starts on it
        scanning = false;
        radio::set_channel(cfg.radio_channel);
    }
    maint::Hooks hk;
    hk.apply_config = apply_config;
    hk.config = []() -> const NodeConfig& { return cfg; };
    hk.status_text = status_text;
    hk.relay = set_relay_mode;
    maint::start(cfg, timeout_s, hk);
    schedule_heartbeat();
    // the USB console (J3, off mains) is the physical way to read the password (SPEC 4.9)
    Serial.printf("dmxnow: maintenance, AP dmxnow-%s, password %s, http://192.168.4.1/\n", cfg.name,
                  cfg.maint_password);
}

void poll_button(uint32_t now) {
    bool raw = digitalRead(board::kButton) == LOW;
    if (raw != btn_raw) { btn_raw = raw; btn_raw_since = now; }
    if (now - btn_raw_since < kButtonDebounceMs) return;   // 20 ms software debounce
    if (raw && !btn_down) {
        btn_down = true;
        btn_since = now;
        btn_reset_done = false;
    } else if (raw && btn_down && !btn_reset_done && now - btn_since >= kButtonResetMs) {
        btn_reset_done = true;   // >= 10 s: factory reset (net_key and password included)
        factory_at_reboot = true;
        reboot_at = now;
    } else if (!raw && btn_down) {
        btn_down = false;
        uint32_t held = now - btn_since;
        if (!btn_reset_done && held >= kButtonMaintMs) {   // >= 3 s: maintenance toggle
            if (maint::active()) maint::stop();
            else enter_maintenance(0);
            schedule_heartbeat();
        }
    }
}

void update_status_led(uint32_t now) {
    if (!cfg.status_led) return;
    bool on;
    if (identifying) on = (now / 500) % 2 == 0;
    else if (maint::active()) on = (now / 100) % 2 == 0;            // 5 Hz
    else if (have_stream) on = true;                                  // fixed: DMX stream
    else if (dongle_known) on = (now / 500) % 2 == 0;                // 1 Hz: network, no stream
    else { uint32_t t = now % 1000; on = t < 100 || (t >= 200 && t < 300); }   // double flash
    digitalWrite(board::kStatusLed, on ? HIGH : LOW);
}

void random_password(NodeConfig* c) {
    static const char kChars[] = "abcdefghijkmnpqrstuvwxyzABCDEFGHJKLMNPQRSTUVWXYZ23456789";
    for (int i = 0; i < 12; ++i) c->maint_password[i] = kChars[esp_random() % (sizeof kChars - 1)];
    c->maint_password[12] = 0;
    c->maint_password_len = 12;
}
}  // namespace

// ------------------------------------------------------------------------------------------
void setup() {
    // 1. PWM outputs low before anything else (SPEC 4.7), relay open
    pwm_out::early_off();
    pinMode(board::kRelay, OUTPUT);
    digitalWrite(board::kRelay, LOW);
    // 2. variant (EF-07): BOARD_SENSE low = strip part present
    pinMode(board::kBoardSense, INPUT_PULLUP);
    delayMicroseconds(50);
    variant = digitalRead(board::kBoardSense) == LOW ? Variant::WithStrips : Variant::FixtureOnly;
    pinMode(board::kButton, INPUT_PULLUP);

    Serial.begin(115200);
    esp_read_mac(mac, ESP_MAC_WIFI_STA);
    store::begin();
    cfg = default_config(mac);
    store::load_config(&cfg);
    if (cfg.maint_password_len == 0) {   // random, never derived from the MAC (SPEC 4.9)
        random_password(&cfg);
        store::save_config(cfg);
    }
    auth_last = store::auth_counter();
    if (cfg.status_led) pinMode(board::kStatusLed, OUTPUT);

    // relay: power-on state (A2 / SPEC 4.5)
    bool last_state;
    uint32_t count;
    store::load_relay(&last_state, &count);
    relay.begin(cfg.relay_power_on, last_state, cfg.relay_dmx, cfg.relay_min_interval_ms, now_ms());
    relay.set_switch_count(count);

    dmx_out::begin(cfg.dmx_out_slots);
    configure_outputs();
    if (variant == Variant::WithStrips) start_fade();

    const esp_partition_t* running = esp_ota_get_running_partition();
    esp_ota_img_states_t st;
    ota_pending_verify = esp_ota_get_state_partition(running, &st) == ESP_OK && st == ESP_OTA_IMG_PENDING_VERIFY;

    if (!radio::begin(cfg.radio_channel, cfg.net_id)) Serial.println("dmxnow: radio init failed");

    // three power-ups less than 5 s apart -> maintenance (A6, option). Only real power-ups
    // count: a crash, watchdog, brownout or commanded reboot loop must not open the AP.
    if (cfg.powercycle_maint && esp_reset_reason() != ESP_RST_POWERON) {
        if (store::boot_count()) store::set_boot_count(0);
    } else if (cfg.powercycle_maint) {
        uint8_t n = uint8_t(store::boot_count() + 1);
        if (n >= 3) {
            store::set_boot_count(0);
            enter_maintenance(0);
        } else {
            store::set_boot_count(n);
        }
    }
    net_seen_ms = now_ms();
    schedule_heartbeat();
    Serial.printf("dmxnow node %u.%u.%u, %s, universe %u, channel %u\n", kFw[0], kFw[1], kFw[2],
                  variant == Variant::WithStrips ? "strips" : "fixture only", cfg.universe, cfg.radio_channel);
    Serial.printf("dmxnow: name %s, maintenance password %s\n", cfg.name, cfg.maint_password);
}

void loop() {
    static radio::Packet pkt;   // 1.5 kB: not on the loop task stack
    if (radio::receive(&pkt, 2)) on_packet(pkt);
    uint32_t now = now_ms();

    if (relay.update(now)) apply_relay_gpio();

    // stream presence and optional blackout (EF-06: the relay is never affected)
    if (have_stream && now - stream_ms > kStreamPresentMs) {
        have_stream = false;
        schedule_heartbeat();
    }
    if (cfg.loss_blackout_ms && frame_len && !blackout && now - stream_ms > cfg.loss_blackout_ms) {
        blackout = true;
        dmx_out::set_blackout(true);
        update_pwm();
    }

    if (identifying && time_reached(now, identify_until)) {
        identifying = false;
        schedule_heartbeat();
    }
    apply_identify_dmx();
    if (identifying || fading) update_pwm();

    if (dongle_known && now - dongle_seen_ms > kDongleForgetMs) dongle_known = false;

    // channel scan after 60 s without our network (A5); DMX output goes on meanwhile.
    // A new node (net_id 0) scans too, for any BEACON or COMMAND: otherwise it stays on
    // channel 6 and cannot be enrolled by a dongle on another channel. Never in
    // maintenance: the access point must stay on its channel.
    if (!maint::active() && !scanning && now - net_seen_ms > kScanAfterMs) {
        scanning = true;
        scan_ch = 0;
        scan_step_ms = now;
    }
    if (scanning && !maint::active() && time_reached(now, scan_step_ms)) {
        scan_ch = uint8_t(scan_ch % 13 + 1);
        radio::set_channel(scan_ch);
        scan_step_ms = now + kScanDwellMs;
    }

    // channel change asked by a command or the web page: 500 ms after the answer, and
    // only out of maintenance (moving the channel would drop the AP's clients)
    if (channel_at && !maint::active() && time_reached(now, channel_at)) {
        channel_at = 0;
        radio::set_channel(channel_new);
    }

    if (time_reached(now, next_hb_ms) && !scanning) {
        send_heartbeat();
        next_hb_ms = now + kHeartbeatMs - kHeartbeatJitterMs + esp_random() % (2 * kHeartbeatJitterMs + 1);
    }

    if (!boot_counter_cleared && now > kPowerCycleWindowMs) {
        boot_counter_cleared = true;
        if (cfg.powercycle_maint) store::set_boot_count(0);
    }
    if (ota_pending_verify && now > kOtaValidateMs) {
        esp_ota_mark_app_invalid_rollback_and_reboot();   // no valid packet in 60 s
    }

    poll_button(now);
    maint::loop();
    update_status_led(now);

    if (reboot_at && time_reached(now, reboot_at)) {
        if (factory_at_reboot) store::factory_reset();
        ESP.restart();
    }
}

}  // namespace node

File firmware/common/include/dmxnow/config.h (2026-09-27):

// Node configuration, TLV codec and DMX footprint (PROTOCOL §6.4).
#pragma once
#include <cstddef>
#include <cstdint>

#include "dmxnow/protocol.h"

namespace dmxnow {

namespace key {
constexpr uint8_t kUniverse = 0x01, kStartAddress = 0x02, kName = 0x03, kRadioChannel = 0x04,
                  kRelayDmx = 0x05, kRelayPowerOn = 0x06, kRelayMinIntervalMs = 0x07,
                  kLossBlackoutMs = 0x08, kPwmMode = 0x09, kGammaX10 = 0x0A, kFadeOnMs = 0x0B,
                  kPwmFreqHz = 0x0C, kDmxOutSlots = 0x0D, kIdentifySlot = 0x0E, kNetId = 0x0F,
                  kMaintPassword = 0x10, kNetKey = 0x11, kPowercycleMaint = 0x12, kStatusLed = 0x13;
constexpr uint8_t kMax = 0x13;
}  // namespace key

enum class Variant : uint8_t { FixtureOnly = 1, WithStrips = 2 };

struct NodeConfig {
    uint16_t universe = 0;
    uint16_t start_address = 1;
    char name[17] = {};                 // NUL terminated, 1..16 bytes
    uint8_t radio_channel = 6;
    uint8_t relay_dmx = 1;
    uint8_t relay_power_on = 2;         // 0 off, 1 on, 2 last state
    uint16_t relay_min_interval_ms = 3000;
    uint32_t loss_blackout_ms = 0;
    uint8_t pwm_mode = 0;               // 0 = 8 bit, 1 = 16 bit
    uint8_t gamma_x10 = 22;
    uint16_t fade_on_ms = 500;
    uint16_t pwm_freq_hz = 4882;
    uint16_t dmx_out_slots = 512;
    uint16_t identify_slot = 0;
    uint16_t net_id = 0;
    uint8_t maint_password_len = 0;
    char maint_password[33] = {};
    bool has_net_key = false;
    uint8_t net_key[32] = {};
    uint8_t powercycle_maint = 1;
    uint8_t status_led = 0;
};

// Defaults, with name = "node-XXXXXX" (last 3 MAC bytes, upper-case hex).
NodeConfig default_config(const uint8_t mac[6]);

// DMX footprint from start_address: relay slot (if relay_dmx), then PWM1..4 (8 bit) or
// PWM1 MSB, PWM1 LSB ... PWM4 LSB (16 bit) on the strip variant.
struct Footprint {
    int relay_slot = -1;        // 0-based channel index, -1 = none
    int pwm_first = -1;         // 0-based index of PWM1 (MSB), -1 = none
    uint8_t pwm_count = 0;      // 4 or 0
    bool pwm16 = false;
    uint16_t size = 0;          // 0, 1, 4, 5, 8 or 9 channels
};
Footprint footprint(const NodeConfig& c, Variant v);

// PWM channel value (0..65535) from a DMX frame; 8-bit values are scaled v * 257.
uint16_t pwm_value(const Footprint& f, const uint8_t* frame, uint16_t frame_len, uint8_t channel);

// Iterates TLV items; returns false on a malformed list (truncated item).
template <typename F>
bool tlv_for_each(const uint8_t* p, size_t len, F&& fn) {
    size_t i = 0;
    while (i < len) {
        if (i + 2 > len) return false;
        uint8_t k = p[i], l = p[i + 1];
        if (i + 2 + l > len) return false;
        fn(k, p + i + 2, l);
        i += 2 + size_t(l);
    }
    return true;
}

// Applies a SET_CONFIG TLV list atomically: every item is checked (known key, length,
// range, final start_address against the footprint) before anything is changed.
// On success *changed gets one bit per key (bit k), and cfg is updated.
AckStatus apply_config_tlv(const uint8_t* tlv, size_t len, Variant v, NodeConfig* cfg, uint32_t* changed);

// GET_CONFIG: every key except the write-only secrets (0x10, 0x11). Returns the size
// written, 0 if out_cap is too small.
size_t serialize_config_tlv(const NodeConfig& c, uint8_t* out, size_t out_cap);

bool utf8_valid(const uint8_t* s, size_t n);

}  // namespace dmxnow

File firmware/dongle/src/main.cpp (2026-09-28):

// dmxnow dongle (SPEC 4.10, PROTOCOL 4, 6, 8): USB CDC link to the Pi daemon (COBS
// frames) <-> ESP-NOW v2 broadcast to the nodes. The logic (universes, cadence,
// hold_timeout, command retransmissions, priorities) is in firmware/common/dongle.cpp
// and tested natively; this file only wires it to USB, ESP-NOW and NVS.
#include <Arduino.h>
#include <Preferences.h>
#include <WiFi.h>
#include <esp_now.h>
#include <esp_timer.h>
#include <esp_wifi.h>
#include <freertos/queue.h>

#include <atomic>
#include <cstring>

#include "dmxnow/dongle.h"
#include "dmxnow/protocol.h"
#include "dmxnow/serial.h"

using namespace dmxnow;

namespace {

constexpr uint8_t kFw[3] = {DMXNOW_FW_MAJOR, DMXNOW_FW_MINOR, DMXNOW_FW_PATCH};
constexpr int kTxProbePin = D10;             // toggles at each emission (latency probe, ENF-01)
constexpr uint32_t kStatusPeriodMs = 5000;
constexpr uint32_t kSendCallbackTimeoutMs = 50;
const uint8_t kBroadcast[6] = {0xFF, 0xFF, 0xFF, 0xFF, 0xFF, 0xFF};

DongleSettings settings;
Preferences prefs;
Scheduler sched;
SerialDecoder decoder;
uint8_t tx_seq = 0;           // serial frames to the Pi
uint16_t beacon_seq = 0;
uint32_t next_status_ms = 0;

// transmission in progress (one packet at a time, SPEC 4.10)
std::atomic<bool> tx_busy{false};
uint32_t tx_started_ms = 0;
std::atomic<uint32_t> tx_ok{0}, tx_fail{0};
bool probe = false;

// fragmented v1 mode: remaining fragments of the universe being sent
uint8_t frag_buf[3][kMaxPacketV1];
size_t frag_len[3];
uint8_t frag_count = 0, frag_next = 0;

struct RxItem {
    uint16_t len;
    int8_t rssi;
    uint8_t src[6];
    uint8_t data[kMaxPacketV1];   // HEARTBEAT / ACK only (< 250 bytes)
};
QueueHandle_t rx_queue;
RxItem rx_slot;

// --- serial to the Pi -----------------------------------------------------------------
void send_pi(uint8_t type, const uint8_t* payload, size_t len) {
    static uint8_t wire[ser::kMaxFrame + ser::kMaxFrame / 254 + 4];
    size_t n = serial_encode(type, tx_seq++, payload, len, wire, sizeof wire);
    if (n) Serial.write(wire, n);
}


// LOG to the Pi (PROTOCOL 8.4): level 0 error ... 3 debug, UTF-8 text. Every refusal is
// reported, so that a misconfiguration never stays silent.
void send_log(uint8_t level, const char* text) {
    uint8_t buf[120];
    buf[0] = level;
    size_t n = strnlen(text, sizeof buf - 1);
    std::memcpy(buf + 1, text, n);
    send_pi(ser::kLog, buf, n + 1);
}

void send_status() {
    uint8_t p[32];
    std::memcpy(p, kFw, 3);
    p[3] = settings.channel;
    put16(p + 4, settings.net_id);
    p[6] = settings.phy_rate;
    p[7] = settings.mode;
    p[8] = sched.universes.active();
    put32(p + 9, tx_ok.load());
    put32(p + 13, tx_fail.load());
    put32(p + 17, decoder.errors());
    put32(p + 21, sched.universes.coalesced());
    put32(p + 25, uint32_t(esp_timer_get_time() / 1000000));
    send_pi(ser::kStatus, p, 29);
}

// --- radio ----------------------------------------------------------------------------
void on_sent(const esp_now_send_info_t*, esp_now_send_status_t status) {
    if (status == ESP_NOW_SEND_SUCCESS) ++tx_ok;
    else ++tx_fail;
    tx_busy = false;
}

void on_recv(const esp_now_recv_info_t* info, const uint8_t* data, int len) {
    // Wi-Fi task: checks and a copy only. HEARTBEAT and ACK are forwarded to the Pi.
    if (len <= 0 || size_t(len) > sizeof rx_slot.data) return;
    Header h;
    if (validate_dongle(data, size_t(len), settings.net_id, &h) != Reject::None) return;
    if (h.type != uint8_t(MsgType::Heartbeat) && h.type != uint8_t(MsgType::Ack)) return;
    rx_slot.len = uint16_t(len);
    rx_slot.rssi = info->rx_ctrl ? int8_t(info->rx_ctrl->rssi) : 0;
    std::memcpy(rx_slot.src, info->src_addr, 6);
    std::memcpy(rx_slot.data, data, size_t(len));
    xQueueSend(rx_queue, &rx_slot, 0);
}

void apply_radio() {
    esp_wifi_set_channel(settings.channel, WIFI_SECOND_CHAN_NONE);
    esp_wifi_set_max_tx_power(int8_t(settings.power_dbm * 4));
    esp_now_rate_config_t rc = {};
    rc.phymode = settings.phy_rate <= 0x07 ? WIFI_PHY_MODE_11B : WIFI_PHY_MODE_11G;
    rc.rate = wifi_phy_rate_t(settings.phy_rate);
    if (esp_now_set_peer_rate_config(kBroadcast, &rc) != ESP_OK)
        send_log(0, "PHY rate refused by ESP-NOW: previous rate kept");
    sched.universes.set_refresh_hz(settings.refresh_hz);
}

bool radio_send(const uint8_t* pkt, size_t len) {
    tx_busy = true;
    tx_started_ms = millis();
    if (esp_now_send(kBroadcast, pkt, len) != ESP_OK) {
        tx_busy = false;
        ++tx_fail;
        return false;
    }
    probe = !probe;
    digitalWrite(kTxProbePin, probe ? HIGH : LOW);
    return true;
}

void emit_universe(UniverseTable::Universe* u) {
    Header h;
    h.type = uint8_t(MsgType::DmxData);
    h.net_id = settings.net_id;
    h.universe = u->id;
    h.seq = u->seq;
    if (settings.mode == 0) {   // v2: the whole universe in one packet (PROTOCOL 4.1)
        static uint8_t pkt[kHeaderSize + kDmxSlots];
        h.flags = flags::kLast;
        size_t n = build_packet(h, u->data, u->len, nullptr, pkt, sizeof pkt);
        if (n) radio_send(pkt, n);
        return;
    }
    // v1 fallback: fragments of 232 channels, same seq, sent back to back (PROTOCOL 4.2)
    frag_count = 0;
    for (uint16_t off = 0; off < u->len && frag_count < 3; off += uint16_t(kMaxFragPayload)) {
        uint16_t n = uint16_t(u->len - off < kMaxFragPayload ? u->len - off : kMaxFragPayload);
        h.offset = off;
        h.flags = uint8_t(flags::kFrag | (off + n >= u->len ? flags::kLast : 0));
        frag_len[frag_count] = build_packet(h, u->data + off, n, nullptr, frag_buf[frag_count], kMaxPacketV1);
        ++frag_count;
    }
    frag_next = 0;
    if (frag_count) {
        radio_send(frag_buf[0], frag_len[0]);
        frag_next = 1;
    }
}

void emit_beacon() {
    Header h;
    h.type = uint8_t(MsgType::Beacon);
    h.net_id = settings.net_id;
    h.universe = kNoUniverse;
    h.seq = beacon_seq++;
    Beacon b;
    std::memcpy(b.fw_version, kFw, 3);
    b.active_universes = sched.universes.active();
    b.uptime_s = uint32_t(esp_timer_get_time() / 1000000);
    uint8_t p[kBeaconPayload], pkt[kHeaderSize + kBeaconPayload];
    encode_beacon(b, p);
    size_t n = build_packet(h, p, sizeof p, nullptr, pkt, sizeof pkt);
    if (n) radio_send(pkt, n);
}
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

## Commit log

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2026-09-25 hardware: source du design, empreintes provisoires et schéma généré
    design.py (composants et nets), bibliothèques (empreintes G5RL et WAGO 2604
    provisoires, ESP32-C3-MINI-1 d'Espressif), générateur de schéma et contrôle
    de netlist (42 nets conformes).
    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
    [dmxnow.kicad_sch]
2026-09-26 hardware: générateur PCB, règles 230 V, CI KiCad 9, relecture
    PE hors carte (arbitrage A9) : borniers 230 V en 2 pôles. Carte 146 x 54 mm.
    Placement et routage 230 V/LED scriptés, routage signaux par Freerouting,
    règles DRC d'isolement, contrôles de cohérence, sorties JLCPCB, workflow CI
    KiCad 9 et liste de relecture humaine.
    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
    [dmxnow.kicad_sch]
2026-09-26 hardware: PCB placé et routé en 230 V/LED (signaux BT non routés, WIP)
    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
    [dmxnow.kicad_pcb]
2026-09-26 hardware: bibliothèques figées, barrière de découpe pour le routeur, vias de couture
    Symboles et empreintes KiCad utilisés copiés dans lib/vendor (KiCad 9 a
    supprimé Device:Q_NMOS_GDS). Fils fixes pour les seuls nets autorisés à
    traverser la découpe, piste VLED fixe, couture GND après routage.
    PCB en cours de routage (WIP).
    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
    [dmxnow.kicad_sch]
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2026-09-26 hardware: PCB routé, passe de finition, sorties JLCPCB
    Routage basse tension par Freerouting (session enregistrée dans
    hardware/route/), passe de finition (mini-routeur A*, vias d'îlots,
    nettoyage), contrôles : 0 liaison manquante, 0 violation au DRC local,
    cohérence netlist/PCB/découpe. Pull-downs PWM côté principal, liaisons
    0 ohm R20/R21 à la place des ponts de cuivre. Gerbers, perçages, V-cut,
    BOM/CPL JLCPCB (base et option LED).
    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
    [bom_full.csv, bom_jlcpcb_base.csv, bom_jlcpcb_led.csv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]
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2026-09-26 hardware: relais G5RL-1A-E-HR, cotes WAGO 2604 et IRM-03 vérifiées sur fiches
    - K1 : G5RL-U1A-E (bistable, incompatible avec la commande MOSFET) remplacé par
    G5RL-1A-E-HR DC5 (LCSC C113250), même implantation ; corps 29,0 x 12,7 mm.
    - WAGO 2604 : rangées de broches à 8,2 mm (au lieu de 6), corps 16,3 mm + levier
    2,9 mm, largeur (n-1) x 5 + 7,4 mm, pastilles 1,9 x 2,8 mm.
    - Placement : J1/J4/J7 décalés de 0,7 mm vers le bord (3 mm entre le bus N et les
    pastilles L_SW), J6 et canaux de 0,5 mm, H3 de 0,5 mm (chevauchement de courtyard).
    - PS1 : empreinte KiCad IRM-03 conforme à la fiche Mean Well 2025-08-08.
    - Références LCSC ajoutées (K1, WAGO 2604-1102, IRM-03-5).
    - SPEC (4.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
    [bom_full.csv, dmxnow.kicad_pcb, dmxnow.kicad_sch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]
2026-09-26 hardware: références LCSC complètes et vérifiées, estimation de coût
    - Codes LCSC ajoutés pour toutes les pièces montées (U1, D1, U4, Q2-Q5, D3, SW1,
    F1, F2, RV1, C1, C7, C8, D4, J6) ; stock et prix relevés via l'API JLCPCB.
    - F1 : Littelfuse 37405000410 (hors stock) remplacé par 37205000001 (C142835),
    même série TR5 372. U2 : MPN corrigé en SP3485EN-L/TR (C8963).
    - WAGO 2604-1105 (J6) en rupture chez LCSC : noté dans la BOM.
    - SPEC §6 : coût composants ≈ 33 $ à l'unité, ≈ 28 $ par nœud en série de 20.
    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
    [bom_full.csv, bom_jlcpcb_base.csv, bom_jlcpcb_led.csv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]
2026-09-26 hardware: rév. 0.3 après revue de conception (3 relecteurs indépendants)
    Bloquants corrigés :
    - V-cut remplacé par une fente fraisée + 3 languettes perforées : la rainure
    V aurait coupé en fabrication les 7 pistes qui traversent la découpe, et
    JLCPCB refuse le V-cut sous 70 x 70 mm (ADR 0007 amendé).
    - Fichiers de placement convertis aux conventions JLCPCB (SOT-23, SOT-23-5,
    SOIC, TO-252, ESP32-C3-MINI-1, centres des traversants) ; variantes BOM/CPL
    « full » (CMS + traversants) et « smt ».
    - F1 : fusible céramique 5x20 T500mA H (1500 A) dans un support Schurter
    0031.8201, placé dans une bande de 10 mm ajoutée au-dessus de la zone 230 V.
    - R15-R18 4,7k : GPIO6 (PWM1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
    [bom_full.csv, bom_jlcpcb_full.csv, bom_jlcpcb_full_led.csv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]
2026-09-26 hardware: seconde passe de revue (rév. 0.3b)
    Corrections issues de la seconde revue indépendante :
    - CPL : Q2-Q5 (AOD2610E, C282428) tournés de 180° (empreinte JLC : languette
    à gauche) ; centres des WAGO 2604 = centre du réseau de broches.
    - Broche NC de PS1 : règle DRC ps1_nc_pin (6 mm depuis le bord de la
    pastille), zone interdite agrandie, J2 décalé de 1 mm.
    - DRC canary (gen/drc_canary.py, make check et CI KiCad 9) : des défauts
    injectés doivent déclencher chaque règle 230 V personnalisée.
    - insideCourtyard -> intersectsCourtyard (KiCad 7 à 9).
    - Languette B raccourcie et mieux perforée, vias OE de U4 et de R20 à
    >= 0,25 mm des pastilles, col VLED élargi, RV1 d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
    [dmxnow.kicad_pcb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]
2026-09-26 hardware: troisième passe de revue (RV1, canari KiCad 9, centre K1)
    - RV1 : empreinte du projet, perçage 1,1 mm (pattes 0,8 +-0,1 mm, le 0,8 mm
    de KiCad était trop juste avec la tolérance JLCPCB) et corps jusqu'à 9 mm
    d'épaisseur (fiche HEL 10D) ; RV1 décalé à X = 28,5, bus L_SW raccourci.
    - drc_canary.py : constante d'unités renommée dans KiCad 9 (échec CI).
    - CPL : centre de K1 = centre des broches (empreinte JLC).
    - REVIEW.md : RV1, découplage 3V3 et pistes d'alimentation à 0,2 mm,
    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
    [bom_full.csv, bom_jlcpcb_full.csv, bom_jlcpcb_full_led.csv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]
2026-09-26 ci: canari DRC via kicad-cli (KiCad 9), format de rapport KiCad 8+ accepté
    Le canari ne reconnaissait pas le format « Rule: <nom>; error » des rapports
    KiCad 8+ ; il utilise désormais le même moteur que l'étape DRC de la CI
    (kicad-cli pcb drc) et affiche le rapport en cas d'échec.
    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
    [drc_canary.py]
2026-09-26 hardware: quatrième passe de revue (PS1, RV1, J6, fentes, marquages)
    - PS1 : empreinte du projet, perçages 1,0 mm (broches 0,6 +-0,1 mm).
    - RV1 : classé traversant (il figurait dans la BOM CMS), centre CPL entre
    les pattes.
    - J6 (0 stock JLCPCB) retiré des fichiers d'assemblage JLCPCB, signalé dans
    bom_full.csv.
    - Fentes d'isolement 1,2 mm à bouts arrondis ; bande F1 portée à 11,5 mm
    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
    [bom_full.csv, bom_jlcpcb_full.csv, bom_jlcpcb_full_led.csv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]
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2026-09-26 hardware: cinquième passe de revue (J3 +5V, LED rouge, R15-R18, notes de commande)
    - J3 passe à 7 pastilles : +5V (entrée de U3) pour programmer hors secteur sans
    réalimenter la sortie de l'AP2112K ; marquages 3V3 / 5V
    - D4 LED rouge KT-0603R (C2286) + R19 330R : une LED verte VF 3,1 V ne s'allume pas
    - R15-R18 décalées de 0,5 mm (4 mm sans composant de chaque côté de la découpe)
    - marquages J2 en 1,0 mm ; références F1 / F2 ramenées sur la carte
    - vias d'îlot : anneau entier dans les deux plans (plus de via à cheval sur un bord)
    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
    [bom_full.csv, bom_jlcpcb_full_led.csv, bom_jlcpcb_smt_led.csv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]
2026-09-26 hardware: J6 WAGO 2604-1105 (arrêté) remplacé par 2604-1102 + 2604-1103
    Le 2604-1105 est « Discontinued » chez WAGO et à 0 chez JLCPCB. J6 devient
    un 2604-1102 (VLED, CH1) et J8 un 2604-1103 (CH2-CH4), tous deux en stock et
    de nouveau dans les fichiers d'assemblage JLCPCB.
    - Blocs juxtaposés : 7,4 mm entre broches voisines d'après la fiche
    (L = (n - 1) x 5 + 7,4 mm) ; 8,0 mm au PCB (CH1 y 28,5 -> CH2 y 20,5).
    CH2-CH4 inchangés ; VLED et CH1 descendent de 3 mm.
    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
    [bom_full.csv, bom_jlcpcb_full.csv, bom_jlcpcb_full_led.csv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]
2026-09-26 enclosure: boîtier CadQuery paramétrique (livrable 8.6)
    Modèle unique, variantes carte entière et carte cassée, exports STEP
    (assemblage) et STL (position d'impression), rendus PNG.
    - Géométrie tirée du PCB : hardware/gen/export_board.py -> enclosure/board.json
    (contour, fentes, trous, encombrement + hauteur de chaque composant, points
    d'appui), vérifiée en CI.
    - Fond, couvercle 230 V vissé (borniers + jonction PE, recouvre le bord du
    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
    [base.step, base.stl, clamp_bar.step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]
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2026-09-27 hardware: sérigraphie nettoyée, tronçons de languettes raccourcis (DRC sans avertissement sous KiCad 9)
    - Références placées automatiquement hors des pastilles, des bords et des
    fentes (petits composants d'abord) ; C7, F1, F2 à position fixe.
    - Contours de sérigraphie des empreintes coupés au bord de carte et aux
    fentes (0,3 mm).
    - Repères de pôles J6/J8 décalés pour laisser Q2-Q5 près de leur boîtier.
    - fixup : tronçons de traversée ramenés à la partie raccordée (plus de bout
    de piste en attente).
    - export_board : listes triées (board.json stable d'une version de KiCad
    à l'autre).
    - ENF-05 : taille du boîtier acceptée (2026-09-27).
    Contrôles : netlist 0, PC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
    [dmxnow.kicad_pcb]
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2026-09-27 firmware/node : firmware du nœud ESP32-C3 (livrable 8.3) et CI firmware
    pioarduino 55.03.312 épinglé (Arduino-ESP32 3.3.12 / ESP-IDF 5.5.5) :
    - réception ESP-NOW v2, validation dans le callback puis copie en file ;
    - sortie DMX UART1 (break 176 us par inversion de ligne, MAB 12 us,
    250 kbit/s 8N2, dmx_out_slots), émission sur événement + 44 Hz ;
    - relais (priorités, anti-rebond différé, NVS à la commutation),
    PWM LEDC 14 bits déphasé d'un quart de période, gamma, fondu, PWM à 0
    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
    [partitions.csv]
2026-09-27 enclosure: boîtier imprimé du dongle XIAO ESP32-C3
    Boîtier de la XIAO ESP32-C3 et de son antenne FPC fournie (40 x 20 mm),
    retenu plutôt qu'une clé USB-A du commerce pour garder l'antenne externe.
    80 x 25 x 9 mm : ouverture USB-C avec lamage, nervures et butée du XIAO,
    antenne à 7 mm de la carte, couvercle clipsé, languette d'accroche.
    PETG ou PLA (5 V seulement). Vérifications : solides valides, aucune
    collision avec la carte ni l'antenne. STEP, STL orientés et rendus dans
    enclosure/out/dongle.
    SPEC 4.10 : décision et référence d'achat ; V-ENC-04 : cotes du XIAO à
    mesurer. make check / export / render incluent le dongle.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
    [lid.step, lid.stl, tray.step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]
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2026-09-27 pi : démon dmxnowd, CLI dmxnow et installeur (livrable 8.5)
    - Art-Net : ArtDmx vers le dongle, ArtPoll -> ArtPollReply (4 univers par
    réponse, BindIndex au-delà).
    - Liaison dongle : pyserial dans un thread relié à asyncio, PING/PONG,
    réouverture après 3 s sans PONG ou sur débranchement, configuration radio
    poussée à chaque connexion.
    - Table des nœuds (heartbeats, dont les nœuds non enrôlés), commandes avec
    attente de l'ACK et du CMD_RESULT, signature HMAC avec compteur persistant
    strictement croissant (A4), socket de contrôle JSON ligne par ligne.
    - CLI : nodes, status, enroll, identify, set, get, relay, maintenance,
    reboot, factory-reset, dongle-config ; avertiss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
    [artnet.py, cli.py, config.py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]
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2026-09-28 Revue croisée : corrections firmware nœud, dongle et démon Pi
    Nœud
    - Sortie DMX : attente de la fin de trame avant de copier les données, une
    donnée arrivée pendant l'émission part dans la trame suivante (pire cas
    §5.1 ramené de ~57 à ~34 ms) ; réveil à 1 ms pour tenir 44 Hz.
    - Un nœud neuf (net_id 0) balaie aussi les canaux : il trouve un dongle
    réglé sur 1 ou 11 et peut être enrôlé.
    - Pas de balayage ni de changement de canal en maintenance (le point
    d'accès ne bouge plus) ; changement de canal reporté à la sortie.
    - Page de maintenance : net_id 0 n'est plus envoyé (formulaire utilisable
    sur un nœud neuf), valeurs hors plage refusées au lieu d'être tronq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
    [cli.py, config.py, daemon.py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]
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2026-09-29 pi : cmd_id tiré au hasard quand l'état du démon est perdu
    Les nœuds gardent en RAM les accusés de leurs 16 derniers cmd_id. Un démon
    qui repartait de cmd_id 0 après la perte de /var/lib/dmxnow/state.json
    recevait ces anciennes réponses pour des commandes jamais exécutées.
    State tire maintenant le cmd_id au hasard si le fichier manque ou est
    illisible. Test : test_lost_state_starts_cmd_id_at_random.
    mise-en-service.md §9.3 : le tirage à la main reste utile après la
    restauration d'une sauvegarde, qui contient un ancien cmd_id.
    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
    [config.py]
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2026-10-05 hardware: rotation de U3 (SOT-23-5) corrigée dans le CPL JLCPCB
    À la première commande, l'ingénieur JLCPCB a dû tourner U3 (AP2112K,
    C51118) de 270° à 0° : le décalage SOT-23-5 de JLC_FIX était faux. Les
    57 autres pièces du placement corrigé (bom_merge de la DFM) étaient
    identiques aux nôtres. JLC_FIX passe à 0 ; la ligne U3 des quatre CPL
    est mise à jour, vérifiée contre une régénération par gen/fab.py dans
    l'image kicad/kicad:9.0 (seul écart restant : C7 à 0,004 mm près,
    arrondi entre versions de KiCad, non repris).
    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
2026-10-13 firmware, pi: conduites stockées dans le nœud, jouées sans DMX
    Un nœud garde en flash une conduite (images clés en boucle, fondu
    linéaire) et la joue dès la mise sous tension, sur les rubans et la
    ligne DMX. QLC+ reprend la main à sa première trame, la conduite
    revient après resume_s sans flux. Le relais ne la suit jamais.
    - format .dxs, lecteur et vecteurs communs C++/Python (PROTOCOL §10)
    - partition spiffs existante, projetée en lecture : pas de changement
    de table ni de configuration NVS, la mise à jour passe par OTA
    - opcodes SHOW_WRITE, SHOW_COMMIT, SHOW_CLEAR, SHOW_INFO, bit 5 du
    heartbeat ; FACTORY_RESET efface aussi la conduite
    - CLI : dmxnow show deploy | info | c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
2026-10-15 firmware: un seul firmware pour les cartes nœud, rôle nœud ou dongle
    L'application du dongle devient la bibliothèque firmware/dongle_app, partagée par la XIAO
    et les cartes nœud. Une carte nœud devient dongle au premier PING du démon sur l'USB,
    sans redémarrer (jusqu'à l'extinction), ou par dmxnow role (rôle enregistré en NVS, hors
    du bloc de configuration). En dongle, elle sort aussi son univers sur sa XLR. Retour au
    nœud : dmxnow role dongle node. Vu au banc sur node-2442B0. Procédure : docs/roles.md.
    Une carte en rôle dongle n'est jamais raccordée au secteur.
    Claude-Session: https://claude.ai/code/session_011pzwy2hKP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
2026-10-16 firmware: SHOW_COMMIT compare le CRC du fichier entier, comme la CLI
    Depuis le premier firmware des conduites, le nœud comparait le CRC stocké en fin
    de fichier au crc32 envoyé par la CLI (zlib.crc32 du fichier entier) : chaque
    show deploy répondait FAILED, alors que la conduite, bien écrite, se chargeait
    au redémarrage suivant. Trouvé par un diagnostic dans l'ACK au banc. Le
    contournement par redémarrage du commit précédent est retiré.
    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
